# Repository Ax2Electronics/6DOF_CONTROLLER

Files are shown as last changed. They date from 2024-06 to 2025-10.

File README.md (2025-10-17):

# 6DOF_CONTROLLER
Carrier Board capable of driving up to 6 stepper motors, designed to drive 6 axis robot arm

Block Diagram
[BLOCK_DIAGRAM_V1.3.pdf](https://github.com/user-attachments/files/22972611/BLOCK_DIAGRAM_V1.3.pdf)



Power tree
[Robot Brain Current Consumption_V1.0.pdf](https://github.com/user-attachments/files/22972602/Robot.Brain.Current.Consumption_V1.0.pdf)



Schematic top overview:



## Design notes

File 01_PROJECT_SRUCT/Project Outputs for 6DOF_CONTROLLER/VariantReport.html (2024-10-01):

Altium customize

# Variant Report

Date: | | 6/29/2024
Time: | | 3:28:59 PM
Elapsed Time: | | 00:00:00

## Variations

Physical | Document | Parameter Name | Original Value | Only Populated Components
C3000 | 5V_SYS_SUPPLY.SchDoc | | Fitted | Fitted
| | capacitance | 0.1uF | 0.1uF
| | Comment | 0.1uF | 0.1uF
| | Component Kind | Standard | Standard
| | ComponentLink1Description | DigiKey | DigiKey
| | ComponentLink1URL | https://www.digikey.com/en/products/detail/samsung-electro-mechanics/CL10B104KB8NNNC/3886658 | https://www.digikey.com/en/products/detail/samsung-electro-mechanics/CL10B104KB8NNNC/3886658
| | Description | CAP CER 0.1UF 50V X7R 0603 | CAP CER 0.1UF 50V X7R 0603
| | DigiKey Part Number | 1276-1000-1-ND | 1276-1000-1-ND
| | Footprint | CAP_0603 | CAP_0603
| | Ibis Model
| | Library Name | CapacitorsIntegrated.IntLib | CapacitorsIntegrated.IntLib
| | Library Reference | C000018 | C000018
| | PCB3D
| | Pin Info
| | Signal Integrity
| | Simulation
C3001 | 5V_SYS_SUPPLY.SchDoc | | Fitted | Fitted
| | capaticanse | 220uf | 220uf
| | Comment | 220uf | 220uf
| | Component Kind | Standard | Standard
| | ComponentLink1Description | digikey | digikey
| | ComponentLink1URL | https://www.digikey.com/en/products/detail/nichicon/UCW1H221MNL1GS/2549783 | https://www.digikey.com/en/products/detail/nichicon/UCW1H221MNL1GS/2549783
| | Description | CAP ALUM 220UF 20% 50V SMD | CAP ALUM 220UF 20% 50V SMD
| | DigiKey part number | 493-9426-1-ND | 493-9426-1-ND
| | Footprint | CAPAE109103X103M | CAPAE109103X103M
| | Ibis Model
| | Library Name | CapacitorsIntegrated.IntLib | CapacitorsIntegrated.IntLib
| | Library Reference | C000019 | C000019
| | PCB3D
| | Pin Info
| | Signal Integrity
| | Simulation
C3002 | 5V_SYS_SUPPLY.SchDoc | | Fitted | Fitted
| | capacitance | 10uF | 10uF
| | Comment | 10uF | 10uF
| | Component Kind | Standard | Standard
| | ComponentLink1Description | DigiKey | DigiKey
| | ComponentLink1URL | https://www.digikey.com/en/products/detail/samsung-electro-mechanics/CL31B106KBHNNNE/5961251 | https://www.digikey.com/en/products/detail/samsung-electro-mechanics/CL31B106KBHNNNE/5961251
| | Description | CAP CER 10UF 50V X7R 1206 | CAP CER 10UF 50V X7R 1206
| | DigiKey Part Number | 1276-6767-1-ND | 1276-6767-1-ND
| | Footprint | CAP_1206 | CAP_1206
| | Ibis Model
| | Library Name | CapacitorsIntegrated.IntLib | CapacitorsIntegrated.IntLib
| | Library Reference | C000017 | C000017
| | PCB3D
| | Pin Info
| | Signal Integrity
| | Simulation
C3003 | 5V_SYS_SUPPLY.SchDoc | | Fitted | Fitted
| | capacitance | 10uF | 10uF
| | Comment | 10uF | 10uF
| | Component Kind | Standard | Standard
| | ComponentLink1Description | DigiKey | DigiKey
| | ComponentLink1URL | https://www.digikey.com/en/products/detail/samsung-electro-mechanics/CL31B106KBHNNNE/5961251 | https://www.digikey.com/en/products/detail/samsung-electro-mechanics/CL31B106KBHNNNE/5961251
| | Description | CAP CER 10UF 50V X7R 1206 | CAP CER 10UF 50V X7R 1206
| | DigiKey Part Number | 1276-6767-1-ND | 1276-6767-1-ND
| | Footprint | CAP_1206 | CAP_1206
| | Ibis Model
| | Library Name | CapacitorsIntegrated.IntLib | CapacitorsIntegrated.IntLib
| | Library Reference | C000017 | C000017
| | PCB3D
| | Pin Info
| | Signal Integrity
| | Simulation
C3004 | 5V_SYS_SUPPLY.SchDoc | | Fitted | Fitted
| | capacitance | 10uF | 10uF
| | Comment | 10uF | 10uF
| | Component Kind | Standard | Standard
| | ComponentLink1Description | DigiKey | DigiKey
| | ComponentLink1URL | https://www.digikey.com/en/products/detail/samsung-electro-mechanics/CL31B106KBHNNNE/5961251 | https://www.digikey.com/en/products/detail/samsung-electro-mechanics/CL31B106KBHNNNE/5961251
| | Description | CAP CER 10UF 50V X7R 1206 | CAP CER 10UF 50V X7R 1206
| | DigiKey Part Number | 1276-6767-1-ND | 1276-6767-1-ND
| | Footprint | CAP_1206 | CAP_1206
| | Ibis Model
| | Library Name | CapacitorsIntegrated.IntLib | CapacitorsIntegrated.IntLib
| | Library Reference | C000017 | C000017
| | PCB3D
| | Pin Info
| | Signal Integrity
| | Simulation
C3005 | 5V_SYS_SUPPLY.SchDoc | | Fitted | Fitted
| | capacitance | 0.1uF | 0.1uF
| | Comment | 0.1uF | 0.1uF
| | Component Kind | Standard | Standard
| | ComponentLink1Description | DigiKey | DigiKey
| | ComponentLink1URL | https://www.digikey.com/en/products/detail/samsung-electro-mechanics/CL10B104KB8NNNC/3886658 | https://www.digikey.com/en/products/detail/samsung-electro-mechanics/CL10B104KB8NNNC/3886658
| | Description | CAP CER 0.1UF 50V X7R 0603 | CAP CER 0.1UF 50V X7R 0603
| | DigiKey Part Number | 1276-1000-1-ND | 1276-1000-1-ND
| | Footprint | CAP_0603 | CAP_0603
| | Ibis Model
| | Library Name | CapacitorsIntegrated.IntLib | CapacitorsIntegrated.IntLib
| | Library Reference | C000018 | C000018
| | PCB3D
| | Pin Info
| | Signal Integrity
| | Simulation
C3006 | 5V_SYS_SUPPLY.SchDoc | | Fitted | Fitted
| | capacitance | 0.1uF | 0.1uF
| | Comment | 0.1uF | 0.1uF
| | Component Kind | Standard | Standard
| | ComponentLink1Description | DigiKey | DigiKey
| | ComponentLink1URL | https://www.digikey.com/en/products/detail/samsung-electro-mechanics/CL10B104KB8NNNC/3886658 | https://www.digikey.com/en/products/detail/samsung-electro-mechanics/CL10B104KB8NNNC/3886658
| | Description | CAP CER 0.1UF 50V X7R 0603 | CAP CER 0.1UF 50V X7R 0603
| | DigiKey Part Number | 1276-1000-1-ND | 1276-1000-1-ND
| | Footprint | CAP_0603 | CAP_0603
| | Ibis Model
| | Library Name | CapacitorsIntegrated.IntLib | CapacitorsIntegrated.IntLib
| | Library Reference | C000018 | C000018
| | PCB3D
| | Pin Info
| | Signal Integrity
| | Simulation
C3007 | 5V_SYS_SUPPLY.SchDoc | | Fitted | Fitted
| | capaticanse | 100nf | 100nf
| | Comment | 100nf | 100nf
| | Component Kind | Standard | Standard
| | ComponentLink1Description | digikey | digikey
| | ComponentLink1URL | https://www.digikey.com/en/products/detail/kyocera-avx/06033C104K4T2A/8019250 | https://www.digikey.com/en/products/detail/kyocera-avx/06033C104K4T2A/8019250
| | Description | CAP CER 100nF 0603 25V X7R | CAP CER 100nF 0603 25V X7R
| | Footprint | CAP_0603 | CAP_0603
| | Ibis Model
| | Library Name | CapacitorsIntegrated.IntLib | CapacitorsIntegrated.IntLib
| | Library Reference | C000007 | C000007
| | PCB3D
| | Pin Info
| | Signal Integrity
| | Simulation
C3008 | 5V_SYS_SUPPLY.SchDoc | | Fitted | Fitted
| | capaticanse | 100nf | 100nf
| | Comment | 100nf | 100nf
| | Component Kind | Standard | Standard
| | ComponentLink1Description | digikey | digikey
| | ComponentLink1URL | https://www.digikey.com/en/products/detail/kyocera-avx/06033C104K4T2A/8019250 | https://www.digikey.com/en/products/detail/kyocera-avx/06033C104K4T2A/8019250
| | Description | CAP CER 100nF 0603 25V X7R | CAP CER 100nF 0603 25V X7R
| | Footprint | CAP_0603 | CAP_0603
| | Ibis Model
| | Library Name | CapacitorsIntegrated.IntLib | CapacitorsIntegrated.IntLib
| | Library Reference | C000007 | C000007
| | PCB3D
| | Pin Info
| | Signal Integrity
| | Simulation
C3009 | 5V_SYS_SUPPLY.SchDoc | | Fitted | Fitted
| | capacitance | 22uF | 22uF
| | Comment | 22uF | 22uF
| | Component Kind | Standard | Standard
| | ComponentLink1Description | DigiKey | DigiKey
| | ComponentLink1URL | https://www.digikey.com/en/products/detail/samsung-electro-mechanics/CL31A226KAHNNNE/3888705 | https://www.digikey.com/en/products/detail/samsung-electro-mechanics/CL31A226KAHNNNE/3888705
| | Description | 22 µF ±10% 25V Ceramic Capacitor X5R 1206 (3216 Metric) | 22 µF ±10% 25V Ceramic Capacitor X5R 1206 (3216 Metric)
| | DigiKey Part Number | 1276-3047-1-ND | 1276-3047-1-ND
| | Footprint | CAP_1206 | CAP_1206
| | Ibis Model
| | Library Name | CapacitorsIntegrated.IntLib | CapacitorsIntegrated.IntLib
| | Library Reference | C000020 | C000020
| | PCB3D
| | Pin Info
| | Signal Integrity
| | Simulation
C3010 | 5V_SYS_SUPPLY.SchDoc | | Fitted | Fitted
| | capacitance | 22uF | 22uF
| | Comment | 22uF | 22uF
| | Component Kind | Standard | Standard
| | ComponentLink1Description | DigiKey | DigiKey
| | ComponentLink1URL | https://www.digikey.com/en/products/detail/samsung-electro-mechanics/CL31A226KAHNNNE/3888705 | https://www.digikey.com/en/products/detail/samsung-electro-mechanics/CL31A226KAHNNNE/3888705
| | Description | 22 µF ±10% 25V Ceramic Capacitor X5R 1206 (3216 Metric) | 22 µF ±10% 25V Ceramic Capacitor X5R 1206 (3216 Metric)
| | DigiKey Part Number | 1276-3047-1-ND | 1276-3047-1-ND
| | Footprint | CAP_1206 | CAP_1206
| | Ibis Model
| | Library Name | CapacitorsIntegrated.IntLib | CapacitorsIntegrated.IntLib
| | Library Reference | C000020 | C000020
| | PCB3D
| | Pin Info
| | Signal Integrity
| | Simulation
C3011 | 5V_SYS_SUPPLY.SchDoc | | Fitted | Fitted
| | capacitance | 22uF | 22uF
| | Comment | 22uF | 22uF
| | Component Kind | Standard | Standard
| | ComponentLink1Description | DigiKey | DigiKey
| | ComponentLink1URL | https://www.digikey.com/en/products/detail/samsung-electro-mechanics/CL31A226KAHNNNE/3888705 | https://www.digikey.com/en/products/detail/samsung-electro-mechanics/CL31A226KAHNNNE/3888705
| | Description | 22 µF ±10% 25V Ceramic Capacitor X5R 1206 (3216 Metric) | 22 µF ±10% 25V Ceramic Capacitor X5R 1206 (3216 Metric)
| | DigiKey Part Number | 1276-3047-1-ND | 1276-3047-1-ND
| | Footprint | CAP_1206 | CAP_1206
| | Ibis Model
| | Library Name | CapacitorsIntegrated.IntLib | CapacitorsIntegrated.IntLib
| | Library Reference | C000020 | C000020
| | PCB3D
| | Pin Info
| | Signal Integrity
| | Simulation
C3012 | 5V_SYS_SUPPLY.SchDoc | | Fitted | Fitted
| | capacitance | 22uF | 22uF
| | Comment | 22uF | 22uF
| | Component Kind | Standard | Standard
| | ComponentLink1Description | DigiKey | DigiKey
| | ComponentLink1URL | https://www.digikey.com/en/products/detail/samsung-electro-mechanics/CL31A226KAHNNNE/3888705 | https://www.digikey.com/en/products/detail/samsung-electro-mechanics/CL31A226KAHNNNE/3888705
| | Description | 22 µF ±10% 25V Ceramic Capacitor X5R 1206 (3216 Metric) | 22 µF ±10% 25V Ceramic Capacitor X5R 1206 (3216 Metric)
| | DigiKey Part Number | 1276-3047-1-ND | 1276-3047-1-ND
| | Footprint | CAP_1206 | CAP_1206
| | Ibis Model
| | Library Name | CapacitorsIntegrated.IntLib | CapacitorsIntegrated.IntLib
| | Library Reference | C000020 | C000020
| | PCB3D
| | Pin Info
| | Signal Integrity
| | Simulation
C3013 | 5V_SYS_SUPPLY.SchDoc | | Fitted | Fitted
| | capacitance | 82pF | 82pF
| | Comment | 82pF | 82pF
| | Component Kind | Standard | Standard
| | ComponentLink1Description | DigiKey | DigiKey
| | ComponentLink1URL | https://www.digikey.com/en/products/detail/kyocera-avx/KGM15ACG1E820FT/1599315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 | https://www.digikey.com/en/products/detail/kyocera-avx/KGM15ACG1E820FT/1599315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
| | Description | 82 pF ±1% 25V Ceramic Capacitor C0G, NP0 0603 (1608 Metric) | 82 pF ±1% 25V Ceramic Capacitor C0G, NP0 0603 (1608 Metric)
| | DigiKey Part Number | 478-KGM15ACG1E820FTCT-ND | 478-KGM15ACG1E820FTCT-ND
| | Footprint | CAP_0603 | CAP_0603
| | Ibis Model
| | Library Name | CapacitorsIntegrated.IntLib | CapacitorsIntegrated.IntLib
| | Library Reference | C000021 | C000021
| | PCB3D
| | Pin Info
| | Signal Integrity
| | Simulation
C3014 | 5V_SYS_SUPPLY.SchDoc | | Fitted | Fitted
| | capaticanse | 1uf | 1uf
| | Comment | 1uf | 1uf
| | Component Kind | Standard | Standard
| | ComponentLink1Description | digikey | digikey
| | ComponentLink1URL | https://www.digikey.com/en/products/detail/samsung-electro-mechanics/CL10B105KP8NNNC/3887604 | https://www.digikey.com/en/products/detail/samsung-electro-mechanics/CL10B105KP8NNNC/3887604
| | Description | CAP CER 1uF 10V X7R 0603 | CAP CER 1uF 10V X7R 0603
| | DigiKey part number | 1276-1946-2-ND | 1276-1946-2-ND
| | Footprint | CAP_0603 | CAP_0603
| | Ibis Model
| | Library Name | CapacitorsIntegrated.IntLib | CapacitorsIntegrated.IntLib
| | Library Reference | C000011 | C000011
| | PCB3D
| | Pin Info
| | Signal Integrity
| | Simulation
C3015 | 5V_SYS_SUPPLY.SchDoc | | Fitted | Fitted
| | capacitance | 0.1uF | 0.1uF
| | Comment | 0.1uF | 0.1uF
| | Component Kind | Standard | Standard
| | ComponentLink1Description | DigiKey | DigiKey
| | ComponentLink1URL | https://www.digikey.com/en/products/detail/samsung-electro-mechanics/CL10B104KB8NNNC/3886658 | https://www.digikey.com/en/products/detail/samsung-electro-mechanics/CL10B104KB8NNNC/3886658
| | Description | CAP CER 0.1UF 50V X7R 0603 | CAP CER 0.1UF 50V X7R 0603
| | DigiKey Part Number | 1276-1000-1-ND | 1276-1000-1-ND
| | Footprint | CAP_0603 | CAP_0603
| | Ibis Model
| | Library Name | CapacitorsIntegrated.IntLib | CapacitorsIntegrated.IntLib
| | Library Reference | C000018 | C000018
| | PCB3D
| | Pin Info
| | Signal Integrity
| | Simulation
C3016 | 5V_SYS_SUPPLY.SchDoc | | Fitted | Fitted
| | capacitance | 0.1uF | 0.1uF
| | Comment | 0.1uF | 0.1uF
| | Component Kind | Standard | Standard
| | ComponentLink1Description | DigiKey | DigiKey
| | ComponentLink1URL | https://www.digikey.com/en/products/detail/samsung-electro-mechanics/CL10B104KB8NNNC/3886658 | https://www.digikey.com/en/products/detail/samsung-electro-mechanics/CL10B104KB8NNNC/3886658
| | Description | CAP CER 0.1UF 50V X7R 0603 | CAP CER 0.1UF 50V X7R 0603
| | DigiKey Part Number | 1276-1000-1-ND | 1276-1000-1-ND
| | Footprint | CAP_0603 | CAP_0603
| | Ibis Model
| | Library Name | CapacitorsIntegrated.IntLib | CapacitorsIntegrated.IntLib
| | Library Reference | C000018 | C000018
| | PCB3D
| | Pin Info
| | Signal Integrity
| | Simulation
C3017 | 5V_SYS_SUPPLY.SchDoc | | Fitted | Fitted
| | capacitance | 0.1uF | 0.1uF
| | Comment | 0.1uF | 0.1uF
| | Component Kind | Standard | Standard
| | ComponentLink1Description | DigiKey | DigiKey
| | ComponentLink1URL | https://www.digikey.com/en/products/detail/samsung-electro-mechanics/CL10B104KB8NNNC/3886658 | https://www.digikey.com/en/products/detail/samsung-electro-mechanics/CL10B104KB8NNNC/3886658
| | Description | CAP CER 0.1UF 50V X7R 0603 | CAP CER 0.1UF 50V X7R 0603
| | DigiKey Part Number | 1276-1000-1-ND | 1276-1000-1-ND
| | Footprint | CAP_0603 | CAP_0603
| | Ibis Model
| | Library Name | CapacitorsIntegrated.IntLib | CapacitorsIntegrated.IntLib
| | Library Reference | C000018 | C000018
| | PCB3D
| | Pin Info
| | Signal Integrity
| | Simulation
C4000 | 3V3_SYS_SUPPLY.SchDoc | | Fitted | Fitted
| | capaticanse | 10uf | 10uf
| | Comment | 10uf | 10uf
| | Component Kind | Standard | Standard
| | ComponentLink1Description | digikey | digikey
| | ComponentLink1URL | https://www.digikey.com/en/products/detail/tdk-corporation/C2012X5R1E106K125AB/2443462 | https://www.digikey.com/en/products/detail/tdk-corporation/C2012X5R1E106K125AB/2443462
| | Description | CAP CER 10uF 0805 25V X5R | CAP CER 10uF 0805 25V X5R
| | Footprint | CAP_0805 | CAP_0805
| | Ibis Model
| | Library Name | CapacitorsIntegrated.IntLib | CapacitorsIntegrated.IntLib
| | Library Reference | C000002 | C000002
| | PCB3D
| | Pin Info
| | Signal Integrity
| | Simulation
C4001 | 3V3_SYS_SUPPLY.SchDoc | | Fitted | Fitted
| | capaticanse | 10uf | 10uf
| | Comment | 10uf | 10uf
| | Component Kind | Standard | Standard
| | ComponentLink1Description | digikey | digikey
| | ComponentLink1URL | https://www.digikey.com/en/products/detail/tdk-corporation/C2012X5R1E106K125AB/2443462 | https://www.digikey.com/en/products/detail/tdk-corporation/C2012X5R1E106K125AB/2443462
| | Description | CAP CER 10uF 0805 25V X5R | CAP CER 10uF 0805 25V X5R
| | Footprint | CAP_0805 | CAP_0805
| | Ibis Model
| | Library Name | CapacitorsIntegrated.IntLib | CapacitorsIntegrated.IntLib
| | Library Reference | C000002 | C000002
| | PCB3D
| | Pin Info
| | Signal Integrity
| | Simulation
C4002 | 3V3_SYS_SUPPLY.SchDoc | | Fitted | Fitted
| | capaticanse | 100nf | 100nf
| | Comment | 100nf | 100nf
| | Component Kind | Standard | Standard
| | ComponentLink1Description | digikey | digikey
| | ComponentLink1URL | https://www.digikey.com/en/products/detail/kyocera-avx/06033C104K4T2A/8019250 | https://www.digikey.com/en/products/detail/kyocera-avx/06033C104K4T2A/8019250
| | Description | CAP CER 100nF 0603 25V X7R | CAP CER 100nF 0603 25V X7R
| | Footprint | CAP_0603 | CAP_0603
| | Ibis Model
| | Library Name | CapacitorsIntegrated.IntLib | CapacitorsIntegrated.IntLib
| | Library Reference | C000007 | C000007
| | PCB3D
| | Pin Info
| | Signal Integrity
| | Simulation
C4003 | 3V3_SYS_SUPPLY.SchDoc | | Fitted | Fitted
| | capaticanse | 100nf | 100nf
| | Comment | 100nf | 100nf
| | Component Kind | Standard | Standard
| | ComponentLink1Description | digikey | digikey
| | ComponentLink1URL | https://www.digikey.com/en/products/detail/kyocera-avx/06033C104K4T2A/8019250 | https://www.digikey.com/en/products/detail/kyocera-avx/06033C104K4T2A/8019250
| | Description | CAP CER 100nF 0603 25V X7R | CAP CER 100nF 0603 25V X7R
| | Footprint | CAP_0603 | CAP_0603
| | Ibis Model
| | Library Name | CapacitorsIntegrated.IntLib | CapacitorsIntegrated.IntLib
| | Library Reference | C000007 | C000007
| | PCB3D
| | Pin Info
| | Signal Integrity
| | Simulation
C4004 | 3V3_SYS_SUPPLY.SchDoc | | Fitted | Fitted
| | capaticanse | 100nf | 100nf
| | Comment | 100nf | 100nf
| | Component Kind | Standard | Standard
| | ComponentLink1Description | digikey | digikey
| | ComponentLink1URL | https://www.digikey.com/en/products/detail/kyocera-avx/06033C104K4T2A/8019250 | https://www.digikey.com/en/products/detail/kyocera-avx/06033C104K4T2A/8019250
| | Description | CAP CER 100nF 0603 25V X7R | CAP CER 100nF 0603 25V X7R
| | Footprint | CAP_0603 | CAP_0603
| | Ibis Model
| | Library Name | CapacitorsIntegrated.IntLib | CapacitorsIntegrated.IntLib
| | Library Reference | C000007 | C000007
| | PCB3D
| | Pin Info
| | Signal Integrity
| | Simulation
C4005 | 3V3_SYS_SUPPLY.SchDoc | | Fitted | Fitted
| | capaticanse | 22uf | 22uf
| | Comment | 22uf | 22uf
| | Component Kind | Standard | Standard
| | ComponentLink1Description | digikey | digikey
| | ComponentLink1URL | https://www.digikey.com/en/products/detail/tdk-corporation/C2012X5R1E226M125AC/3661564 | https://www.digikey.com/en/products/detail/tdk-corporation/C2012X5R1E226M125AC/3661564
| | Description | CAP CER 22uF 0805 25V X5R | CAP CER 22uF 0805 25V X5R
| | Footprint | CAP_0805 | CAP_0805
| | Ibis Model
| | Library Name | CapacitorsIntegrated.IntLib | CapacitorsIntegrated.IntLib
| | Library Reference | C000001 | C000001
| | PCB3D
| | Pin Info
| | Signal Integrity
| | Simulation
C4006 | 3V3_SYS_SUPPLY.SchDoc | | Fitted | Fitted
| | capaticanse | 22uf | 22uf
| | Comment | 22uf | 22uf
| | Component Kind | Standard | Standard
| | ComponentLink1Description | digikey | digikey
| | ComponentLink1URL | https://www.digikey.com/en/products/detail/tdk-corporation/C2012X5R1E226M125AC/3661564 | https://www.digikey.com/en/products/detail/tdk-corporation/C2012X5R1E226M125AC/3661564
| | Description | CAP CER 22uF 0805 25V X5R | CAP CER 22uF 0805 25V X5R
| | Footprint | CAP_0805 | CAP_0805
| | Ibis Model
| | Library Name | CapacitorsIntegrated.IntLib | CapacitorsIntegrated.IntLib
| | Library Reference | C000001 | C000001
| | PCB3D
| | Pin Info
| | Signal Integrity
| | Simulation
C4007 | 3V3_SYS_SUPPLY.SchDoc | | Fitted | Fitted
| | capacitance | 6.8nF | 6.8nF
| | Comment | 6.8nF | 6.8nF
| | Component Kind | Standard | Standard
| | ComponentLink1Description | DigiKey | DigiKey
| | ComponentLink1URL | https://www.digikey.com/en/products/detail/yageo/CC0603KRX7R8BB682/5883791 | https://www.digikey.com/en/products/detail/yageo/CC0603KRX7R8BB682/5883791
| | Description | 6800 pF ±10% 25V Ceramic Capacitor X7R 0603 (1608 Metric) | 6800 pF ±10% 25V Ceramic Capacitor X7R 0603 (1608 Metric)
| | DigiKey Part Number | 311-4090-1-ND | 311-4090-1-ND
| | Footprint | CAP_0603 | CAP_0603
| | Ibis Model
| | Library Name | CapacitorsIntegrated.IntLib | CapacitorsIntegrated.IntLib
| | Library Reference | C000023 | C000023
| | PCB3D
| | Pin Info
| | Signal Integrity
| | Simulation
C4008 | 3V3_SYS_SUPPLY.SchDoc | | Fitted | Fitted
| | capaticanse | 2.2nf | 2.2nf
| | Comment | 2.2nf | 2.2nf
| | Component Kind | Standard | Standard
| | ComponentLink1Description | digikey | digikey
| | ComponentLink1URL | https://www.digikey.com/en/products/detail/yageo/CC0603KRX7R8BB222/2345066 | https://www.digikey.com/en/products/detail/yageo/CC0603KRX7R8BB222/2345066
| | Description | CAP CER 2.2nF 0603 25V X7R | CAP CER 2.2nF 0603 25V X7R
| | Footprint | CAP_0603 | CAP_0603
| | Ibis Model
| | Library Name | CapacitorsIntegrated.IntLib | CapacitorsIntegrated.IntLib
| | Library Reference | C000006 | C000006
| | PCB3D
| | Pin Info
| | Signal Integrity
| | Simulation
C5000 | 5V0_EXT_SUPPLY.SchDoc | | Fitted | Fitted
| | capaticanse | 10uf | 10uf
| | Comment | 10uf | 10uf
| | Component Kind | Standard | Standard
| | ComponentLink1Description | digikey | digikey
| | ComponentLink1URL | https://www.digikey.com/en/products/detail/tdk-corporation/C2012X5R1E106K125AB/2443462 | https://www.digikey.com/en/products/detail/tdk-corporation/C2012X5R1E106K125AB/2443462
| | Description | CAP CER 10uF 0805 25V X5R | CAP CER 10uF 0805 25V X5R
| | Footprint | CAP_0805 | CAP_0805
| | Ibis Model
| | Library Name | CapacitorsIntegrated.IntLib | CapacitorsIntegrated.IntLib
| | Library Reference | C000002 | C000002
| | PCB3D
| | Pin Info
| | Signal Integrity
| | Simulation
C5001 | 5V0_EXT_SUPPLY.SchDoc | | Fitted | Fitted
| | capaticanse | 10uf | 10uf
| | Comment | 10uf | 10uf
| | Component Kind | Standard | Standard
| | ComponentLink1Description | digikey | digikey
| | ComponentLink1URL | https://www.digikey.com/en/products/detail/tdk-corporation/C2012X5R1E106K125AB/2443462 | https://www.digikey.com/en/products/detail/tdk-corporation/C2012X5R1E106K125AB/2443462
| | Description | CAP CER 10uF 0805 25V X5R | CAP CER 10uF 0805 25V X5R
| | Footprint | CAP_0805 | CAP_0805
| | Ibis Model
| | Library Name | CapacitorsIntegrated.IntLib | CapacitorsIntegrated.IntLib
| | Library Reference | C000002 | C000002
| | PCB3D
| | Pin Info
| | Signal Integrity
| | Simulation
C5002 | 5V0_EXT_SUPPLY.SchDoc | | Fitted | Fitted
| | capaticanse | 100nf | 100nf
| | Comment | 100nf | 100nf
| | Component Kind | Standard | Standard
| | ComponentLink1Description | digikey | digikey
| | ComponentLink1URL | https://www.digikey.com/en/products/detail/kyocera-avx/06033C104K4T2A/8019250 | https://www.digikey.com/en/products/detail/kyocera-avx/06033C104K4T2A/8019250
| | Description | CAP CER 100nF 0603 25V X7R | CAP CER 100nF 0603 25V X7R
| | Footprint | CAP_0603 | CAP_0603
| | Ibis Model
| | Library Name | CapacitorsIntegrated.IntLib | CapacitorsIntegrated.IntLib
| | Library Reference | C000007 | C000007
| | PCB3D
| | Pin Info
| | Signal Integrity
| | Simulation
C5003 | 5V0_EXT_SUPPLY.SchDoc | | Fitted | Fitted
| | capaticanse | 100nf | 100nf
| | Comment | 100nf | 100nf
| | Component Kind | Standard | Standard
| | ComponentLink1Description | digikey | digikey
| | ComponentLink1URL | https://www.digikey.com/en/products/detail/kyocera-avx/06033C104K4T2A/8019250 | https://www.digikey.com/en/products/detail/kyocera-avx/06033C104K4T2A/8019250
| | Description | CAP CER 100nF 0603 25V X7R | CAP CER 100nF 0603 25V X7R
| | Footprint | CAP_0603 | CAP_0603
| | Ibis Model
| | Library Name | CapacitorsIntegrated.IntLib | CapacitorsIntegrated.IntLib
| | Library Reference | C000007 | C000007
| | PCB3D
| | Pin Info
| | Signal Integrity
| | Simulation
C5004 | 5V0_EXT_SUPPLY.SchDoc | | Fitted | Fitted
| | capaticanse | 100nf | 100nf
| | Comment | 100nf | 100nf
| | Component Kind | Standard | Standard
| | ComponentLink1Description | digikey | digikey
| | ComponentLink1URL | https://www.digikey.com/en/products/detail/kyocera-avx/06033C104K4T2A/8019250 | https://www.digikey.com/en/products/detail/kyocera-avx/06033C104K4T2A/8019250
| | Description | CAP CER 100nF 0603 25V X7R | CAP CER 100nF 0603 25V X7R
| | Footprint | CAP_0603 | CAP_0603
| | Ibis Model
| | Library Name | CapacitorsIntegrated.IntLib | CapacitorsIntegrated.IntLib
| | Library Reference | C000007 | C000007
| | PCB3D
| | Pin Info
| | Signal Integrity
| | Simulation
C5005 | 5V0_EXT_SUPPLY.SchDoc | | Fitted | Fitted
| | capaticanse | 22uf | 22uf
| | Comment | 22uf | 22uf
| | Component Kind | Standard | Standard
| | ComponentLink1Description | digikey | digikey
| | ComponentLink1URL | https://www.digikey.com/en/products/detail/tdk-corporation/C2012X5R1E226M125AC/3661564 | https://www.digikey.com/en/products/detail/tdk-corporation/C2012X5R1E226M125AC/3661564
| | Description | CAP CER 22uF 0805 25V X5R | CAP CER 22uF 0805 25V X5R
| | Footprint | CAP_0805 | CAP_0805
| | Ibis Model
| | Library Name | CapacitorsIntegrated.IntLib | CapacitorsIntegrated.IntLib
| | Library Reference | C000001 | C000001
| | PCB3D
| | Pin Info
| | Signal Integrity
| | Simulation
C5006 | 5V0_EXT_SUPPLY.SchDoc | | Fitted | Fitted
| | capaticanse | 22uf | 22uf
| | Comment | 22uf | 22uf
| | Component Kind | Standard | Standard
| | ComponentLink1Description | digikey | digikey
| | ComponentLink1URL | https://www.digikey.com/en/products/detail/tdk-corporation/C2012X5R1E226M125AC/3661564 | https://www.digikey.com/en/products/detail/tdk-corporation/C2012X5R1E226M125AC/3661564
| | Description | CAP CER 22uF 0805 25V X5R | CAP CER 22uF 0805 25V X5R
| | Footprint | CAP_0805 | CAP_0805
| | Ibis Model
| | Library Name | CapacitorsIntegrated.IntLib | CapacitorsIntegrated.IntLib
| | Library Reference | C000001 | C000001
| | PCB3D
| | Pin Info
| | Signal Integrity
| | Simulation
C5007 | 5V0_EXT_SUPPLY.SchDoc | | Fitted | Fitted
| | capaticanse | 22uf | 22uf
| | Comment | 22uf | 22uf
| | Component Kind | Standard | Standard
| | ComponentLink1Description | digikey | digikey
| | ComponentLink1URL | https://www.digikey.com/en/products/detail/tdk-corporation/C2012X5R1E226M125AC/3661564 | https://www.digikey.com/en/products/detail/tdk-corporation/C2012X5R1E226M125AC/3661564
| | Description | CAP CER 22uF 0805 25V X5R | CAP CER 22uF 0805 25V X5R
| | Footprint | CAP_0805 | CAP_0805
| | Ibis Model
| | Library Name | CapacitorsIntegrated.IntLib | CapacitorsIntegrated.IntLib
| | Library Reference | C000001 | C000001
| | PCB3D
| | Pin Info
| | Signal Integrity
| | Simulation
C5008 | 5V0_EXT_SUPPLY.SchDoc | | Fitted | Fitted
| | capaticanse | 22uf | 22uf
| | Comment | 22uf | 22uf
| | Component Kind | Standard | Standard
| | ComponentLink1Description | digikey | digikey
| | ComponentLink1URL | https://www.digikey.com/en/products/detail/tdk-corporation/C2012X5R1E226M125AC/3661564 | https://www.digikey.com/en/products/detail/tdk-corporation/C2012X5R1E226M125AC/3661564
| | Description | CAP CER 22uF 0805 25V X5R | CAP CER 22uF 0805 25V X5R
| | Footprint | CAP_0805 | CAP_0805
| | Ibis Model
| | Library Name | CapacitorsIntegrated.IntLib | CapacitorsIntegrated.IntLib
| | Library Reference | C000001 | C000001
| | PCB3D
| | Pin Info
| | Signal Integrity
| | Simulation
C5009 | 5V0_EXT_SUPPLY.SchDoc | | Fitted | Fitted
| | capacitance | 6.8nF | 6.8nF
| | Comment | 6.8nF | 6.8nF
| | Component Kind | Standard | Standard
| | ComponentLink1Description | DigiKey | DigiKey
| | ComponentLink1URL | https://www.digikey.com/en/products/detail/yageo/CC0603KRX7R8BB682/5883791 | https://www.digikey.com/en/products/detail/yageo/CC0603KRX7R8BB682/5883791
| | Description | 6800 pF ±10% 25V Ceramic Capacitor X7R 0603 (1608 Metric) | 6800 pF ±10% 25V Ceramic Capacitor X7R 0603 (1608 Metric)
| | DigiKey Part Number | 311-4090-1-ND | 311-4090-1-ND
| | Footprint | CAP_0603 | CAP_0603
| | Ibis Model
| | Library Name | CapacitorsIntegrated.IntLib | CapacitorsIntegrated.IntLib
| | Library Reference | C000023 | C000023
| | PCB3D
| | Pin Info
| | Signal Integrity
| | Simulation
C5010 | 5V0_EXT_SUPPLY.SchDoc | | Fitted | Fitted
| | capaticanse | 2.2nf | 2.2nf
| | Comment | 2.2nf | 2.2nf
| | Component Kind | Standard | Standard
| | ComponentLink1Description | digikey | digikey
| | ComponentLink1URL | https://www.digikey.com/en/products/detail/yageo/CC0603KRX7R8BB222/2345066 | https://www.digikey.com/en/products/detail/yageo/CC0603KRX7R8BB222/2345066
| | Description | CAP CER 2.2nF 0603 25V X7R | CAP CER 2.2nF 0603 25V X7R
| | Footprint | CAP_0603 | CAP_0603
| | Ibis Model
| | Library Name | CapacitorsIntegrated.IntLib | CapacitorsIntegrated.IntLib
| | Library Reference | C000006 | C000006
| | PCB3D
| | Pin Info
| | Signal Integrity
| | Simulation
C6000 | 3V3_MCU_SUPPLY.SchDoc | | Fitted | Fitted
| | capaticanse | 220uF | 220uF
| | Comment | 220uF | 220uF
| | Component Kind | Standard | Standard
| | ComponentLink1Description | digikey | digikey
| | ComponentLink1URL | https://www.digikey.com/en/products/detail/kemet/A765KN227M1ALAE020/6196558 | https://www.digikey.com/en/products/detail/kemet/A765KN227M1ALAE020/6196558
| | Description | 220 µF 10 V Aluminum - Polymer Capacitors Radial, Can - SMD 20mOhm 2000 Hrs @ 105°C | 220 µF 10 V Aluminum - Polymer Capacitors Radial, Can - SMD 20mOhm 2000 Hrs @ 105°C
| | DigiKey part number | 399-A765KN227M1ALAE020CT-ND | 399-A765KN227M1ALAE020CT-ND
| | Footprint | CAPAE9083X100M | CAPAE9083X100M
| | Ibis Model
| | Library Name | CapacitorsIntegrated.IntLib | CapacitorsIntegrated.IntLib
| | Library Reference | C000025 | C000025
| | PCB3D
| | Pin Info
| | Signal Integrity
| | Simulation
C6001 | 3V3_MCU_SUPPLY.SchDoc | | Fitted | Fitted
| | capaticanse | 10uf | 10uf
| | Comment | 10uf | 10uf
| | Component Kind | Standard | Standard
| | ComponentLink1Description | digikey | digikey
| | ComponentLink1URL | https://www.digikey.com/en/products/detail/tdk-corporation/C2012X5R1E106K125AB/2443462 | https://www.digikey.com/en/products/detail/tdk-corporation/C2012X5R1E106K125AB/2443462
| | Description | CAP CER 10uF 0805 25V X5R | CAP CER 10uF 0805 25V X5R
| | Footprint | CAP_0805 | CAP_0805
| | Ibis Model
| | Library Name | CapacitorsIntegrated.IntLib | CapacitorsIntegrated.IntLib
| | Library Reference | C000002 | C000002
| | PCB3D
| | Pin Info
| | Signal Integrity
| | Simulation
C6002 | 3V3_MCU_SUPPLY.SchDoc | | Fitted | Fitted
| | capaticanse | 10uf | 10uf
| | Comment | 10uf | 10uf
| | Component Kind | Standard | Standard
| | ComponentLink1Description | digikey | digikey
| | ComponentLink1URL | https://www.digikey.com/en/products/detail/tdk-corporation/C2012X5R1E106K125AB/2443462 | https://www.digikey.com/en/products/detail/tdk-corporation/C2012X5R1E106K125AB/2443462
| | Description | CAP CER 10uF 0805 25V X5R | CAP CER 10uF 0805 25V X5R
| | Footprint | CAP_0805 | CAP_0805
| | Ibis Model
| | Library Name | CapacitorsIntegrated.IntLib | CapacitorsIntegrated.IntLib
| | Library Reference | C000002 | C000002
| | PCB3D
| | Pin Info
| | Signal Integrity
| | Simulation
C6003 | 3V3_MCU_SUPPLY.SchDoc | | Fitted | Fitted
| | capaticanse | 100nf | 100nf
| | Comment | 100nf | 100nf
| | Component Kind | Standard | Standard
| | ComponentLink1Description | digikey | digikey
| | ComponentLink1URL | https://www.digikey.com/en/products/detail/kyocera-avx/06033C104K4T2A/8019250 | https://www.digikey.com/en/products/detail/kyocera-avx/06033C104K4T2A/8019250
| | Description | CAP CER 100nF 0603 25V X7R | CAP CER 100nF 0603 25V X7R
| | Footprint | CAP_0603 | CAP_0603
| | Ibis Model
| | Library Name | CapacitorsIntegrated.IntLib | CapacitorsIntegrated.IntLib
| | Library Reference | C000007 | C000007
| | PCB3D
| | Pin Info
| | Signal Integrity
| | Simulation
C6004 | 3V3_MCU_SUPPLY.SchDoc | | Fitted | Fitted
| | capaticanse | 100nf | 100nf
| | Comment | 100nf | 100nf
| | Component Kind | Standard | Standard
| | ComponentLink1Description | digikey | digikey
| | ComponentLink1URL | https://www.digikey.com/en/products/detail/kyocera-avx/06033C104K4T2A/8019250 | https://www.digikey.com/en/products/detail/kyocera-avx/06033C104K4T2A/8019250
| | Description | CAP CER 100nF 0603 25V X7R | CAP CER 100nF 0603 25V X7R
| | Footprint | CAP_0603 | CAP_0603
| | Ibis Model
| | Library Name | CapacitorsIntegrated.IntLib | CapacitorsIntegrated.IntLib
| | Library Reference | C000007 | C000007
| | PCB3D
| | Pin Info
| | Signal Integrity
| | Simulation
C6005 | 3V3_MCU_SUPPLY.SchDoc | | Fitted | Fitted
| | capaticanse | 10uf | 10uf
| | Comment | 10uf | 10uf
| | Component Kind | Standard | Standard
| | ComponentLink1Description | digikey | digikey
| | ComponentLink1URL | https://www.digikey.com/en/products/detail/tdk-corporation/C2012X5R1E106K125AB/2443462 | https://www.digikey.com/en/products/detail/tdk-corporation/C2012X5R1E106K125AB/2443462
| | Description | CAP CER 10uF 0805 25V X5R | CAP CER 10uF 0805 25V X5R
| | Footprint | CAP_0805 | CAP_0805
| | Ibis Model
| | Library Name | CapacitorsIntegrated.IntLib | CapacitorsIntegrated.IntLib
| | Library Reference | C000002 | C000002
| | PCB3D
| | Pin Info
| | Signal Integrity
| | Simulation
C6006 | 3V3_MCU_SUPPLY.SchDoc | | Fitted | Fitted
| | capaticanse | 10uf | 10uf
| | Comment | 10uf | 10uf
| | Component Kind | Standard | Standard
| | ComponentLink1Description | digikey | digikey
| | ComponentLink1URL | https://www.digikey.com/en/products/detail/tdk-corporation/C2012X5R1E106K125AB/2443462 | https://www.digikey.com/en/products/detail/tdk-corporation/C2012X5R1E106K125AB/2443462
| | Description | CAP CER 10uF 0805 25V X5R | CAP CER 10uF 0805 25V X5R
| | Footprint | CAP_0805 | CAP_0805
| | Ibis Model
| | Library Name | CapacitorsIntegrated.IntLib | CapacitorsIntegrated.IntLib
| | Library Reference | C000002 | C000002
| | PCB3D
| | Pin Info
| | Signal Integrity
| | Simulation
C6007 | 3V3_MCU_SUPPLY.SchDoc | | Fitted | Fitted
| | capaticanse | 22uf | 22uf
| | Comment | 22uf | 22uf
| | Component Kind | Standard | Standard
| | ComponentLink1Description | digikey | digikey
| | ComponentLink1URL | https://www.digikey.com/en/products/detail/tdk-corporation/C2012X5R1E226M125AC/3661564 | https://www.digikey.com/en/products/detail/tdk-corporation/C2012X5R1E226M125AC/3661564
| | Description | CAP CER 22uF 0805 25V X5R | CAP CER 22uF 0805 25V X5R
| | Footprint | CAP_0805 | CAP_0805
| | Ibis Model
| | Library Name | CapacitorsIntegrated.IntLib | CapacitorsIntegrated.IntLib
| | Library Reference | C000001 | C000001
| | PCB3D
| | Pin Info
| | Signal Integrity
| | Simulation
C6008 | 3V3_MCU_SUPPLY.SchDoc | | Fitted | Fitted
| | capacitance | 22pF | 22pF
| | Comment | 22pF | 22pF
| | Component Kind | Standard | Standard
| | ComponentLink1Description | DigiKey | DigiKey
| | ComponentLink1URL | https://www.digikey.com/en/products/detail/kemet/C0603C220K3RACAUTO/16524857 | https://www.digikey.com/en/products/detail/kemet/C0603C220K3RACAUTO/16524857
| | Description | 22 pF ±10% 25V Ceramic Capacitor X7R 0603 (1608 Metric) | 22 pF ±10% 25V Ceramic Capacitor X7R 0603 (1608 Metric)
| | DigiKey Part Number | 399-C0603C220K3RACAUTOCT-ND | 399-C0603C220K3RACAUTOCT-ND
| | Footprint | CAP_0603 | CAP_0603
| | Ibis Model
| | Library Name | CapacitorsIntegrated.IntLib | CapacitorsIntegrated.IntLib
| | Library Reference | C000024 | C000024
| | PCB3D
| | Pin Info
| | Signal Integrity
| | Simulation
C6009 | 3V3_MCU_SUPPLY.SchDoc | | Fitted | Fitted
| | capaticanse | 10nf | 10nf
| | Comment | 10nf | 10nf
| | Component Kind | Standard | Standard
| | ComponentLink1Description | digikey | digikey
| | ComponentLink1URL | https://www.digikey.com/en/products/detail/kyocera-avx/06033C103MAT2A/1599370 | https://www.digikey.com/en/products/detail/kyocera-avx/06033C103MAT2A/1599370
| | Description | CAP CER 10nF 0603 25V X7R | CAP CER 10nF 0603 25V X7R
| | Footprint | CAP_0603 | CAP_0603
| | Ibis Model
| | Library Name | CapacitorsIntegrated.IntLib | CapacitorsIntegrated.IntLib
| | Library Reference | C000005 | C000005
| | PCB3D
| | Pin Info
| | Signal Integrity
| | Simulation
IC3000 | 5V_SYS_SUPPLY.SchDoc | | Fitted | Fitted
| | Comment | LMR33630ARNXR | LMR33630ARNXR
| | Component Kind | Standard | Standard
| | ComponentLink1Description | DigiKey | DigiKey
| | ComponentLink1URL | https://www.digikey.com/en/products/detail/texas-instruments/LMR33630ARNXR/9356577 | https://www.digikey.com/en/products/detail/texas-instruments/LMR33630ARNXR/9356577
| | ComponentLink2Description | Mouser | Mouser
| | ComponentLink2URL | https://eu.mouser.com/ProductDetail/Texas-Instruments/LMR33630ARNXR?qs=55YtniHzbhBobt6bGtLStw%3D%3D | https://eu.mouser.com/ProductDetail/Texas-Instruments/LMR33630ARNXR?qs=55YtniHzbhBobt6bGtLStw%3D%3D
| | Description | Buck Switching Regulator IC Positive Adjustable 1V 1 Output 3A 12-VFQFN | Buck Switching Regulator IC Positive Adjustable 1V 1 Output 3A 12-VFQFN
| | DigiKey Part Number | 296-49764-1-ND | 296-49764-1-ND
| | Footprint | VQFN-HR | VQFN-HR
| | Ibis Model
| | Library Name | IntegratedCircuits.IntLib | IntegratedCircuits.IntLib
| | Library Reference | LMR33630ARNXR | LMR33630ARNXR
| | Mouser Part Number | 595-LMR33630ARNXR | 595-LMR33630ARNXR
| | PCB3D
| | Pin Info
| | Signal Integrity
| | Simulation
IC3001 | 5V_SYS_SUPPLY.SchDoc | | Fitted | Fitted
| | Comment | LTC2955-1 | LTC2955-1
| | Component Kind | Standard | Standard
| | ComponentLink1Description | DigiKey | DigiKey
| | ComponentLink1URL | https://www.digikey.com/en/products/detail/analog-devices-inc/LTC2955CTS8-1-TRMPBF/3065178 | https://www.digikey.com/en/products/detail/analog-devices-inc/LTC2955CTS8-1-TRMPBF/3065178
| | ComponentLink2Description | Mouser | Mouser
| | ComponentLink2URL | https://eu.mouser.com/ProductDetail/Analog-Devices/LTC2955CTS8-1TRMPBF?qs=hVkxg5c3xu%252B6Fq1Ir3bkGg%3D%3D | https://eu.mouser.com/ProductDetail/Analog-Devices/LTC2955CTS8-1TRMPBF?qs=hVkxg5c3xu%252B6Fq1Ir3bkGg%3D%3D
| | Description | Power Supply Controller Push Button, On/Off Controller TSOT-23-8 | Power Supply Controller Push Button, On/Off Controller TSOT-23-8
| | DigiKey Part Number | 505-LTC2955CTS8-1#TRMPBFCT-ND | 505-LTC2955CTS8-1#TRMPBFCT-ND
| | Footprint | TSOP65P280X100-8N | TSOP65P280X100-8N
| | Ibis Model
| | Library Name | IntegratedCircuits.IntLib | IntegratedCircuits.IntLib
| | Library Reference | LTC2955-1 | LTC2955-1
| | Mouser Part Number | 584-C2955CTS8-1TMPF | 584-C2955CTS8-1TMPF
| | PCB3D
| | Pin Info
| | Signal Integrity
| | Simulation
IC4000 | 3V3_SYS_SUPPLY.SchDoc | | Fitted | Fitted
| | Comment | TPS62142RGT-3V3 | TPS62142RGT-3V3
| | Component Kind | Standard | Standard
| | ComponentLink1Description | DigiKey | DigiKey
| | ComponentLink1URL | https://www.digikey.com/en/products/detail/texas-instruments/TPS62142RGTT/2786730 | https://www.digikey.com/en/products/detail/texas-instruments/TPS62142RGTT/2786730
| | ComponentLink2Description | Mouser | Mouser
| | ComponentLink2URL | https://eu.mouser.com/ProductDetail/Texas-Instruments/TPS62142RGTT?qs=gXEV9p%2FxLgdBrEoz0pTJSA%3D%3D | https://eu.mouser.com/ProductDetail/Texas-Instruments/TPS62142RGTT?qs=gXEV9p%2FxLgdBrEoz0pTJSA%3D%3D
| | Description | Buck Switching Regulator IC Positive Fixed 3.3V 1 Output 2A 16-VFQFN Exposed Pad | Buck Switching Regulator IC Positive Fixed 3.3V 1 Output 2A 16-VFQFN Exposed Pad
| | DigiKey Part Number | 296-29940-1-ND | 296-29940-1-ND
| | Footprint | QFN50P300X300X100_HS-17N | QFN50P300X300X100_HS-17N
| | Ibis Model
| | Library Name | IntegratedCircuits.IntLib | IntegratedCircuits.IntLib
| | Library Reference | TPS62142RGT | TPS62142RGT
| | Mouser Part Number | 595-TPS62142RGTT | 595-TPS62142RGTT
| | PCB3D
| | Pin Info
| | Signal Integrity
| | Simulation
IC5000 | 5V0_EXT_SUPPLY.SchDoc | | Fitted | Fitted
| | Comment | TPS62143RGTR-5V0 | TPS62143RGTR-5V0
| | Component Kind | Standard | Standard
| | ComponentLink1Description | DigiKey | DigiKey
| | ComponentLink1URL | https://www.digikey.com/en/products/detail/texas-instruments/TPS62143RGTR/2833437 | https://www.digikey.com/en/products/detail/texas-instruments/TPS62143RGTR/2833437
| | ComponentLink2Description | Mouser | Mouser
| | ComponentLink2URL | https://eu.mouser.com/ProductDetail/Texas-Instruments/TPS62143RGTR?qs=gXEV9p%2FxLgeSGPjUReaV9A%3D%3D | https://eu.mouser.com/ProductDetail/Texas-Instruments/TPS62143RGTR?qs=gXEV9p%2FxLgeSGPjUReaV9A%3D%3D
| | Description | Buck Switching Regulator IC Positive Fixed 5V 1 Output 2A 16-VFQFN Exposed Pad | Buck Switching Regulator IC Positive Fixed 5V 1 Output 2A 16-VFQFN Exposed Pad
| | DigiKey Part Number | 296-39448-1-ND | 296-39448-1-ND
| | Footprint | QFN50P300X300X100_HS-17N | QFN50P300X300X100_HS-17N
| | Ibis Model
| | Library Name | IntegratedCircuits.IntLib | IntegratedCircuits.IntLib
| | Library Reference | TPS62143RGTR | TPS62143RGTR
| | Mouser Part Number | 595-TPS62143RGTR | 595-TPS62143RGTR
| | PCB3D
| | Pin Info
| | Signal Integrity
| | Simulation
IC6000 | 3V3_MCU_SUPPLY.SchDoc | | Fitted | Fitted
| | Comment | 171010550 Power Module | 171010550 Power Module
| | Component Kind | Standard | Standard
| | ComponentLink1Description | DigiKey | DigiKey
| | ComponentLink1URL | https://www.digikey.com/en/products/detail/w%C3%BCrth-elektronik/171010550/10468263 | https://www.digikey.com/en/products/detail/w%C3%BCrth-elektronik/171010550/10468263
| | ComponentLink2Description | Mouser | Mouser
| | ComponentLink2URL | https://eu.mouser.com/ProductDetail/Wurth-Elektronik/171010550?qs=d0WKAl%252BL4KaovukkXP8RVA%3D%3D | https://eu.mouser.com/ProductDetail/Wurth-Elektronik/171010550?qs=d0WKAl%252BL4KaovukkXP8RVA%3D%3D
| | Description | Non-Isolated PoL Module DC DC Converter 1 Output 0.8 ~ 5.5V 1.2A 2.5V - 5.5V Input | Non-Isolated PoL Module DC DC Converter 1 Output 0.8 ~ 5.5V 1.2A 2.5V - 5.5V Input
| | DigiKey Part Number | 732-171010550CT-ND | 732-171010550CT-ND
| | Footprint | 171010550 | 171010550
| | Ibis Model
| | Library Name | IntegratedCircuits.IntLib | IntegratedCircuits.IntLib
| | Library Reference | 171010550 | 171010550
| | Mouser Part Number | 710-171010550 | 710-171010550
| | PCB3D
| | Pin Info
| | Signal Integrity
| | Simulation
L3000 | 5V_SYS_SUPPLY.SchDoc | | Fitted | Fitted
| | Comment | 12uH | 12uH
| | Component Kind | Standard | Standard
| | ComponentLink1Description | DigiKey | DigiKey
| | ComponentLink1URL | https://www.digikey.com/en/products/detail/w%C3%BCrth-elektronik/744770112/1638629 | https://www.digikey.com/en/products/detail/w%C3%BCrth-elektronik/744770112/1638629
| | Description | FIXED IND 12UH 5.9A 24 MOHM SMD | FIXED IND 12UH 5.9A 24 MOHM SMD
| | DigiKey Part Number | 732-1224-1-ND | 732-1224-1-ND
| | Footprint | INDM120120X80N | INDM120120X80N
| | Ibis Model
| | inductance | 12uH | 12uH
| | Library Name | InductorIntegrated.IntLib | InductorIntegrated.IntLib
| | Library Reference | L000007 | L000007
| | PCB3D
| | Pin Info
| | Signal Integrity
| | Simulation
L4000 | 3V3_SYS_SUPPLY.SchDoc | | Fitted | Fitted
| | Comment | 2.2uH | 2.2uH
| | Component Kind | Standard | Standard
| | ComponentLink1Description | DigiKey | DigiKey
| | ComponentLink1URL | https://www.digikey.com/en/products/detail/bourns-inc/SRP4020TA-2R2M/4901004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 | https://www.digikey.com/en/products/detail/bourns-inc/SRP4020TA-2R2M/4901004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
| | Description | FIXED IND 2.2UH 4A 61 MOHM SMD | FIXED IND 2.2UH 4A 61 MOHM SMD
| | DigiKey Part Number | SRP4020TA-2R2MCT-ND | SRP4020TA-2R2MCT-ND
| | Footprint | INDM4441X20N | INDM4441X20N
| | Ibis Model
| | inductance | 2.2uH | 2.2uH
| | Library Name | InductorIntegrated.IntLib | InductorIntegrated.IntLib
| | Library Reference | L000008 | L000008
| | PCB3D
| | Pin Info
| | Signal Integrity
| | Simulation
L5000 | 5V0_EXT_SUPPLY.SchDoc | | Fitted | Fitted
| | Comment | 2.2uH | 2.2uH
| | Component Kind | Standard | Standard
| | ComponentLink1Description | DigiKey | DigiKey
| | ComponentLink1URL | https://www.digikey.com/en/products/detail/bourns-inc/SRP4020TA-2R2M/4901004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 | https://www.digikey.com/en/products/detail/bourns-inc/SRP4020TA-2R2M/4901004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
| | Description | FIXED IND 2.2UH 4A 61 MOHM SMD | FIXED IND 2.2UH 4A 61 MOHM SMD
| | DigiKey Part Number | SRP4020TA-2R2MCT-ND | SRP4020TA-2R2MCT-ND
| | Footprint | INDM4441X20N | INDM4441X20N
| | Ibis Model
| | inductance | 2.2uH | 2.2uH
| | Library Name | InductorIntegrated.IntLib | InductorIntegrated.IntLib
| | Library Reference | L000008 | L000008
| | PCB3D
| | Pin Info
| | Signal Integrity
| | Simulation
MAIN | 6DOF_CONTROLLER_Top.SchDoc | | Fitted | Fitted
| | Comment | Terminal Block 4POS | Terminal Block 4POS
| | Component Kind | Standard | Standard
| | ComponentLink1Description | Mikroprinc | Mikroprinc
| | ComponentLink1URL | https://www.mikroprinc.com/sr/proizvod/konektor-za-klemu-4-pol-pod-uglom-90-print-rm-508-xy2500 | https://www.mikroprinc.com/sr/proizvod/konektor-za-klemu-4-pol-pod-uglom-90-print-rm-508-xy2500
| | Description | XY2500R-D 250V 12A 5.08mm | XY2500R-D 250V 12A 5.08mm
| | Footprint | TERM_BLOCK_5.08mm 4PIN | TERM_BLOCK_5.08mm 4PIN
| | Ibis Model
| | Library Name | ElectroMechanical.IntLib | ElectroMechanical.IntLib
| | Library Reference | 00000011 | 00000011
| | PCB3D
| | Pin Info
| | Signal Integrity
| | Simulation
P3000 | 5V_SYS_SUPPLY.SchDoc | | Fitted | Fitted
| | Comment | Terminal Block | Terminal Block
| | Component Kind | Standard | Standard
| | ComponentLink1Description | DigiKey | DigiKey
| | ComponentLink1URL | https://www.digikey.com/en/products/detail/adam-tech/EB20-02-C/9831508 | https://www.digikey.com/en/products/detail/adam-tech/EB20-02-C/9831508
| | Description | Terminal block 90 deg 5mm 2PIN | Terminal block 90 deg 5mm 2PIN
| | DigiKey part number | 2057-EB20-02-C-ND | 2057-EB20-02-C-ND
| | Footprint | TERM_BLOCK 5mm 2PIN | TERM_BLOCK 5mm 2PIN
| | Ibis Model
| | Library Name | ElectroMechanical.IntLib | ElectroMechanical.IntLib
| | Library Reference | 00000001 | 00000001
| | PCB3D
| | Pin Info
| | Signal Integrity
| | Simulation
Q1000 | Reverse_Protection.SchDoc | | Fitted | Fitted
| | Comment | SQJ659EP PMOS | SQJ659EP PMOS
| | Component Kind | Standard | Standard
| | ComponentLink1Description | DigiKey | DigiKey
| | ComponentLink1URL | https://www.digikey.com/en/products/detail/vishay-siliconix/SQJ459EP-T1-GE3/6708881 | https://www.digikey.com/en/products/detail/vishay-siliconix/SQJ459EP-T1-GE3/6708881
| | ComponentLink2Description | Mouser | Mouser
| | ComponentLink2URL | https://eu.mouser.com/ProductDetail/Vishay-Siliconix/SQJ459EP-T2_BE3?qs=CiayqK2gdcKpg8h0vLRPjA%3D%3D | https://eu.mouser.com/ProductDetail/Vishay-Siliconix/SQJ459EP-T2_BE3?qs=CiayqK2gdcKpg8h0vLRPjA%3D%3D
| | Description | P-Channel 60 V 52A (Tc) 83W (Tc) Surface Mount PowerPAK® SO-8 | P-Channel 60 V 52A (Tc) 83W (Tc) Surface Mount PowerPAK® SO-8
| | DigiKey Part Number | SQJ459EP-T1_GE3CT-ND | SQJ459EP-T1_GE3CT-ND
| | Footprint | PowerPAK SO-8L SINGLE | PowerPAK SO-8L SINGLE
| | Ibis Model
| | Library Name | Miscellaneous_Lib1.IntLib | Miscellaneous_Lib1.IntLib
| | Library Reference | 00000005 | 00000005
| | Mouser Part Number | 78-SQJ459EP-T2_BE3 | 78-SQJ459EP-T2_BE3
| | PCB3D
| | Pin Info
| | Signal Integrity
| | Simulation
Q1001 | Reverse_Protection.SchDoc | | Fitted | Fitted
| | Comment | SQJ659EP PMOS | SQJ659EP PMOS
| | Component Kind | Standard | Standard
| | ComponentLink1Description | DigiKey | DigiKey
| | ComponentLink1URL | https://www.digikey.com/en/products/detail/vishay-siliconix/SQJ459EP-T1-GE3/6708881 | https://www.digikey.com/en/products/detail/vishay-siliconix/SQJ459EP-T1-GE3/6708881
| | ComponentLink2Description | Mouser | Mouser
| | ComponentLink2URL | https://eu.mouser.com/ProductDetail/Vishay-Siliconix/SQJ459EP-T2_BE3?qs=CiayqK2gdcKpg8h0vLRPjA%3D%3D | https://eu.mouser.com/ProductDetail/Vishay-Siliconix/SQJ459EP-T2_BE3?qs=CiayqK2gdcKpg8h0vLRPjA%3D%3D
| | Description | P-Channel 60 V 52A (Tc) 83W (Tc) Surface Mount PowerPAK® SO-8 | P-Channel 60 V 52A (Tc) 83W (Tc) Surface Mount PowerPAK® SO-8
| | DigiKey Part Number | SQJ459EP-T1_GE3CT-ND | SQJ459EP-T1_GE3CT-ND
| | Footprint | PowerPAK SO-8L SINGLE | PowerPAK SO-8L SINGLE
| | Ibis Model
| | Library Name | Miscellaneous_Lib1.IntLib | Miscellaneous_Lib1.IntLib
| | Library Reference | 00000005 | 00000005
| | Mouser Part Number | 78-SQJ459EP-T2_BE3 | 78-SQJ459EP-T2_BE3
| | PCB3D
| | Pin Info
| | Signal Integrity
| | Simulation
Q1002 | Reverse_Protection.SchDoc | | Fitted | Fitted
| | Comment | SQJ659EP PMOS | SQJ659EP PMOS
| | Component Kind | Standard | Standard
| | ComponentLink1Description | DigiKey | DigiKey
| | ComponentLink1URL | https://www.digikey.com/en/products/detail/vishay-siliconix/SQJ459EP-T1-GE3/6708881 | https://www.digikey.com/en/products/detail/vishay-siliconix/SQJ459EP-T1-GE3/6708881
| | ComponentLink2Description | Mouser | Mouser
| | ComponentLink2URL | https://eu.mouser.com/ProductDetail/Vishay-Siliconix/SQJ459EP-T2_BE3?qs=CiayqK2gdcKpg8h0vLRPjA%3D%3D | https://eu.mouser.com/ProductDetail/Vishay-Siliconix/SQJ459EP-T2_BE3?qs=CiayqK2gdcKpg8h0vLRPjA%3D%3D
| | Description | P-Channel 60 V 52A (Tc) 83W (Tc) Surface Mount PowerPAK® SO-8 | P-Channel 60 V 52A (Tc) 83W (Tc) Surface Mount PowerPAK® SO-8
| | DigiKey Part Number | SQJ459EP-T1_GE3CT-ND | SQJ459EP-T1_GE3CT-ND
| | Footprint | PowerPAK SO-8L SINGLE | PowerPAK SO-8L SINGLE
| | Ibis Model
| | Library Name | Miscellaneous_Lib1.IntLib | Miscellaneous_Lib1.IntLib
| | Library Reference | 00000005 | 00000005
| | Mouser Part Number | 78-SQJ459EP-T2_BE3 | 78-SQJ459EP-T2_BE3
| | PCB3D
| | Pin Info
| | Signal Integrity
| | Simulation
Q1003 | Reverse_Protection.SchDoc | | Fitted | Fitted
| | Comment | SQJ659EP PMOS | SQJ659EP PMOS
| | Component Kind | Standard | Standard
| | ComponentLink1Description | DigiKey | DigiKey
| | ComponentLink1URL | https://www.digikey.com/en/products/detail/vishay-siliconix/SQJ459EP-T1-GE3/6708881 | https://www.digikey.com/en/products/detail/vishay-siliconix/SQJ459EP-T1-GE3/6708881
| | ComponentLink2Description | Mouser | Mouser
| | ComponentLink2URL | https://eu.mouser.com/ProductDetail/Vishay-Siliconix/SQJ459EP-T2_BE3?qs=CiayqK2gdcKpg8h0vLRPjA%3D%3D | https://eu.mouser.com/ProductDetail/Vishay-Siliconix/SQJ459EP-T2_BE3?qs=CiayqK2gdcKpg8h0vLRPjA%3D%3D
| | Description | P-Channel 60 V 52A (Tc) 83W (Tc) Surface Mount PowerPAK® SO-8 | P-Channel 60 V 52A (Tc) 83W (Tc) Surface Mount PowerPAK® SO-8
| | DigiKey Part Number | SQJ459EP-T1_GE3CT-ND | SQJ459EP-T1_GE3CT-ND
| | Footprint | PowerPAK SO-8L SINGLE | PowerPAK SO-8L SINGLE
| | Ibis Model
| | Library Name | Miscellaneous_Lib1.IntLib | Miscellaneous_Lib1.IntLib
| | Library Reference | 00000005 | 00000005
| | Mouser Part Number | 78-SQJ459EP-T2_BE3 | 78-SQJ459EP-T2_BE3
| | PCB3D
| | Pin Info
| | Signal Integrity
| | Simulation
R1000 | Reverse_Protection.SchDoc | | Fitted | Fitted
| | Comment | 47kOhm | 47kOhm
| | Component Kind | Standard | Standard
| | ComponentLink1Description | DigiKey | DigiKey
| | ComponentLink1URL | https://www.digikey.com/en/products/detail/yageo/RC0603FR-0747KL/727253 | https://www.digikey.com/en/products/detail/yageo/RC0603FR-0747KL/727253
| | Description | 47 kOhms ±1% 0.1W, 1/10W Chip Resistor 0603 (1608 Metric) Moisture Resistant Thick Film | 47 kOhms ±1% 0.1W, 1/10W Chip Resistor 0603 (1608 Metric) Moisture Resistant Thick Film
| | DigiKey Part Number | 311-47.0KHRCT-ND | 311-47.0KHRCT-ND
| | Footprint | RES_0603 | RES_0603
| | Ibis Model
| | Library Name | ResistorsIntegrated.IntLib | ResistorsIntegrated.IntLib
| | Library Reference | R000010 | R000010
| | PCB3D
| | Pin Info
| | resistance | 47kOhm | 47kOhm
| | Signal Integrity
| | Simulation
R1002 | Reverse_Protection.SchDoc | | Fitted | Fitted
| | Comment | 47kOhm | 47kOhm
| | Component Kind | Standard | Standard
| | ComponentLink1Description | DigiKey | DigiKey
| | ComponentLink1URL | https://www.digikey.com/en/products/detail/yageo/RC0603FR-0747KL/727253 | https://www.digikey.com/en/products/detail/yageo/RC0603FR-0747KL/727253
| | Description | 47 kOhms ±1% 0.1W, 1/10W Chip Resistor 0603 (1608 Metric) Moisture Resistant Thick Film | 47 kOhms ±1% 0.1W, 1/10W Chip Resistor 0603 (1608 Metric) Moisture Resistant Thick Film
| | DigiKey Part Number | 311-47.0KHRCT-ND | 311-47.0KHRCT-ND
| | Footprint | RES_0603 | RES_0603
| | Ibis Model
| | Library Name | ResistorsIntegrated.IntLib | ResistorsIntegrated.IntLib
| | Library Reference | R000010 | R000010
| | PCB3D
| | Pin Info
| | resistance | 47kOhm | 47kOhm
| | Signal Integrity
| | Simulation
R3000 | 5V_SYS_SUPPLY.SchDoc | | Fitted | Fitted
| | Comment | 0 Ohm Jump | 0 Ohm Jump
| | Component Kind | Standard | Standard
| | ComponentLink1Description | DigiKey | DigiKey
| | ComponentLink1URL | https://www.digikey.com/en/products/detail/panasonic-electronic-components/ERJ-6GEY0R00V/78163 | https://www.digikey.com/en/products/detail/panasonic-electronic-components/ERJ-6GEY0R00V/78163
| | Description | 0 Ohms Jumper Chip Resistor 0805 (2012 Metric) Automotive AEC-Q200 Thick Film | 0 Ohms Jumper Chip Resistor 0805 (2012 Metric) Automotive AEC-Q200 Thick Film
| | DigiKey Part Number | P0.0ACT-ND | P0.0ACT-ND
| | Footprint | RES_0805 | RES_0805
| | Ibis Model
| | Library Name | ResistorsIntegrated.IntLib | ResistorsIntegrated.IntLib
| | Library Reference | R000011 | R000011
| | PCB3D
| | Pin Info
| | resistance | 0 Ohm Jump | 0 Ohm Jump
| | Signal Integrity
| | Simulation
R3001 | 5V_SYS_SUPPLY.SchDoc | | Fitted | Fitted
| | Comment | 0 Ohm Jump | 0 Ohm Jump
| | Component Kind | Standard | Standard
| | ComponentLink1Description | DigiKey | DigiKey
| | ComponentLink1URL | https://www.digikey.com/en/products/detail/stackpole-electronics-inc/RMCF1206ZT0R00/1756906 | https://www.digikey.com/en/products/detail/stackpole-electronics-inc/RMCF1206ZT0R00/1756906
| | Description | 0 Ohms Jumper Chip Resistor 1206 (3216 Metric) Automotive AEC-Q200 Thick Film | 0 Ohms Jumper Chip Resistor 1206 (3216 Metric) Automotive AEC-Q200 Thick Film
| | DigiKey Part Number | RMCF1206ZT0R00CT-ND | RMCF1206ZT0R00CT-ND
| | Footprint | RES_1206 | RES_1206
| | Ibis Model
| | Library Name | ResistorsIntegrated.IntLib | ResistorsIntegrated.IntLib
| | Library Reference | R000012 | R000012
| | PCB3D
| | Pin Info
| | resistance | 0 Ohm Jump | 0 Ohm Jump
| | Signal Integrity
| | Simulation
R3002 | 5V_SYS_SUPPLY.SchDoc | | Fitted | Fitted
| | Comment | 0 Ohm Jump | 0 Ohm Jump
| | Component Kind | Standard | Standard
| | ComponentLink1Description | DigiKey | DigiKey
| | ComponentLink1URL | https://www.digikey.com/en/products/detail/panasonic-electronic-components/ERJ-6GEY0R00V/78163 | https://www.digikey.com/en/products/detail/panasonic-electronic-components/ERJ-6GEY0R00V/78163
| | Description | 0 Ohms Jumper Chip Resistor 0805 (2012 Metric) Automotive AEC-Q200 Thick Film | 0 Ohms Jumper Chip Resistor 0805 (2012 Metric) Automotive AEC-Q200 Thick Film
| | DigiKey Part Number | P0.0ACT-ND | P0.0ACT-ND
| | Footprint | RES_0805 | RES_0805
| | Ibis Model
| | Library Name | ResistorsIntegrated.IntLib | ResistorsIntegrated.IntLib
| | Library Reference | R000011 | R000011
| | PCB3D
| | Pin Info
| | resistance | 0 Ohm Jump | 0 Ohm Jump
| | Signal Integrity
| | Simulation
R3003 | 5V_SYS_SUPPLY.SchDoc | | Fitted | Fitted
| | Comment | 0 Ohm Jump | 0 Ohm Jump
| | Component Kind | Standard | Standard
| | ComponentLink1Description | DigiKey | DigiKey
| | ComponentLink1URL | https://www.digikey.com/en/products/detail/stackpole-electronics-inc/RMCF1206ZT0R00/1756906 | https://www.digikey.com/en/products/detail/stackpole-electronics-inc/RMCF1206ZT0R00/1756906
| | Description | 0 Ohms Jumper Chip Resistor 1206 (3216 Metric) Automotive AEC-Q200 Thick Film | 0 Ohms Jumper Chip Resistor 1206 (3216 Metric) Automotive AEC-Q200 Thick Film
| | DigiKey Part Number | RMCF1206ZT0R00CT-ND | RMCF1206ZT0R00CT-ND
| | Footprint | RES_1206 | RES_1206
| | Ibis Model
| | Library Name | ResistorsIntegrated.IntLib | ResistorsIntegrated.IntLib
| | Library Reference | R000012 | R000012
| | PCB3D
| | Pin Info
| | resistance | 0 Ohm Jump | 0 Ohm Jump
| | Signal Integrity
| | Simulation
R3004 | 5V_SYS_SUPPLY.SchDoc | | Fitted | Fitted
| | Comment | 100Kohm | 100Kohm
| | Component Kind | Standard | Standard
| | ComponentLink1Description | digikey | digikey
| | ComponentLink1URL | https://www.digikey.com/en/products/detail/stackpole-electronics-inc/RMCF0603FG100K/1713543 | https://www.digikey.com/en/products/detail/stackpole-electronics-inc/RMCF0603FG100K/1713543
| | Description | RES 100K OHM 1% 1/10W 0603 | RES 100K OHM 1% 1/10W 0603
| | Footprint | RES_0603 | RES_0603
| | Ibis Model
| | Library Name | ResistorsIntegrated.IntLib | ResistorsIntegrated.IntLib
| | Library Reference | R000006 | R000006
| | PCB3D
| | Pin Info
| | resistance | 100Kohm | 100Kohm
| | Signal Integrity
| | Simulation
R3005 | 5V_SYS_SUPPLY.SchDoc | | Fitted | Fitted
| | Comment | 100Kohm | 100Kohm
| | Component Kind | Standard | Standard
| | ComponentLink1Description | digikey | digikey
| | ComponentLink1URL | https://www.digikey.com/en/products/detail/stackpole-electronics-inc/RMCF0603FG100K/1713543 | https://www.digikey.com/en/products/detail/stackpole-electronics-inc/RMCF0603FG100K/1713543
| | Description | RES 100K OHM 1% 1/10W 0603 | RES 100K OHM 1% 1/10W 0603
| | Footprint | RES_0603 | RES_0603
| | Ibis Model
| | Library Name | ResistorsIntegrated.IntLib | ResistorsIntegrated.IntLib
| | Library Reference | R000006 | R000006
| | PCB3D
| | Pin Info
| | resistance | 100Kohm | 100Kohm
| | Signal Integrity
| | Simulation
R3006 | 5V_SYS_SUPPLY.SchDoc | | Fitted | Fitted
| | Comment | 4.99Kohm | 4.99Kohm
| | Component Kind | Standard | Standard
| | ComponentLink1Description | DigiKey | DigiKey
| | ComponentLink1URL | https://www.digikey.com/en/products/detail/stackpole-electronics-inc/RMCF0603FT4K99/1761322 | https://www.digikey.com/en/products/detail/stackpole-electronics-inc/RMCF0603FT4K99/1761322
| | Description | 4.99 kOhms ±1% 0.1W, 1/10W Chip Resistor 0603 (1608 Metric) Automotive AEC-Q200 Thick Film | 4.99 kOhms ±1% 0.1W, 1/10W Chip Resistor 0603 (1608 Metric) Automotive AEC-Q200 Thick Film
| | DigiKey Part Number | RMCF0603FT4K99CT-ND | RMCF0603FT4K99CT-ND
| | Footprint | RES_0603 | RES_0603
| | Ibis Model
| | Library Name | ResistorsIntegrated.IntLib | ResistorsIntegrated.IntLib
| | Library Reference | R000009 | R000009
| | PCB3D
| | Pin Info
| | resistance | 4.99Kohm | 4.99Kohm
| | Signal Integrity
| | Simulation
R3007 | 5V_SYS_SUPPLY.SchDoc | | Fitted | Fitted
| | Comment | 10Kohm | 10Kohm
| | Component Kind | Standard | Standard
| | ComponentLink1Description | digikey | digikey
| | ComponentLink1URL | https://www.digikey.com/en/products/detail/vishay-beyschlag-draloric-bc-components/MCT06030C1002FP500/1850440 | https://www.digikey.com/en/products/detail/vishay-beyschlag-draloric-bc-components/MCT06030C1002FP500/1850440
| | Description | RES 10K OHM 1% 1/10W 0603 | RES 10K OHM 1% 1/10W 0603
| | Footprint | RES_0603 | RES_0603
| | Ibis Model
| | Library Name | ResistorsIntegrated.IntLib | ResistorsIntegrated.IntLib
| | Library Reference | R000001 | R000001
| | PCB3D
| | Pin Info
| | resistance | 10Kohm | 10Kohm
| | Signal Integrity
| | Simulation
R3008 | 5V_SYS_SUPPLY.SchDoc | | Fitted | Fitted
| | Comment | 5.1kOhm | 5.1kOhm
| | Component Kind | Standard | Standard
| | ComponentLink1Description | DigiKey | DigiKey
| | ComponentLink1URL | https://www.digikey.com/en/products/detail/yageo/RC0603FR-075K1L/727268 | https://www.digikey.com/en/products/detail/yageo/RC0603FR-075K1L/727268
| | Description | 5.1 kOhms ±1% 0.1W, 1/10W Chip Resistor 0603 (1608 Metric) Moisture Resistant Thick Film | 5.1 kOhms ±1% 0.1W, 1/10W Chip Resistor 0603 (1608 Metric) Moisture Resistant Thick Film
| | DigiKey Part Number | 311-5.10KHRCT-ND | 311-5.10KHRCT-ND
| | Footprint | RES_0603 | RES_0603
| | Ibis Model
| | Library Name | ResistorsIntegrated.IntLib | ResistorsIntegrated.IntLib
| | Library Reference | R000013 | R000013
| | PCB3D
| | Pin Info
| | resistance | 5.1kOhm | 5.1kOhm
| | Signal Integrity
| | Simulation
R4000 | 3V3_SYS_SUPPLY.SchDoc | | Fitted | Fitted
| | Comment | 0 Ohm Jump | 0 Ohm Jump
| | Component Kind | Standard | Standard
| | ComponentLink1Description | DigiKey | DigiKey
| | ComponentLink1URL | https://www.digikey.com/en/products/detail/panasonic-electronic-components/ERJ-6GEY0R00V/78163 | https://www.digikey.com/en/products/detail/panasonic-electronic-components/ERJ-6GEY0R00V/78163
| | Description | 0 Ohms Jumper Chip Resistor 0805 (2012 Metric) Automotive AEC-Q200 Thick Film | 0 Ohms Jumper Chip Resistor 0805 (2012 Metric) Automotive AEC-Q200 Thick Film
| | DigiKey Part Number | P0.0ACT-ND | P0.0ACT-ND
| | Footprint | RES_0805 | RES_0805
| | Ibis Model
| | Library Name | ResistorsIntegrated.IntLib | ResistorsIntegrated.IntLib
| | Library Reference | R000011 | R000011
| | PCB3D
| | Pin Info
| | resistance | 0 Ohm Jump | 0 Ohm Jump
| | Signal Integrity
| | Simulation
R4001 | 3V3_SYS_SUPPLY.SchDoc | | Fitted | Fitted
| | Comment | 0 Ohm Jump | 0 Ohm Jump
| | Component Kind | Standard | Standard
| | ComponentLink1Description | DigiKey | DigiKey
| | ComponentLink1URL | https://www.digikey.com/en/products/detail/panasonic-electronic-components/ERJ-6GEY0R00V/78163 | https://www.digikey.com/en/products/detail/panasonic-electronic-components/ERJ-6GEY0R00V/78163
| | Description | 0 Ohms Jumper Chip Resistor 0805 (2012 Metric) Automotive AEC-Q200 Thick Film | 0 Ohms Jumper Chip Resistor 0805 (2012 Metric) Automotive AEC-Q200 Thick Film
| | DigiKey Part Number | P0.0ACT-ND | P0.0ACT-ND
| | Footprint | RES_0805 | RES_0805
| | Ibis Model
| | Library Name | ResistorsIntegrated.IntLib | ResistorsIntegrated.IntLib
| | Library Reference | R000011 | R000011
| | PCB3D
| | Pin Info
| | resistance | 0 Ohm Jump | 0 Ohm Jump
| | Signal Integrity
| | Simulation
R4002 | 3V3_SYS_SUPPLY.SchDoc | | Fitted | Fitted
| | Comment | 0 Ohm Jump | 0 Ohm Jump
| | Component Kind | Standard | Standard
| | ComponentLink1Description | DigiKey | DigiKey
| | ComponentLink1URL | https://www.digikey.com/en/products/detail/panasonic-electronic-components/ERJ-6GEY0R00V/78163 | https://www.digikey.com/en/products/detail/panasonic-electronic-components/ERJ-6GEY0R00V/78163
| | Description | 0 Ohms Jumper Chip Resistor 0805 (2012 Metric) Automotive AEC-Q200 Thick Film | 0 Ohms Jumper Chip Resistor 0805 (2012 Metric) Automotive AEC-Q200 Thick Film
| | DigiKey Part Number | P0.0ACT-ND | P0.0ACT-ND
| | Footprint | RES_0805 | RES_0805
| | Ibis Model
| | Library Name | ResistorsIntegrated.IntLib | ResistorsIntegrated.IntLib
| | Library Reference | R000011 | R000011
| | PCB3D
| | Pin Info
| | resistance | 0 Ohm Jump | 0 Ohm Jump
| | Signal Integrity
| | Simulation
R4003 | 3V3_SYS_SUPPLY.SchDoc | | Fitted | Fitted
| | Comment | 0 Ohm Jump | 0 Ohm Jump
| | Component Kind | Standard | Standard
| | ComponentLink1Description | DigiKey | DigiKey
| | ComponentLink1URL | https://www.digikey.com/en/products/detail/panasonic-electronic-components/ERJ-6GEY0R00V/78163 | https://www.digikey.com/en/products/detail/panasonic-electronic-components/ERJ-6GEY0R00V/78163
| | Description | 0 Ohms Jumper Chip Resistor 0805 (2012 Metric) Automotive AEC-Q200 Thick Film | 0 Ohms Jumper Chip Resistor 0805 (2012 Metric) Automotive AEC-Q200 Thick Film
| | DigiKey Part Number | P0.0ACT-ND | P0.0ACT-ND
| | Footprint | RES_0805 | RES_0805
| | Ibis Model
| | Library Name | ResistorsIntegrated.IntLib | ResistorsIntegrated.IntLib
| | Library Reference | R000011 | R000011
| | PCB3D
| | Pin Info
| | resistance | 0 Ohm Jump | 0 Ohm Jump
| | Signal Integrity
| | Simulation
R4004 | 3V3_SYS_SUPPLY.SchDoc | | Fitted | Fitted
| | Comment | 1Kohm | 1Kohm
| | Component Kind | Standard | Standard
| | ComponentLink1Description | digikey | digikey
| | ComponentLink1URL | https://www.digikey.com/en/products/detail/vishay-beyschlag-draloric-bc-components/MCT06030C1001FP500/2607821 | https://www.digikey.com/en/products/detail/vishay-beyschlag-draloric-bc-components/MCT06030C1001FP500/2607821
| | Description | RES 1K OHM 1% 1/10W 0603 | RES 1K OHM 1% 1/10W 0603
| | Footprint | RES_0603 | RES_0603
| | Ibis Model
| | Library Name | ResistorsIntegrated.IntLib | ResistorsIntegrated.IntLib
| | Library Reference | R000004 | R000004
| | PCB3D
| | Pin Info
| | resistance | 1Kohm | 1Kohm
| | Signal Integrity
| | Simulation
R4005 | 3V3_SYS_SUPPLY.SchDoc | | Fitted | Fitted
| | Comment | 10Kohm | 10Kohm
| | Component Kind | Standard | Standard
| | ComponentLink1Description | digikey | digikey
| | ComponentLink1URL | https://www.digikey.com/en/products/detail/vishay-beyschlag-draloric-bc-components/MCT06030C1002FP500/1850440 | https://www.digikey.com/en/products/detail/vishay-beyschlag-draloric-bc-components/MCT06030C1002FP500/1850440
| | Description | RES 10K OHM 1% 1/10W 0603 | RES 10K OHM 1% 1/10W 0603
| | Footprint | RES_0603 | RES_0603
| | Ibis Model
| | Library Name | ResistorsIntegrated.IntLib | ResistorsIntegrated.IntLib
| | Library Reference | R000001 | R000001
| | PCB3D
| | Pin Info
| | resistance | 10Kohm | 10Kohm
| | Signal Integrity
| | Simulation
R4006 | 3V3_SYS_SUPPLY.SchDoc | | Fitted | Fitted
| | Comment | 100Kohm | 100Kohm
| | Component Kind | Standard | Standard
| | ComponentLink1Description | digikey | digikey
| | ComponentLink1URL | https://www.digikey.com/en/products/detail/stackpole-electronics-inc/RMCF0603FG100K/1713543 | https://www.digikey.com/en/products/detail/stackpole-electronics-inc/RMCF0603FG100K/1713543
| | Description | RES 100K OHM 1% 1/10W 0603 | RES 100K OHM 1% 1/10W 0603
| | Footprint | RES_0603 | RES_0603
| | Ibis Model
| | Library Name | ResistorsIntegrated.IntLib | ResistorsIntegrated.IntLib
| | Library Reference | R000006 | R000006
| | PCB3D
| | Pin Info
| | resistance | 100Kohm | 100Kohm
| | Signal Integrity
| | Simulation
R5000 | 5V0_EXT_SUPPLY.SchDoc | | Fitted | Fitted
| | Comment | 0 Ohm Jump | 0 Ohm Jump
| | Component Kind | Standard | Standard
| | ComponentLink1Description | DigiKey | DigiKey
| | ComponentLink1URL | https://www.digikey.com/en/products/detail/panasonic-electronic-components/ERJ-6GEY0R00V/78163 | https://www.digikey.com/en/products/detail/panasonic-electronic-components/ERJ-6GEY0R00V/78163
| | Description | 0 Ohms Jumper Chip Resistor 0805 (2012 Metric) Automotive AEC-Q200 Thick Film | 0 Ohms Jumper Chip Resistor 0805 (2012 Metric) Automotive AEC-Q200 Thick Film
| | DigiKey Part Number | P0.0ACT-ND | P0.0ACT-ND
| | Footprint | RES_0805 | RES_0805
| | Ibis Model
| | Library Name | ResistorsIntegrated.IntLib | ResistorsIntegrated.IntLib
| | Library Reference | R000011 | R000011
| | PCB3D
| | Pin Info
| | resistance | 0 Ohm Jump | 0 Ohm Jump
| | Signal Integrity
| | Simulation
R5001 | 5V0_EXT_SUPPLY.SchDoc | | Fitted | Fitted
| | Comment | 0 Ohm Jump | 0 Ohm Jump
| | Component Kind | Standard | Standard
| | ComponentLink1Description | DigiKey | DigiKey
| | ComponentLink1URL | https://www.digikey.com/en/products/detail/stackpole-electronics-inc/RMCF1206ZT0R00/1756906 | https://www.digikey.com/en/products/detail/stackpole-electronics-inc/RMCF1206ZT0R00/1756906
| | Description | 0 Ohms Jumper Chip Resistor 1206 (3216 Metric) Automotive AEC-Q200 Thick Film | 0 Ohms Jumper Chip Resistor 1206 (3216 Metric) Automotive AEC-Q200 Thick Film
| | DigiKey Part Number | RMCF1206ZT0R00CT-ND | RMCF1206ZT0R00CT-ND
| | Footprint | RES_1206 | RES_1206
| | Ibis Model
| | Library Name | ResistorsIntegrated.IntLib | ResistorsIntegrated.IntLib
| | Library Reference | R000012 | R000012
| | PCB3D
| | Pin Info
| | resistance | 0 Ohm Jump | 0 Ohm Jump
| | Signal Integrity
| | Simulation
R5002 | 5V0_EXT_SUPPLY.SchDoc | | Fitted | Fitted
| | Comment | 0 Ohm Jump | 0 Ohm Jump
| | Component Kind | Standard | Standard
| | ComponentLink1Description | DigiKey | DigiKey
| | ComponentLink1URL | https://www.digikey.com/en/products/detail/stackpole-electronics-inc/RMCF1206ZT0R00/1756906 | https://www.digikey.com/en/products/detail/stackpole-electronics-inc/RMCF1206ZT0R00/1756906
| | Description | 0 Ohms Jumper Chip Resistor 1206 (3216 Metric) Automotive AEC-Q200 Thick Film | 0 Ohms Jumper Chip Resistor 1206 (3216 Metric) Automotive AEC-Q200 Thick Film
| | DigiKey Part Number | RMCF1206ZT0R00CT-ND | RMCF1206ZT0R00CT-ND
| | Footprint | RES_1206 | RES_1206
| | Ibis Model
| | Library Name | ResistorsIntegrated.IntLib | ResistorsIntegrated.IntLib
| | Library Reference | R000012 | R000012
| | PCB3D
| | Pin Info
| | resistance | 0 Ohm Jump | 0 Ohm Jump
| | Signal Integrity
| | Simulation
R5003 | 5V0_EXT_SUPPLY.SchDoc | | Fitted | Fitted
| | Comment | 0 Ohm Jump | 0 Ohm Jump
| | Component Kind | Standard | Standard
| | ComponentLink1Description | DigiKey | DigiKey
| | ComponentLink1URL | https://www.digikey.com/en/products/detail/panasonic-electronic-components/ERJ-6GEY0R00V/78163 | https://www.digikey.com/en/products/detail/panasonic-electronic-components/ERJ-6GEY0R00V/78163
| | Description | 0 Ohms Jumper Chip Resistor 0805 (2012 Metric) Automotive AEC-Q200 Thick Film | 0 Ohms Jumper Chip Resistor 0805 (2012 Metric) Automotive AEC-Q200 Thick Film
| | DigiKey Part Number | P0.0ACT-ND | P0.0ACT-ND
| | Footprint | RES_0805 | RES_0805
| | Ibis Model
| | Library Name | ResistorsIntegrated.IntLib | ResistorsIntegrated.IntLib
| | Library Reference | R000011 | R000011
| | PCB3D
| | Pin Info
| | resistance | 0 Ohm Jump | 0 Ohm Jump
| | Signal Integrity
| | Simulation
R5004 | 5V0_EXT_SUPPLY.SchDoc | | Fitted | Fitted
| | Comment | 1Kohm | 1Kohm
| | Component Kind | Standard | Standard
| | ComponentLink1Description | digikey | digikey
| | ComponentLink1URL | https://www.digikey.com/en/products/detail/vishay-beyschlag-draloric-bc-components/MCT06030C1001FP500/2607821 | https://www.digikey.com/en/products/detail/vishay-beyschlag-draloric-bc-components/MCT06030C1001FP500/2607821
| | Description | RES 1K OHM 1% 1/10W 0603 | RES 1K OHM 1% 1/10W 0603
| | Footprint | RES_0603 | RES_0603
| | Ibis Model
| | Library Name | ResistorsIntegrated.IntLib | ResistorsIntegrated.IntLib
| | Library Reference | R000004 | R000004
| | PCB3D
| | Pin Info
| | resistance | 1Kohm | 1Kohm
| | Signal Integrity
| | Simulation
R5005 | 5V0_EXT_SUPPLY.SchDoc | | Fitted | Fitted
| | Comment | 10Kohm | 10Kohm
| | Component Kind | Standard | Standard
| | ComponentLink1Description | digikey | digikey
| | ComponentLink1URL | https://www.digikey.com/en/products/detail/vishay-beyschlag-draloric-bc-components/MCT06030C1002FP500/1850440 | https://www.digikey.com/en/products/detail/vishay-beyschlag-draloric-bc-components/MCT06030C1002FP500/1850440
| | Description | RES 10K OHM 1% 1/10W 0603 | RES 10K OHM 1% 1/10W 0603
| | Footprint | RES_0603 | RES_0603
| | Ibis Model
| | Library Name | ResistorsIntegrated.IntLib | ResistorsIntegrated.IntLib
| | Library Reference | R000001 | R000001
| | PCB3D
| | Pin Info
| | resistance | 10Kohm | 10Kohm
| | Signal Integrity
| | Simulation
R5006 | 5V0_EXT_SUPPLY.SchDoc | | Fitted | Fitted
| | Comment | 100Kohm | 100Kohm
| | Component Kind | Standard | Standard
| | ComponentLink1Description | digikey | digikey
| | ComponentLink1URL | https://www.digikey.com/en/products/detail/stackpole-electronics-inc/RMCF0603FG100K/1713543 | https://www.digikey.com/en/products/detail/stackpole-electronics-inc/RMCF0603FG100K/1713543
| | Description | RES 100K OHM 1% 1/10W 0603 | RES 100K OHM 1% 1/10W 0603
| | Footprint | RES_0603 | RES_0603
| | Ibis Model
| | Library Name | ResistorsIntegrated.IntLib | ResistorsIntegrated.IntLib
| | Library Reference | R000006 | R000006
| | PCB3D
| | Pin Info
| | resistance | 100Kohm | 100Kohm
| | Signal Integrity
| | Simulation
R6000 | 3V3_MCU_SUPPLY.SchDoc | | Fitted | Fitted
| | Comment | 0 OHM Jump | 0 OHM Jump
| | Component Kind | Standard | Standard
| | ComponentLink1Description | DigiKey | DigiKey
| | ComponentLink1URL | https://www.digikey.com/en/products/detail/stackpole-electronics-inc/RMCF0603ZT0R00/1756908 | https://www.digikey.com/en/products/detail/stackpole-electronics-inc/RMCF0603ZT0R00/1756908
| | Description | RES 0 OHM JUMPER 1/10W 0603 | RES 0 OHM JUMPER 1/10W 0603
| | Footprint | RES_0603 | RES_0603
| | Ibis Model
| | Library Name | ResistorsIntegrated.IntLib | ResistorsIntegrated.IntLib
| | Library Reference | R000007 | R000007
| | PCB3D
| | Pin Info
| | resistance | 0 OHM Jump | 0 OHM Jump
| | Signal Integrity
| | Simulation
| | Supplier 1 | Arrow Electronics | Arrow Electronics
| | Supplier Part Number 1 | RMCF0603ZT0R00 | RMCF0603ZT0R00
R6001 | 3V3_MCU_SUPPLY.SchDoc | | Fitted | Fitted
| | Comment | 0 Ohm Jump | 0 Ohm Jump
| | Component Kind | Standard | Standard
| | ComponentLink1Description | DigiKey | DigiKey
| | ComponentLink1URL | https://www.digikey.com/en/products/detail/panasonic-electronic-components/ERJ-6GEY0R00V/78163 | https://www.digikey.com/en/products/detail/panasonic-electronic-components/ERJ-6GEY0R00V/78163
| | Description | 0 Ohms Jumper Chip Resistor 0805 (2012 Metric) Automotive AEC-Q200 Thick Film | 0 Ohms Jumper Chip Resistor 0805 (2012 Metric) Automotive AEC-Q200 Thick Film
| | DigiKey Part Number | P0.0ACT-ND | P0.0ACT-ND
| | Footprint | RES_0805 | RES_0805
| | Ibis Model
| | Library Name | ResistorsIntegrated.IntLib | ResistorsIntegrated.IntLib
| | Library Reference | R000011 | R000011
| | PCB3D
| | Pin Info
| | resistance | 0 Ohm Jump | 0 Ohm Jump
| | Signal Integrity
| | Simulation
R6002 | 3V3_MCU_SUPPLY.SchDoc | | Fitted | Fitted
| | Comment | 0 OHM Jump | 0 OHM Jump
| | Component Kind | Standard | Standard
| | ComponentLink1Description | DigiKey | DigiKey
| | ComponentLink1URL | https://www.digikey.com/en/products/detail/stackpole-electronics-inc/RMCF0603ZT0R00/1756908 | https://www.digikey.com/en/products/detail/stackpole-electronics-inc/RMCF0603ZT0R00/1756908
| | Description | RES 0 OHM JUMPER 1/10W 0603 | RES 0 OHM JUMPER 1/10W 0603
| | Footprint | RES_0603 | RES_0603
| | Ibis Model
| | Library Name | ResistorsIntegrated.IntLib | ResistorsIntegrated.IntLib
| | Library Reference | R000007 | R000007
| | PCB3D
| | Pin Info
| | resistance | 0 OHM Jump | 0 OHM Jump
| | Signal Integrity
| | Simulation
| | Supplier 1 | Arrow Electronics | Arrow Electronics
| | Supplier Part Number 1 | RMCF0603ZT0R00 | RMCF0603ZT0R00
R6003 | 3V3_MCU_SUPPLY.SchDoc | | Fitted | Fitted
| | Comment | 0 Ohm Jump | 0 Ohm Jump
| | Component Kind | Standard | Standard
| | ComponentLink1Description | DigiKey | DigiKey
| | ComponentLink1URL | https://www.digikey.com/en/products/detail/panasonic-electronic-components/ERJ-6GEY0R00V/78163 | https://www.digikey.com/en/products/detail/panasonic-electronic-components/ERJ-6GEY0R00V/78163
| | Description | 0 Ohms Jumper Chip Resistor 0805 (2012 Metric) Automotive AEC-Q200 Thick Film | 0 Ohms Jumper Chip Resistor 0805 (2012 Metric) Automotive AEC-Q200 Thick Film
| | DigiKey Part Number | P0.0ACT-ND | P0.0ACT-ND
| | Footprint | RES_0805 | RES_0805
| | Ibis Model
| | Library Name | ResistorsIntegrated.IntLib | ResistorsIntegrated.IntLib
| | Library Reference | R000011 | R000011
| | PCB3D
| | Pin Info
| | resistance | 0 Ohm Jump | 0 Ohm Jump
| | Signal Integrity
| | Simulation
R6004 | 3V3_MCU_SUPPLY.SchDoc | | Fitted | Fitted
| | Comment | 100Kohm | 100Kohm
| | Component Kind | Standard | Standard
| | ComponentLink1Description | digikey | digikey
| | ComponentLink1URL | https://www.digikey.com/en/products/detail/stackpole-electronics-inc/RMCF0603FG100K/1713543 | https://www.digikey.com/en/products/detail/stackpole-electronics-inc/RMCF0603FG100K/1713543
| | Description | RES 100K OHM 1% 1/10W 0603 | RES 100K OHM 1% 1/10W 0603
| | Footprint | RES_0603 | RES_0603
| | Ibis Model
| | Library Name | ResistorsIntegrated.IntLib | ResistorsIntegrated.IntLib
| | Library Reference | R000006 | R000006
| | PCB3D
| | Pin Info
| | resistance | 100Kohm | 100Kohm
| | Signal Integrity
| | Simulation
R6005 | 3V3_MCU_SUPPLY.SchDoc | | Fitted | Fitted
| | Comment | 0 OHM Jump | 0 OHM Jump
| | Component Kind | Standard | Standard
| | ComponentLink1Description | DigiKey | DigiKey
| | ComponentLink1URL | https://www.digikey.com/en/products/detail/stackpole-electronics-inc/RMCF0603ZT0R00/1756908 | https://www.digikey.com/en/products/detail/stackpole-electronics-inc/RMCF0603ZT0R00/1756908
| | Description | RES 0 OHM JUMPER 1/10W 0603 | RES 0 OHM JUMPER 1/10W 0603
| | Footprint | RES_0603 | RES_0603
| | Ibis Model
| | Library Name | ResistorsIntegrated.IntLib | ResistorsIntegrated.IntLib
| | Library Reference | R000007 | R000007
| | PCB3D
| | Pin Info
| | resistance | 0 OHM Jump | 0 OHM Jump
| | Signal Integrity
| | Simulation
| | Supplier 1 | Arrow Electronics | Arrow Electronics
| | Supplier Part Number 1 | RMCF0603ZT0R00 | RMCF0603ZT0R00
R6006 | 3V3_MCU_SUPPLY.SchDoc | | Fitted | Fitted
| | Comment | 1Kohm | 1Kohm
| | Component Kind | Standard | Standard
| | ComponentLink1Description | digikey | digikey
| | ComponentLink1URL | https://www.digikey.com/en/products/detail/vishay-beyschlag-draloric-bc-components/MCT06030C1001FP500/2607821 | https://www.digikey.com/en/products/detail/vishay-beyschlag-draloric-bc-components/MCT06030C1001FP500/2607821
| | Description | RES 1K OHM 1% 1/10W 0603 | RES 1K OHM 1% 1/10W 0603
| | Footprint | RES_0603 | RES_0603
| | Ibis Model
| | Library Name | ResistorsIntegrated.IntLib | ResistorsIntegrated.IntLib
| | Library Reference | R000004 | R000004
| | PCB3D
| | Pin Info
| | resistance | 1Kohm | 1Kohm
| | Signal Integrity
| | Simulation
R6007 | 3V3_MCU_SUPPLY.SchDoc | | Fitted | Fitted
| | Comment | 32.4kOhm | 32.4kOhm
| | Component Kind | Standard | Standard
| | ComponentLink1Description | DigiKey | DigiKey
| | ComponentLink1URL | https://www.digikey.com/en/products/detail/bourns-inc/CR0603-FX-3242ELF/3783945 | https://www.digikey.com/en/products/detail/bourns-inc/CR0603-FX-3242ELF/3783945
| | Description | 32.4 kOhms ±1% 0.1W, 1/10W Chip Resistor 0603 (1608 Metric) Moisture Resistant Thick Film | 32.4 kOhms ±1% 0.1W, 1/10W Chip Resistor 0603 (1608 Metric) Moisture Resistant Thick Film
| | DigiKey Part Number | CR0603-FX-3242ELFCT-ND | CR0603-FX-3242ELFCT-ND
| | Footprint | RES_0603 | RES_0603
| | Ibis Model
| | Library Name | ResistorsIntegrated.IntLib | ResistorsIntegrated.IntLib
| | Library Reference | R000014 | R000014
| | PCB3D
| | Pin Info
| | resistance | 32.4kOhm | 32.4kOhm
| | Signal Integrity
| | Simulation
R6008 | 3V3_MCU_SUPPLY.SchDoc | | Fitted | Fitted
| | Comment | 0 OHM Jump | 0 OHM Jump
| | Component Kind | Standard | Standard
| | ComponentLink1Description | DigiKey | DigiKey
| | ComponentLink1URL | https://www.digikey.com/en/products/detail/stackpole-electronics-inc/RMCF0603ZT0R00/1756908 | https://www.digikey.com/en/products/detail/stackpole-electronics-inc/RMCF0603ZT0R00/1756908
| | Description | RES 0 OHM JUMPER 1/10W 0603 | RES 0 OHM JUMPER 1/10W 0603
| | Footprint | RES_0603 | RES_0603
| | Ibis Model
| | Library Name | ResistorsIntegrated.IntLib | ResistorsIntegrated.IntLib
| | Library Reference | R000007 | R000007
| | PCB3D
| | Pin Info
| | resistance | 0 OHM Jump | 0 OHM Jump
| | Signal Integrity
| | Simulation
| | Supplier 1 | Arrow Electronics | Arrow Electronics
| | Supplier Part Number 1 | RMCF0603ZT0R00 | RMCF0603ZT0R00
R6009 | 3V3_MCU_SUPPLY.SchDoc | | Fitted | Fitted
| | Comment | 10Kohm | 10Kohm
| | Component Kind | Standard | Standard
| | ComponentLink1Description | digikey | digikey
| | ComponentLink1URL | https://www.digikey.com/en/products/detail/vishay-beyschlag-draloric-bc-components/MCT06030C1002FP500/1850440 | https://www.digikey.com/en/products/detail/vishay-beyschlag-draloric-bc-components/MCT06030C1002FP500/1850440
| | Description | RES 10K OHM 1% 1/10W 0603 | RES 10K OHM 1% 1/10W 0603
| | Footprint | RES_0603 | RES_0603
| | Ibis Model
| | Library Name | ResistorsIntegrated.IntLib | ResistorsIntegrated.IntLib
| | Library Reference | R000001 | R000001
| | PCB3D
| | Pin Info
| | resistance | 10Kohm | 10Kohm
| | Signal Integrity
| | Simulation
R10001 | Reverse_Protection.SchDoc | | Fitted | Fitted
| | Comment | 47kOhm | 47kOhm
| | Component Kind | Standard | Standard
| | ComponentLink1Description | DigiKey | DigiKey
| | ComponentLink1URL | https://www.digikey.com/en/products/detail/yageo/RC0603FR-0747KL/727253 | https://www.digikey.com/en/products/detail/yageo/RC0603FR-0747KL/727253
| | Description | 47 kOhms ±1% 0.1W, 1/10W Chip Resistor 0603 (1608 Metric) Moisture Resistant Thick Film | 47 kOhms ±1% 0.1W, 1/10W Chip Resistor 0603 (1608 Metric) Moisture Resistant Thick Film
| | DigiKey Part Number | 311-47.0KHRCT-ND | 311-47.0KHRCT-ND
| | Footprint | RES_0603 | RES_0603
| | Ibis Model
| | Library Name | ResistorsIntegrated.IntLib | ResistorsIntegrated.IntLib
| | Library Reference | R000010 | R000010
| | PCB3D
| | Pin Info
| | resistance | 47kOhm | 47kOhm
| | Signal Integrity
| | Simulation
TP3000 | 5V_SYS_SUPPLY.SchDoc | | Fitted | Fitted
| | Comment | Test point | Test point
| | Component Kind | Standard | Standard
| | Description | Test point 1mm | Test point 1mm
| | Footprint | TestPoint | TestPoint
| | Ibis Model
| | Library Name | IntegratedCircuits.IntLib | IntegratedCircuits.IntLib
| | Library Reference | TP002 | TP002
| | PCB3D
| | Pin Info
| | Signal Integrity
| | Simulation
TP3001 | 5V_SYS_SUPPLY.SchDoc | | Fitted | Fitted
| | Comment | Test point | Test point
| | Component Kind | Standard | Standard
| | Description | Test point 1mm | Test point 1mm
| | Footprint | TestPoint | TestPoint
| | Ibis Model
| | Library Name | IntegratedCircuits.IntLib | IntegratedCircuits.IntLib
| | Library Reference | TP002 | TP002
| | PCB3D
| | Pin Info
| | Signal Integrity
| | Simulation
TP3002 | 5V_SYS_SUPPLY.SchDoc | | Fitted | Fitted
| | Comment | Test point | Test point
| | Component Kind | Standard | Standard
| | Description | Test point 1mm | Test point 1mm
| | Footprint | TestPoint | TestPoint
| | Ibis Model
| | Library Name | IntegratedCircuits.IntLib | IntegratedCircuits.IntLib
| | Library Reference | TP002 | TP002
| | PCB3D
| | Pin Info
| | Signal Integrity
| | Simulation
TP3003 | 5V_SYS_SUPPLY.SchDoc | | Fitted | Fitted
| | Comment | Test point | Test point
| | Component Kind | Standard | Standard
| | Description | Test point 1mm | Test point 1mm
| | Footprint | TestPoint | TestPoint
| | Ibis Model
| | Library Name | IntegratedCircuits.IntLib | IntegratedCircuits.IntLib
| | Library Reference | TP002 | TP002
| | PCB3D
| | Pin Info
| | Signal Integrity
| | Simulation
TP3004 | 5V_SYS_SUPPLY.SchDoc | | Fitted | Fitted
| | Comment | Test point | Test point
| | Component Kind | Standard | Standard
| | Description | Test point 1mm | Test point 1mm
| | Footprint | TestPoint | TestPoint
| | Ibis Model
| | Library Name | IntegratedCircuits.IntLib | IntegratedCircuits.IntLib
| | Library Reference | TP002 | TP002
| | PCB3D
| | Pin Info
| | Signal Integrity
| | Simulation
TP3005 | 5V_SYS_SUPPLY.SchDoc | | Fitted | Fitted
| | Comment | Test point | Test point
| | Component Kind | Standard | Standard
| | Description | Test point 1mm | Test point 1mm
| | Footprint | TestPoint | TestPoint
| | Ibis Model
| | Library Name | IntegratedCircuits.IntLib | IntegratedCircuits.IntLib
| | Library Reference | TP002 | TP002
| | PCB3D
| | Pin Info
| | Signal Integrity
| | Simulation
TP3006 | 5V_SYS_SUPPLY.SchDoc | | Fitted | Fitted
| | Comment | Test point | Test point
| | Component Kind | Standard | Standard
| | Description | Test point 1mm | Test point 1mm
| | Footprint | TestPoint | TestPoint
| | Ibis Model
| | Library Name | IntegratedCircuits.IntLib | IntegratedCircuits.IntLib
| | Library Reference | TP002 | TP002
| | PCB3D
| | Pin Info
| | Signal Integrity
| | Simulation
TP3007 | 5V_SYS_SUPPLY.SchDoc | | Fitted | Fitted
| | Comment | Test point | Test point
| | Component Kind | Standard | Standard
| | Description | Test point 1mm | Test point 1mm
| | Footprint | TestPoint | TestPoint
| | Ibis Model
| | Library Name | IntegratedCircuits.IntLib | IntegratedCircuits.IntLib
| | Library Reference | TP002 | TP002
| | PCB3D
| | Pin Info
| | Signal Integrity
| | Simulation
TP3008 | 5V_SYS_SUPPLY.SchDoc | | Fitted | Fitted
| | Comment | Test point | Test point
| | Component Kind | Standard | Standard
| | Description | Test point 1mm | Test point 1mm
| | Footprint | TestPoint | TestPoint
| | Ibis Model
| | Library Name | IntegratedCircuits.IntLib | IntegratedCircuits.IntLib
| | Library Reference | TP002 | TP002
| | PCB3D
| | Pin Info
| | Signal Integrity
| | Simulation
TP3009 | 5V_SYS_SUPPLY.SchDoc | | Fitted | Fitted
| | Comment | Test point | Test point
| | Component Kind | Standard | Standard
| | Description | Test point 1mm | Test point 1mm
| | Footprint | TestPoint | TestPoint
| | Ibis Model
| | Library Name | IntegratedCircuits.IntLib | IntegratedCircuits.IntLib
| | Library Reference | TP002 | TP002
| | PCB3D
| | Pin Info
| | Signal Integrity
| | Simulation
TP4000 | 3V3_SYS_SUPPLY.SchDoc | | Fitted | Fitted
| | Comment | Test point | Test point
| | Component Kind | Standard | Standard
| | Description | Test point 1mm | Test point 1mm
| | Footprint | TestPoint | TestPoint
| | Ibis Model
| | Library Name | IntegratedCircuits.IntLib | IntegratedCircuits.IntLib
| | Library Reference | TP002 | TP002
| | PCB3D
| | Pin Info
| | Signal Integrity
| | Simulation
TP4001 | 3V3_SYS_SUPPLY.SchDoc | | Fitted | Fitted
| | Comment | Test point | Test point
| | Component Kind | Standard | Standard
| | Description | Test point 1mm | Test point 1mm
| | Footprint | TestPoint | TestPoint
| | Ibis Model
| | Library Name | IntegratedCircuits.IntLib | IntegratedCircuits.IntLib
| | Library Reference | TP002 | TP002
| | PCB3D
| | Pin Info
| | Signal Integrity
| | Simulation
TP4002 | 3V3_SYS_SUPPLY.SchDoc | | Fitted | Fitted
| | Comment | Test point | Test point
| | Component Kind | Standard | Standard
| | Description | Test point 1mm | Test point 1mm
| | Footprint | TestPoint | TestPoint
| | Ibis Model
| | Library Name | IntegratedCircuits.IntLib | IntegratedCircuits.IntLib
| | Library Reference | TP002 | TP002
| | PCB3D
| | Pin Info
| | Signal Integrity
| | Simulation
TP4003 | 3V3_SYS_SUPPLY.SchDoc | | Fitted | Fitted
| | Comment | Test point | Test point
| | Component Kind | Standard | Standard
| | Description | Test point 1mm | Test point 1mm
| | Footprint | TestPoint | TestPoint
| | Ibis Model
| | Library Name | IntegratedCircuits.IntLib | IntegratedCircuits.IntLib
| | Library Reference | TP002 | TP002
| | PCB3D
| | Pin Info
| | Signal Integrity
| | Simulation
TP4004 | 3V3_SYS_SUPPLY.SchDoc | | Fitted | Fitted
| | Comment | Test point | Test point
| | Component Kind | Standard | Standard
| | Description | Test point 1mm | Test point 1mm
| | Footprint | TestPoint | TestPoint
| | Ibis Model
| | Library Name | IntegratedCircuits.IntLib | IntegratedCircuits.IntLib
| | Library Reference | TP002 | TP002
| | PCB3D
| | Pin Info
| | Signal Integrity
| | Simulation
TP4005 | 3V3_SYS_SUPPLY.SchDoc | | Fitted | Fitted
| | Comment | Test point | Test point
| | Component Kind | Standard | Standard
| | Description | Test point 1mm | Test point 1mm
| | Footprint | TestPoint | TestPoint
| | Ibis Model
| | Library Name | IntegratedCircuits.IntLib | IntegratedCircuits.IntLib
| | Library Reference | TP002 | TP002
| | PCB3D
| | Pin Info
| | Signal Integrity
| | Simulation
TP4006 | 3V3_SYS_SUPPLY.SchDoc | | Fitted | Fitted
| | Comment | Test point | Test point
| | Component Kind | Standard | Standard
| | Description | Test point 1mm | Test point 1mm
| | Footprint | TestPoint | TestPoint
| | Ibis Model
| | Library Name | IntegratedCircuits.IntLib | IntegratedCircuits.IntLib
| | Library Reference | TP002 | TP002
| | PCB3D
| | Pin Info
| | Signal Integrity
| | Simulation
TP4007 | 3V3_SYS_SUPPLY.SchDoc | | Fitted | Fitted
| | Comment | Test point | Test point
| | Component Kind | Standard | Standard
| | Description | Test point 1mm | Test point 1mm
| | Footprint | TestPoint | TestPoint
| | Ibis Model
| | Library Name | IntegratedCircuits.IntLib | IntegratedCircuits.IntLib
| | Library Reference | TP002 | TP002
| | PCB3D
| | Pin Info
| | Signal Integrity
| | Simulation
TP4008 | 3V3_SYS_SUPPLY.SchDoc | | Fitted | Fitted
| | Comment | Test point | Test point
| | Component Kind | Standard | Standard
| | Description | Test point 1mm | Test point 1mm
| | Footprint | TestPoint | TestPoint
| | Ibis Model
| | Library Name | IntegratedCircuits.IntLib | IntegratedCircuits.IntLib
| | Library Reference | TP002 | TP002
| | PCB3D
| | Pin Info
| | Signal Integrity
| | Simulation
TP4009 | 3V3_SYS_SUPPLY.SchDoc | | Fitted | Fitted
| | Comment | Test point | Test point
| | Component Kind | Standard | Standard
| | Description | Test point 1mm | Test point 1mm
| | Footprint | TestPoint | TestPoint
| | Ibis Model
| | Library Name | IntegratedCircuits.IntLib | IntegratedCircuits.IntLib
| | Library Reference | TP002 | TP002
| | PCB3D
| | Pin Info
| | Signal Integrity
| | Simulation
TP5000 | 5V0_EXT_SUPPLY.SchDoc | | Fitted | Fitted
| | Comment | Test point | Test point
| | Component Kind | Standard | Standard
| | Description | Test point 1mm | Test point 1mm
| | Footprint | TestPoint | TestPoint
| | Ibis Model
| | Library Name | IntegratedCircuits.IntLib | IntegratedCircuits.IntLib
| | Library Reference | TP002 | TP002
| | PCB3D
| | Pin Info
| | Signal Integrity
| | Simulation
TP5001 | 5V0_EXT_SUPPLY.SchDoc | | Fitted | Fitted
| | Comment | Test point | Test point
| | Component Kind | Standard | Standard
| | Description | Test point 1mm | Test point 1mm
| | Footprint | TestPoint | TestPoint
| | Ibis Model
| | Library Name | IntegratedCircuits.IntLib | IntegratedCircuits.IntLib
| | Library Reference | TP002 | TP002
| | PCB3D
| | Pin Info
| | Signal Integrity
| | Simulation
TP5002 | 5V0_EXT_SUPPLY.SchDoc | | Fitted | Fitted
| | Comment | Test point | Test point
| | Component Kind | Standard | Standard
| | Description | Test point 1mm | Test point 1mm
| | Footprint | TestPoint | TestPoint
| | Ibis Model
| | Library Name | IntegratedCircuits.IntLib | IntegratedCircuits.IntLib
| | Library Reference | TP002 | TP002
| | PCB3D
| | Pin Info
| | Signal Integrity
| | Simulation
TP5003 | 5V0_EXT_SUPPLY.SchDoc | | Fitted | Fitted
| | Comment | Test point | Test point
| | Component Kind | Standard | Standard
| | Description | Test point 1mm | Test point 1mm
| | Footprint | TestPoint | TestPoint
| | Ibis Model
| | Library Name | IntegratedCircuits.IntLib | IntegratedCircuits.IntLib
| | Library Reference | TP002 | TP002
| | PCB3D
| | Pin Info
| | Signal Integrity
| | Simulation
TP5004 | 5V0_EXT_SUPPLY.SchDoc | | Fitted | Fitted
| | Comment | Test point | Test point
| | Component Kind | Standard | Standard
| | Description | Test point 1mm | Test point 1mm
| | Footprint | TestPoint | TestPoint
| | Ibis Model
| | Library Name | IntegratedCircuits.IntLib | IntegratedCircuits.IntLib
| | Library Reference | TP002 | TP002
| | PCB3D
| | Pin Info
| | Signal Integrity
| | Simulation
TP5005 | 5V0_EXT_SUPPLY.SchDoc | | Fitted | Fitted
| | Comment | Test point | Test point
| | Component Kind | Standard | Standard
| | Description | Test point 1mm | Test point 1mm
| | Footprint | TestPoint | TestPoint
| | Ibis Model
| | Library Name | IntegratedCircuits.IntLib | IntegratedCircuits.IntLib
| | Library Reference | TP002 | TP002
| | PCB3D
| | Pin Info
| | Signal Integrity
| | Simulation
TP5006 | 5V0_EXT_SUPPLY.SchDoc | | Fitted | Fitted
| | Comment | Test point | Test point
| | Component Kind | Standard | Standard
| | Description | Test point 1mm | Test point 1mm
| | Footprint | TestPoint | TestPoint
| | Ibis Model
| | Library Name | IntegratedCircuits.IntLib | IntegratedCircuits.IntLib
| | Library Reference | TP002 | TP002
| | PCB3D
| | Pin Info
| | Signal Integrity
| | Simulation
TP5007 | 5V0_EXT_SUPPLY.SchDoc | | Fitted | Fitted
| | Comment | Test point | Test point
| | Component Kind | Standard | Standard
| | Description | Test point 1mm | Test point 1mm
| | Footprint | TestPoint | TestPoint
| | Ibis Model
| | Library Name | IntegratedCircuits.IntLib | IntegratedCircuits.IntLib
| | Library Reference | TP002 | TP002
| | PCB3D
| | Pin Info
| | Signal Integrity
| | Simulation
TP5008 | 5V0_EXT_SUPPLY.SchDoc | | Fitted | Fitted
| | Comment | Test point | Test point
| | Component Kind | Standard | Standard
| | Description | Test point 1mm | Test point 1mm
| | Footprint | TestPoint | TestPoint
| | Ibis Model
| | Library Name | IntegratedCircuits.IntLib | IntegratedCircuits.IntLib
| | Library Reference | TP002 | TP002
| | PCB3D
| | Pin Info
| | Signal Integrity
| | Simulation
TP5009 | 5V0_EXT_SUPPLY.SchDoc | | Fitted | Fitted
| | Comment | Test point | Test point
| | Component Kind | Standard | Standard
| | Description | Test point 1mm | Test point 1mm
| | Footprint | TestPoint | TestPoint
| | Ibis Model
| | Library Name | IntegratedCircuits.IntLib | IntegratedCircuits.IntLib
| | Library Reference | TP002 | TP002
| | PCB3D
| | Pin Info
| | Signal Integrity
| | Simulation
TP6000 | 3V3_MCU_SUPPLY.SchDoc | | Fitted | Fitted
| | Comment | Test point | Test point
| | Component Kind | Standard | Standard
| | Description | Test point 1mm | Test point 1mm
| | Footprint | TestPoint | TestPoint
| | Ibis Model
| | Library Name | IntegratedCircuits.IntLib | IntegratedCircuits.IntLib
| | Library Reference | TP002 | TP002
| | PCB3D
| | Pin Info
| | Signal Integrity
| | Simulation
TP6001 | 3V3_MCU_SUPPLY.SchDoc | | Fitted | Fitted
| | Comment | Test point | Test point
| | Component Kind | Standard | Standard
| | Description | Test point 1mm | Test point 1mm
| | Footprint | TestPoint | TestPoint
| | Ibis Model
| | Library Name | IntegratedCircuits.IntLib | IntegratedCircuits.IntLib
| | Library Reference | TP002 | TP002
| | PCB3D
| | Pin Info
| | Signal Integrity
| | Simulation
TP6002 | 3V3_MCU_SUPPLY.SchDoc | | Fitted | Fitted
| | Comment | Test point | Test point
| | Component Kind | Standard | Standard
| | Description | Test point 1mm | Test point 1mm
| | Footprint | TestPoint | TestPoint
| | Ibis Model
| | Library Name | IntegratedCircuits.IntLib | IntegratedCircuits.IntLib
| | Library Reference | TP002 | TP002
| | PCB3D
| | Pin Info
| | Signal Integrity
| | Simulation
TP6003 | 3V3_MCU_SUPPLY.SchDoc | | Fitted | Fitted
| | Comment | Test point | Test point
| | Component Kind | Standard | Standard
| | Description | Test point 1mm | Test point 1mm
| | Footprint | TestPoint | TestPoint
| | Ibis Model
| | Library Name | IntegratedCircuits.IntLib | IntegratedCircuits.IntLib
| | Library Reference | TP002 | TP002
| | PCB3D
| | Pin Info
| | Signal Integrity
| | Simulation
TP6004 | 3V3_MCU_SUPPLY.SchDoc | | Fitted | Fitted
| | Comment | Test point | Test point
| | Component Kind | Standard | Standard
| | Description | Test point 1mm | Test point 1mm
| | Footprint | TestPoint | TestPoint
| | Ibis Model
| | Library Name | IntegratedCircuits.IntLib | IntegratedCircuits.IntLib
| | Library Reference | TP002 | TP002
| | PCB3D
| | Pin Info
| | Signal Integrity
| | Simulation
TP6005 | 3V3_MCU_SUPPLY.SchDoc | | Fitted | Fitted
| | Comment | Test point | Test point
| | Component Kind | Standard | Standard
| | Description | Test point 1mm | Test point 1mm
| | Footprint | TestPoint | TestPoint
| | Ibis Model
| | Library Name | IntegratedCircuits.IntLib | IntegratedCircuits.IntLib
| | Library Reference | TP002 | TP002
| | PCB3D
| | Pin Info
| | Signal Integrity
| | Simulation
TP6006 | 3V3_MCU_SUPPLY.SchDoc | | Fitted | Fitted
| | Comment | Test point | Test point
| | Component Kind | Standard | Standard
| | Description | Test point 1mm | Test point 1mm
| | Footprint | TestPoint | TestPoint
| | Ibis Model
| | Library Name | IntegratedCircuits.IntLib | IntegratedCircuits.IntLib
| | Library Reference | TP002 | TP002
| | PCB3D
| | Pin Info
| | Signal Integrity
| | Simulation
TP6007 | 3V3_MCU_SUPPLY.SchDoc | | Fitted | Fitted
| | Comment | Test point | Test point
| | Component Kind | Standard | Standard
| | Description | Test point 1mm | Test point 1mm
| | Footprint | TestPoint | TestPoint
| | Ibis Model
| | Library Name | IntegratedCircuits.IntLib | IntegratedCircuits.IntLib
| | Library Reference | TP002 | TP002
| | PCB3D
| | Pin Info
| | Signal Integrity
| | Simulation
ZD1000 | Reverse_Protection.SchDoc | | Fitted | Fitted
| | Comment | DZ23C15-E3-08 Zener Diode | DZ23C15-E3-08 Zener Diode
| | Component Kind | Standard | Standard
| | ComponentLink1Description | DigiKey | DigiKey
| | ComponentLink1URL | https://www.digikey.com/en/products/detail/vishay-general-semiconductor-diodes-division/DZ23C15-E3-08/4831460 | https://www.digikey.com/en/products/detail/vishay-general-semiconductor-diodes-division/DZ23C15-E3-08/4831460
| | Description | Zener Diode Array 1 Pair Common Cathode 15 V 300 mW ±5% SOT-23-3 | Zener Diode Array 1 Pair Common Cathode 15 V 300 mW ±5% SOT-23-3
| | DigiKey Part Number | 112-DZ23C15-E3-08CT-ND | 112-DZ23C15-E3-08CT-ND
| | Footprint | SOT95P245X96-3N | SOT95P245X96-3N
| | Ibis Model
| | Library Name | Miscellaneous_Lib1.IntLib | Miscellaneous_Lib1.IntLib
| | Library Reference | 00000006 | 00000006
| | PCB3D
| | Pin Info
| | Signal Integrity
| | Simulation
ZD1001 | Reverse_Protection.SchDoc | | Fitted | Fitted
| | Comment | DZ23C15-E3-08 Zener Diode | DZ23C15-E3-08 Zener Diode
| | Component Kind | Standard | Standard
| | ComponentLink1Description | DigiKey | DigiKey
| | ComponentLink1URL | https://www.digikey.com/en/products/detail/vishay-general-semiconductor-diodes-division/DZ23C15-E3-08/4831460 | https://www.digikey.com/en/products/detail/vishay-general-semiconductor-diodes-division/DZ23C15-E3-08/4831460
| | Description | Zener Diode Array 1 Pair Common Cathode 15 V 300 mW ±5% SOT-23-3 | Zener Diode Array 1 Pair Common Cathode 15 V 300 mW ±5% SOT-23-3
| | DigiKey Part Number | 112-DZ23C15-E3-08CT-ND | 112-DZ23C15-E3-08CT-ND
| | Footprint | SOT95P245X96-3N | SOT95P245X96-3N
| | Ibis Model
| | Library Name | Miscellaneous_Lib1.IntLib | Miscellaneous_Lib1.IntLib
| | Library Reference | 00000006 | 00000006
| | PCB3D
| | Pin Info
| | Signal Integrity
| | Simulation
ZD1002 | Reverse_Protection.SchDoc | | Fitted | Fitted

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

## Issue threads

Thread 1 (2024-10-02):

LM25148 12V Motor supply

Ax2Electronics, 2024-10-02:
Changes to be implemented on initial design:

- [x] I:  PI filter on supply input:
             1. Place 2.2uF high power Filter inductor
             2. Place 0.47uF 50V Filter capacitor
             3. place 330uF 50V Electrolytic Alu dumping capacitor with ESR around 0.082mOhm

- [x] II:  Remove 2 10uF input capacitors and add 4 100nF 50V capacitors
- [x] III: The switching inductor needs to be changed to 2.2uH if possible, to stay on the safe side.
- [x] IV:  Check in WCA if the option with 2 parallel mosfets can be used for better power handling.
- [x] V:  Add 0 ohm resistors on mosfets gates.
- [x] VI: Add placeholders for RC filter on current sense lines

Ax2Electronics, 2024-10-02:
IV: Option with 2 parallel mosfets, if calculated correctly, will lower power dissipation from 6.5W to 4W - the decision is to update the schematic with additional 2 power fets but to leave them unpopulated.

Closed 2024-10-04.

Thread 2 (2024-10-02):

Input reverse protection with LM7480-Q1

Ax2Electronics, 2024-10-02:
- [ ] Add LM7480-Q1 to the Altium component library.
- [ ] Calculate inrush current through fets for ~1500uF capacitive load, and add inrush limiting circuit if needed.
- [ ] Calculate max power dissipation on all fets:
                1. System VCC
                2. 12V supply
                3. 24V supply

Ax2Electronics, 2024-10-03:
The required max inrush current is set to 5A and the calculated gate capacitor is CdVdT = 6uF
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

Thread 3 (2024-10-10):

ATA6561 CAN Interface

Ax2Electronics, 2024-10-10:
- [ ] Add part to Altium component library together with OBD 9D connector
- [ ] Add 120Ohm optional termination resistor
- [ ] Route 3V3 supply as VIO supply and 5V0 to CAN VCC
- [ ] Consider the option for a common mode choke filter

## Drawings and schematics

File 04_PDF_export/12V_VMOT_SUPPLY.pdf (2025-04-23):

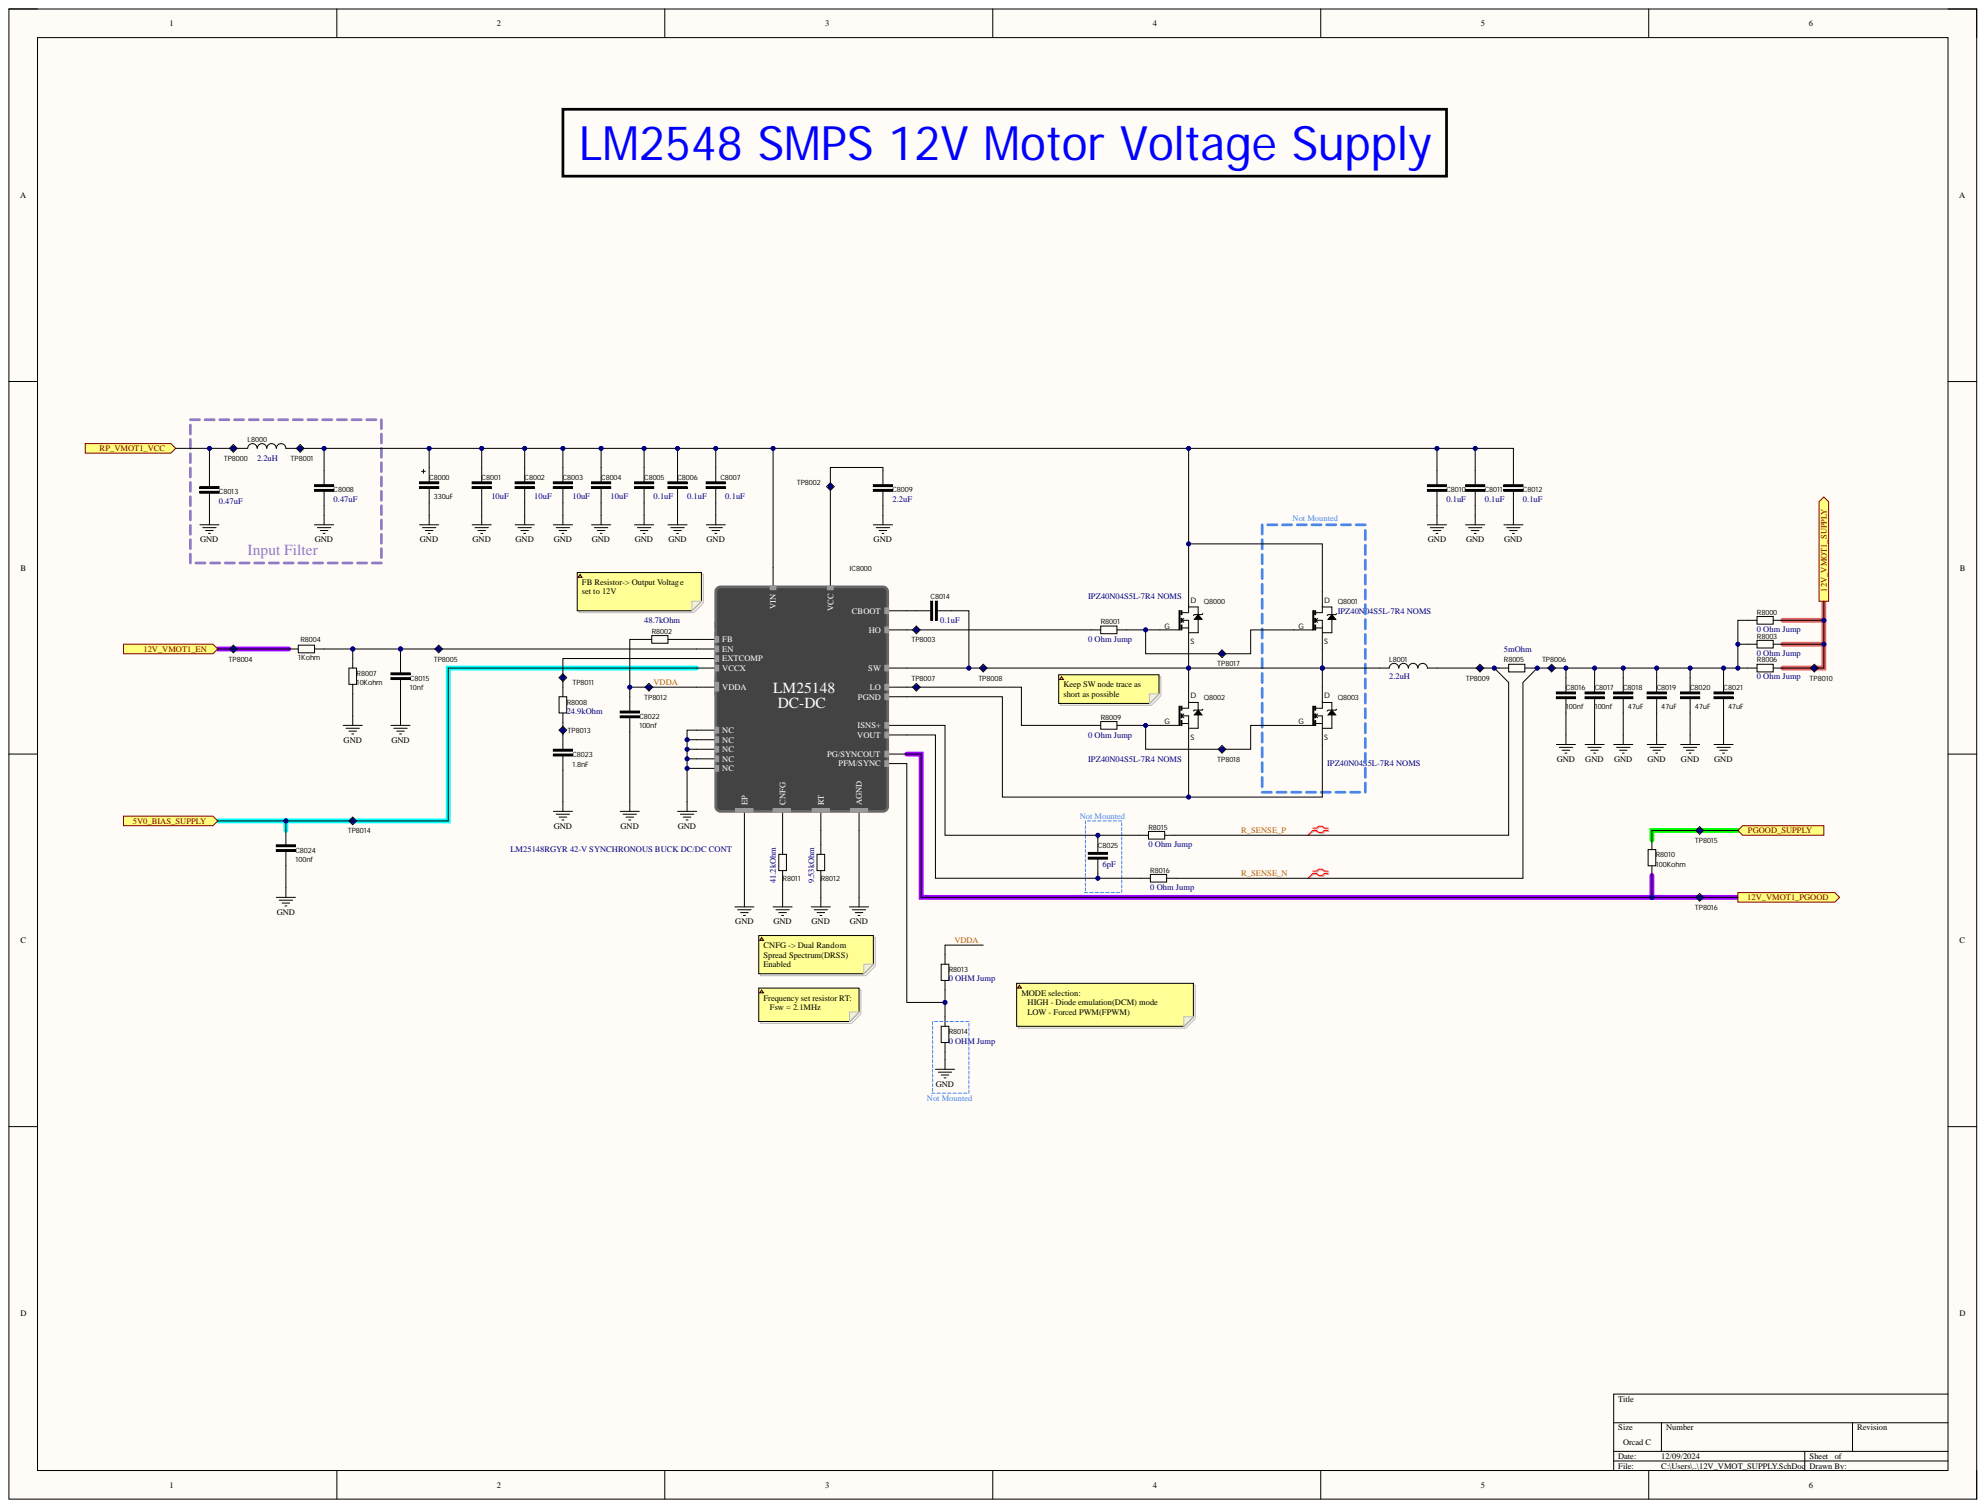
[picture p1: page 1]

LM2548 SMPS 12V Motor Voltage Supply

FB Resistor-> Output Voltage
set to 12V

Keep SW node trace as
short as possible

LM25148RGYR 42-V SYNCHRONOUS BUCK DC/DC CONT

Frequency set resistor RT:
Fsw = 2.1MHz

MODE selection:
HIGH - Diode emulation(DCM) mode
LOW - Forced PWM(FPWM)

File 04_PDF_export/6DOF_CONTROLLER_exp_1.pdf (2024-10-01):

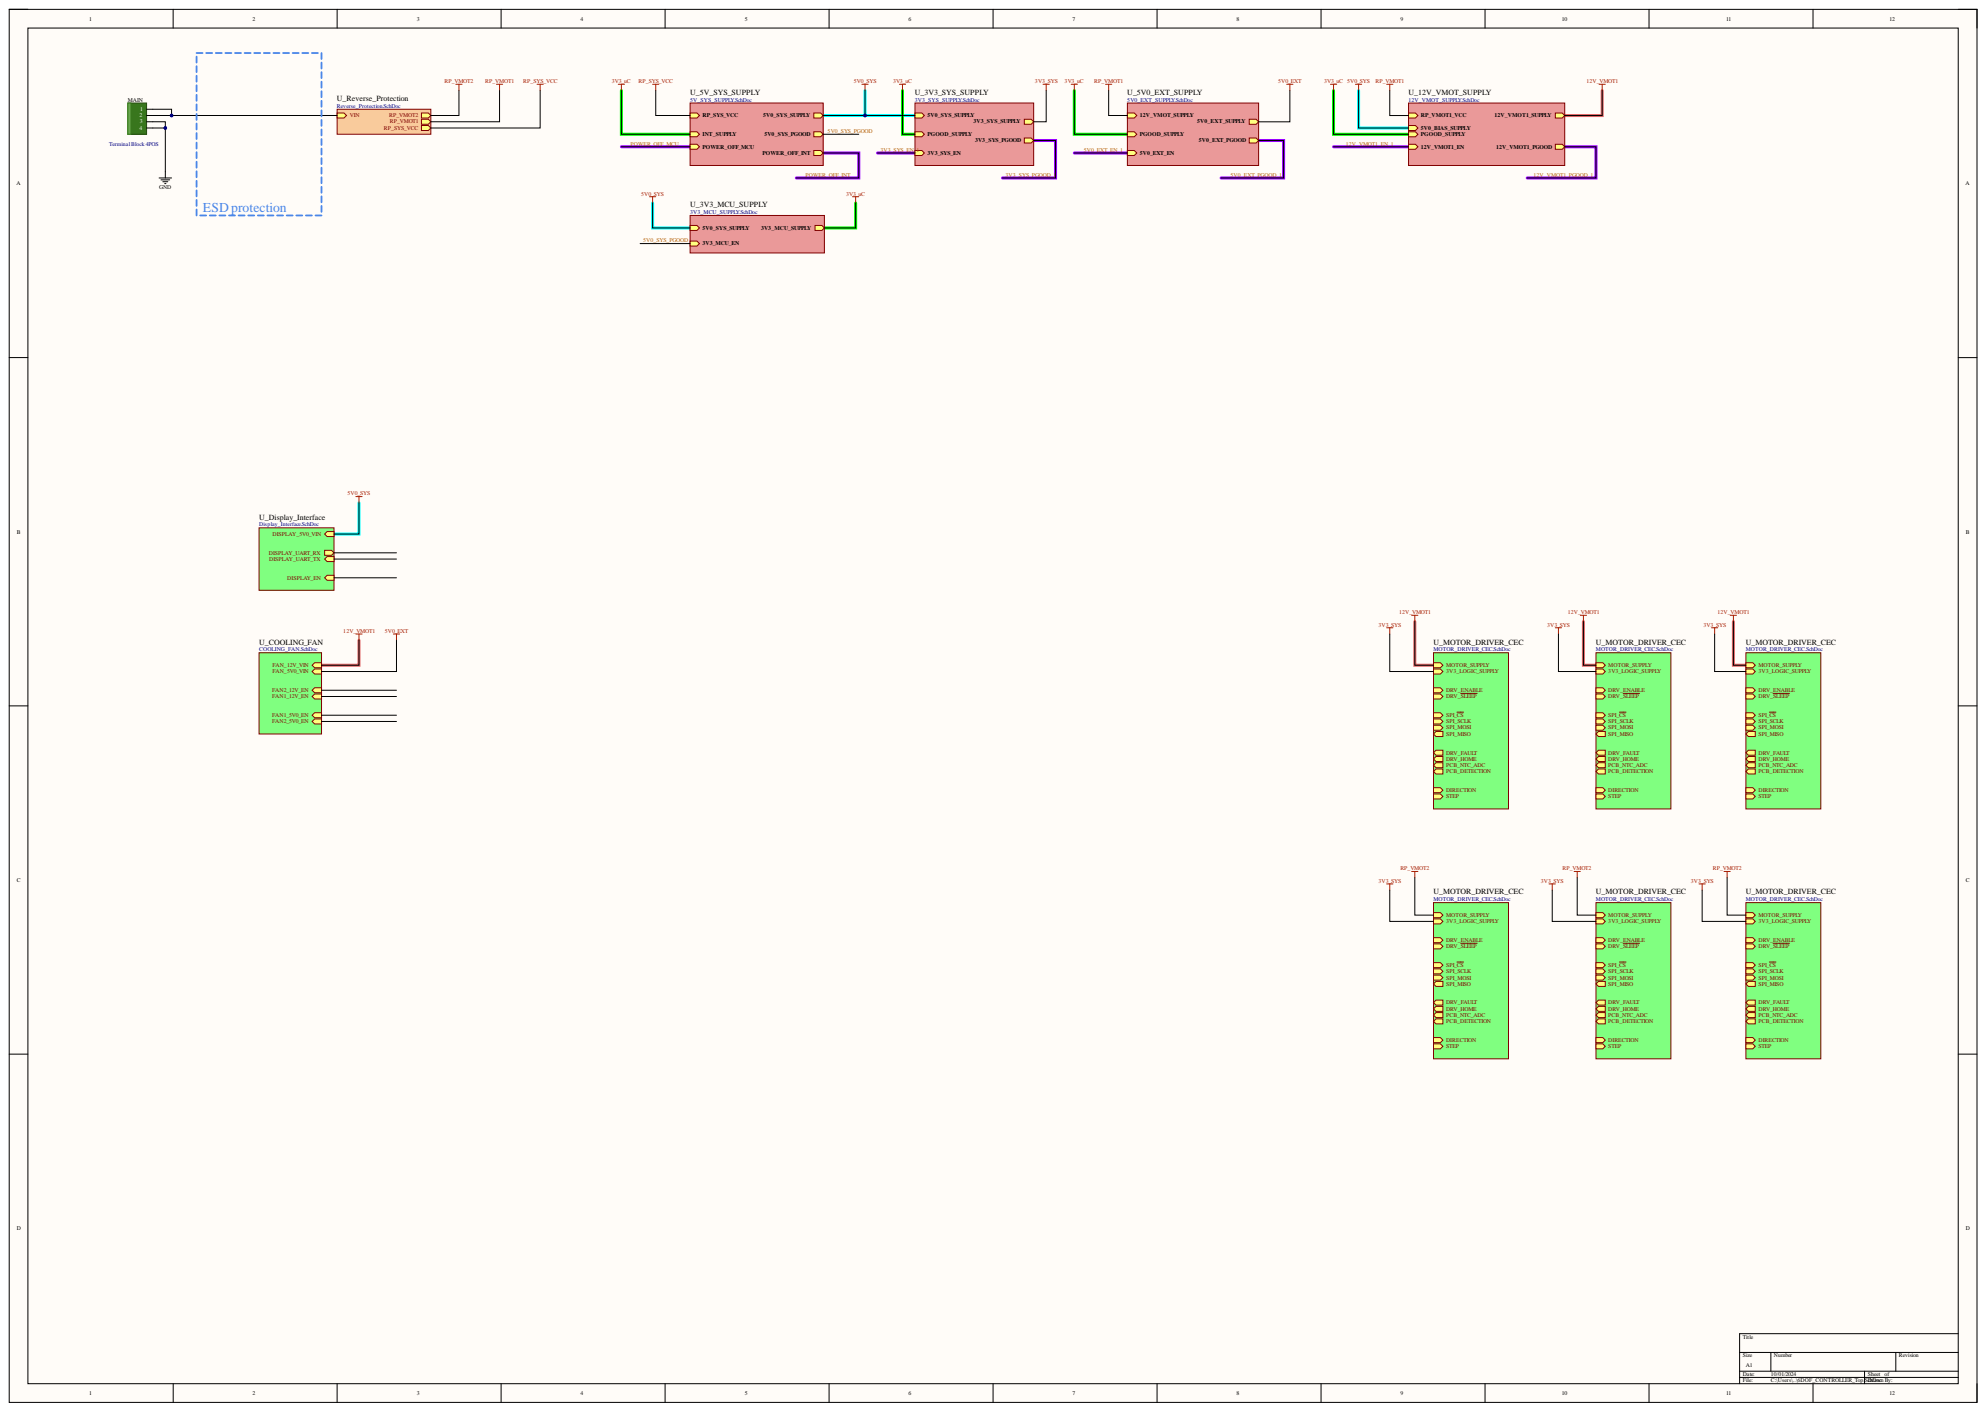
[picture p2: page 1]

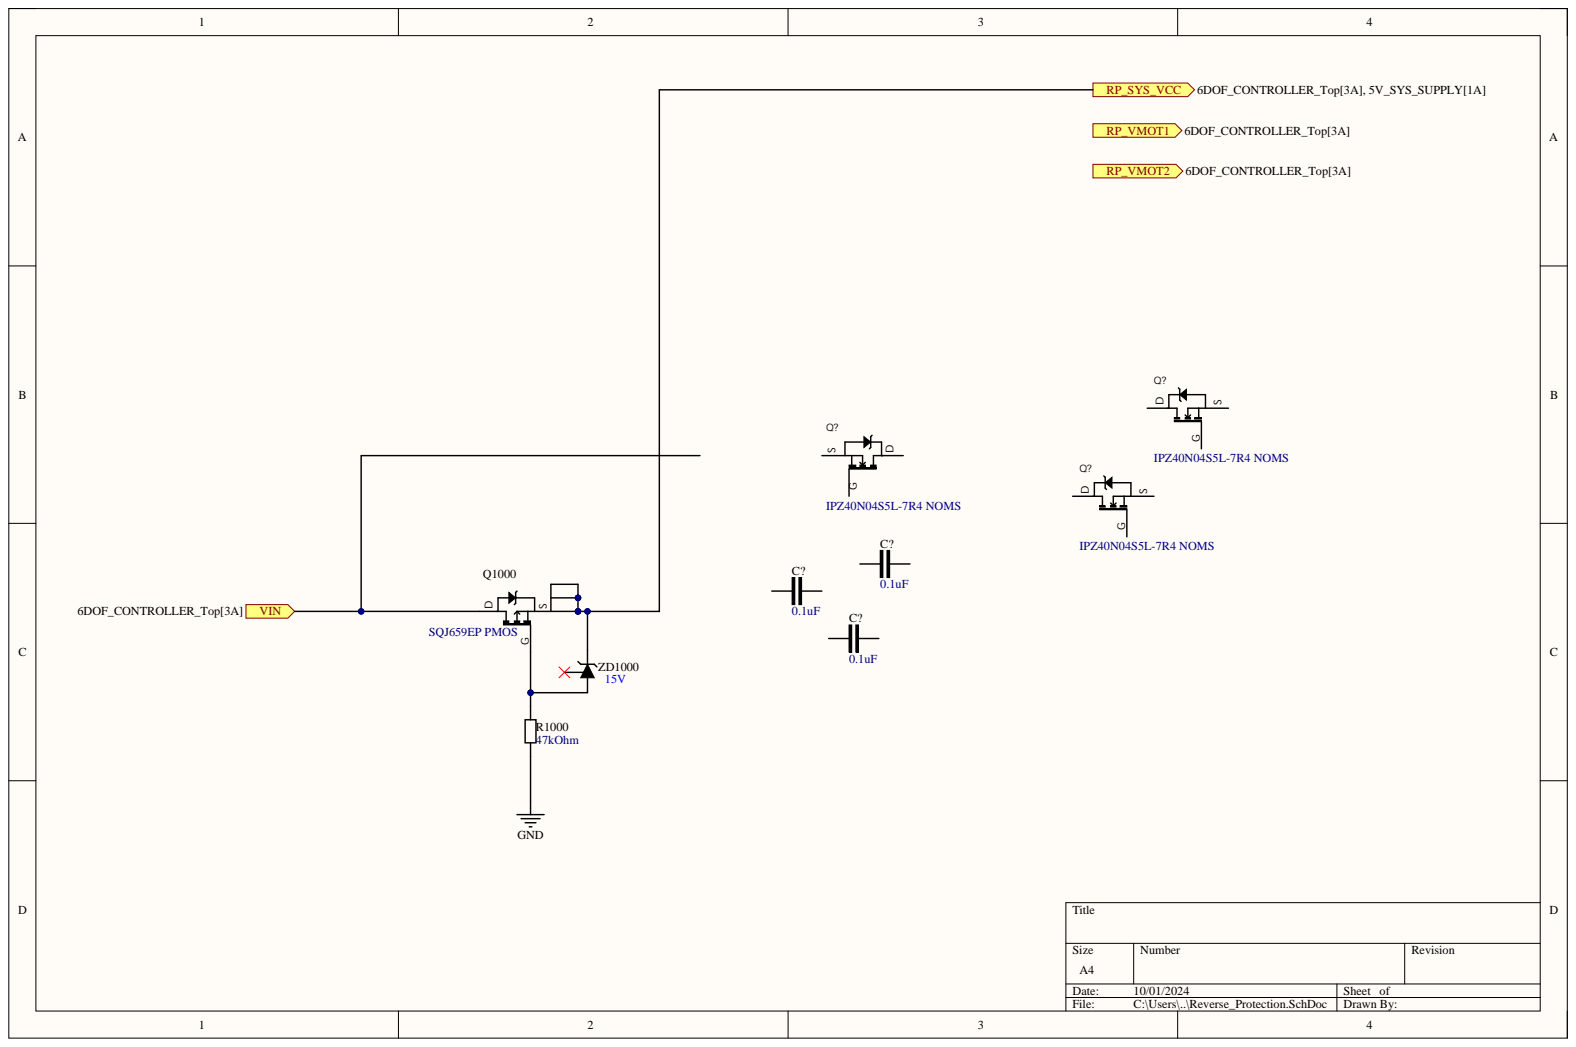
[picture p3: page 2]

Size A4 | Number | Revision

Date: 10/01/2024 | Sheet of
File: C:\Users\..\Reverse_Protection.SchDoc | Drawn By:

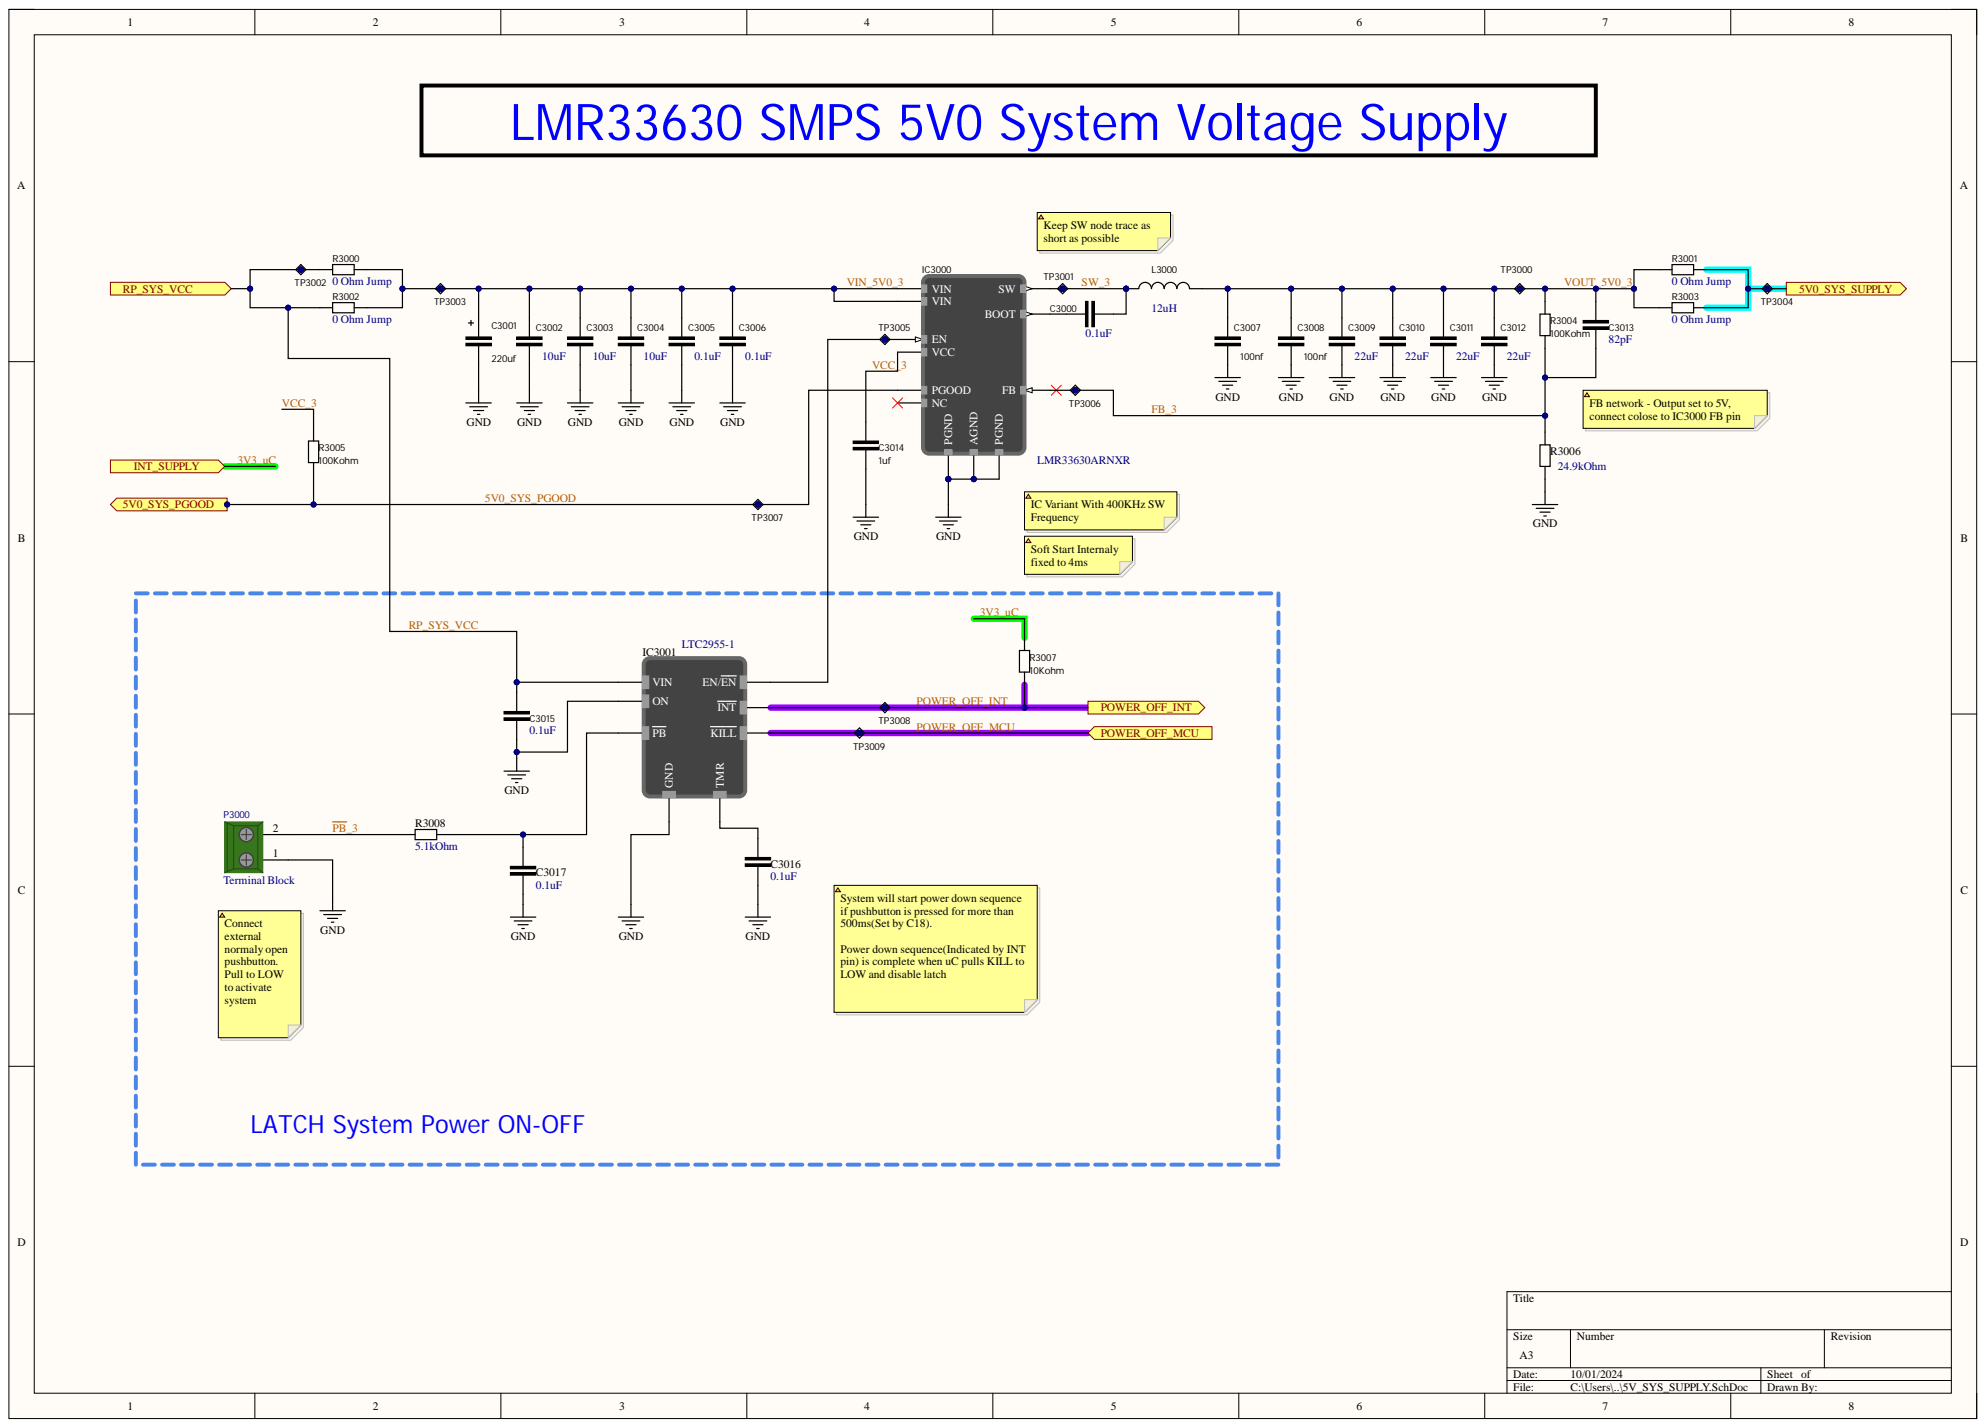
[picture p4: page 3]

LMR33630 SMPS 5V0 System Voltage Supply

Keep SW node trace as
short as possible

FB network - Output set to 5V,
connect colose to IC3000 FB pin

IC Variant With 400KHz SW
Frequency

System will start power down sequence
if pushbutton is pressed for more than
500ms(Set by C18).

Power down sequence(Indicated by INT
pin) is complete when uC pulls KILL to
LOW and disable latch

LATCH System Power ON-OFF

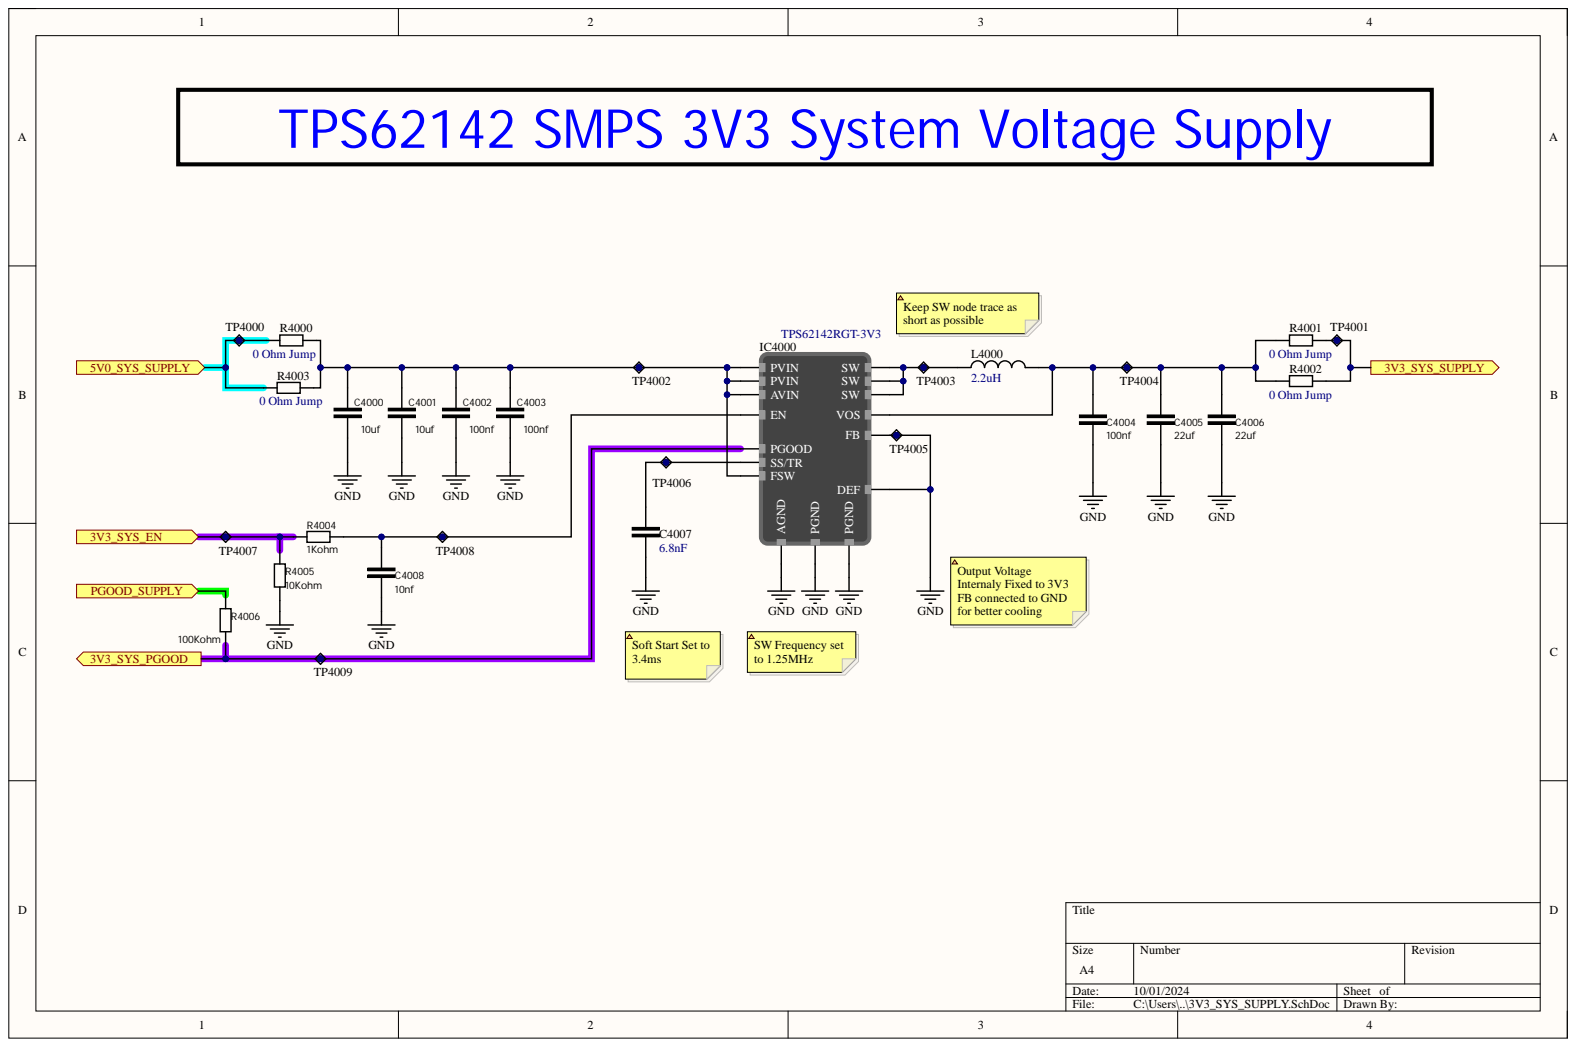
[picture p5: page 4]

TPS62142 SMPS 3V3 System Voltage Supply

Keep SW node trace as
short as possible

Soft Start Set to

Size A 4 | Numbe r | Revision

Date: 10/01/2024 | Sheet of
File: C:\Users\..\3V3_SYS_SUPPL Y.SchDoc | Drawn By:

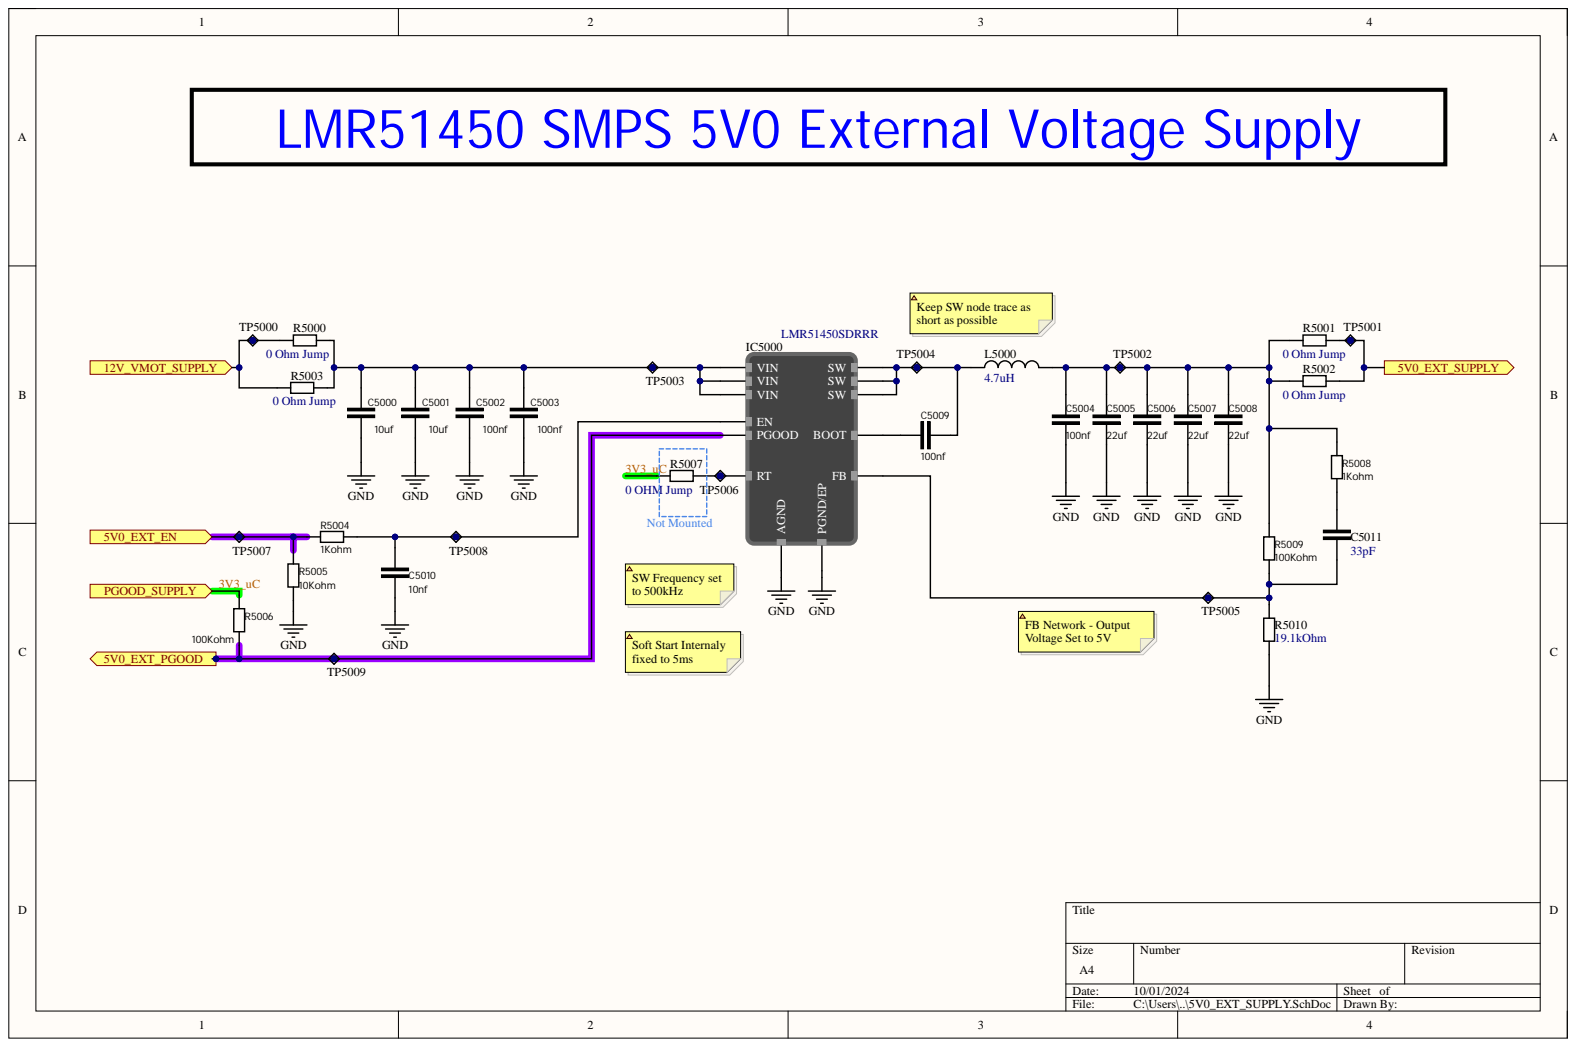
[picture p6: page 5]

LMR51450 SMPS 5V0 External Voltage Supply

Keep SW node trace as
short as possible

FB Network - Output Voltage Set to 5V Soft Start Internaly

Size A 4 | Numbe r | Revision

Date: 10/01/2024 | Sheet of
File: C:\Users\..\5V0_EXT_SUPPL Y.SchDoc | Drawn By:

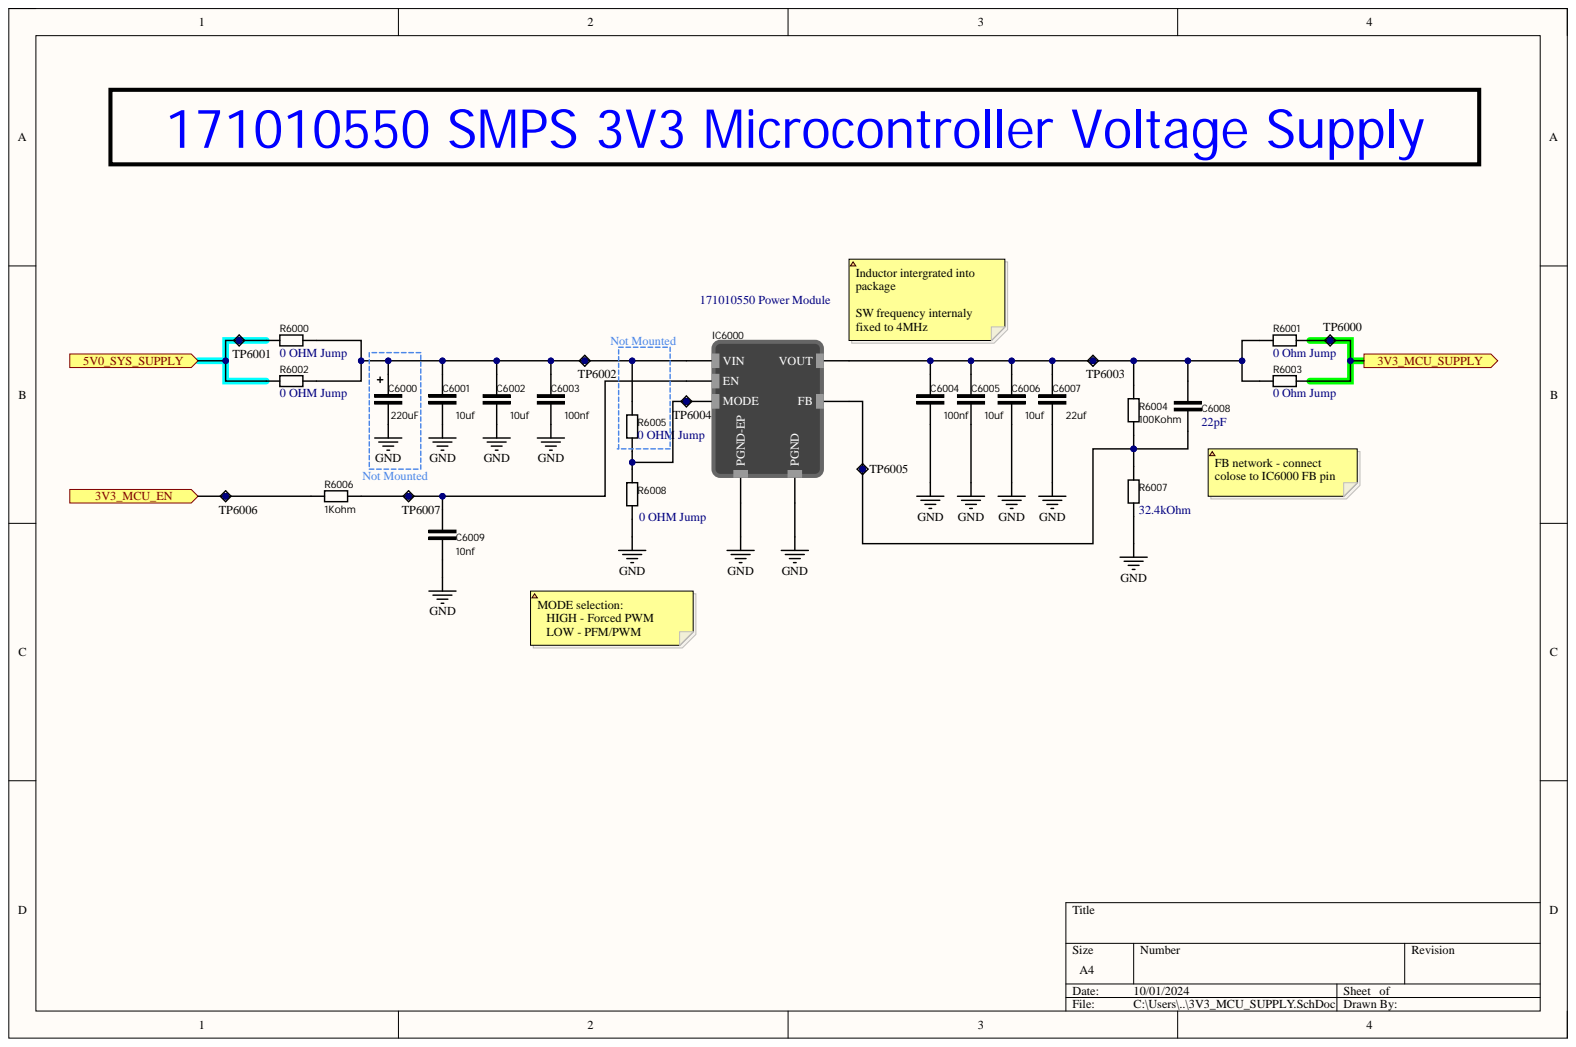
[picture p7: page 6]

171010550 SMPS 3V3 Microcontroller Voltage Supply

FB network - connect
colose to IC6000 FB pin

Size A 4 | Numbe r | Revision

Date: 10/01/2024 | Sheet of
File: C:\Users\..\3V3_MCU_SUPPL Y.SchDoc | Drawn By:

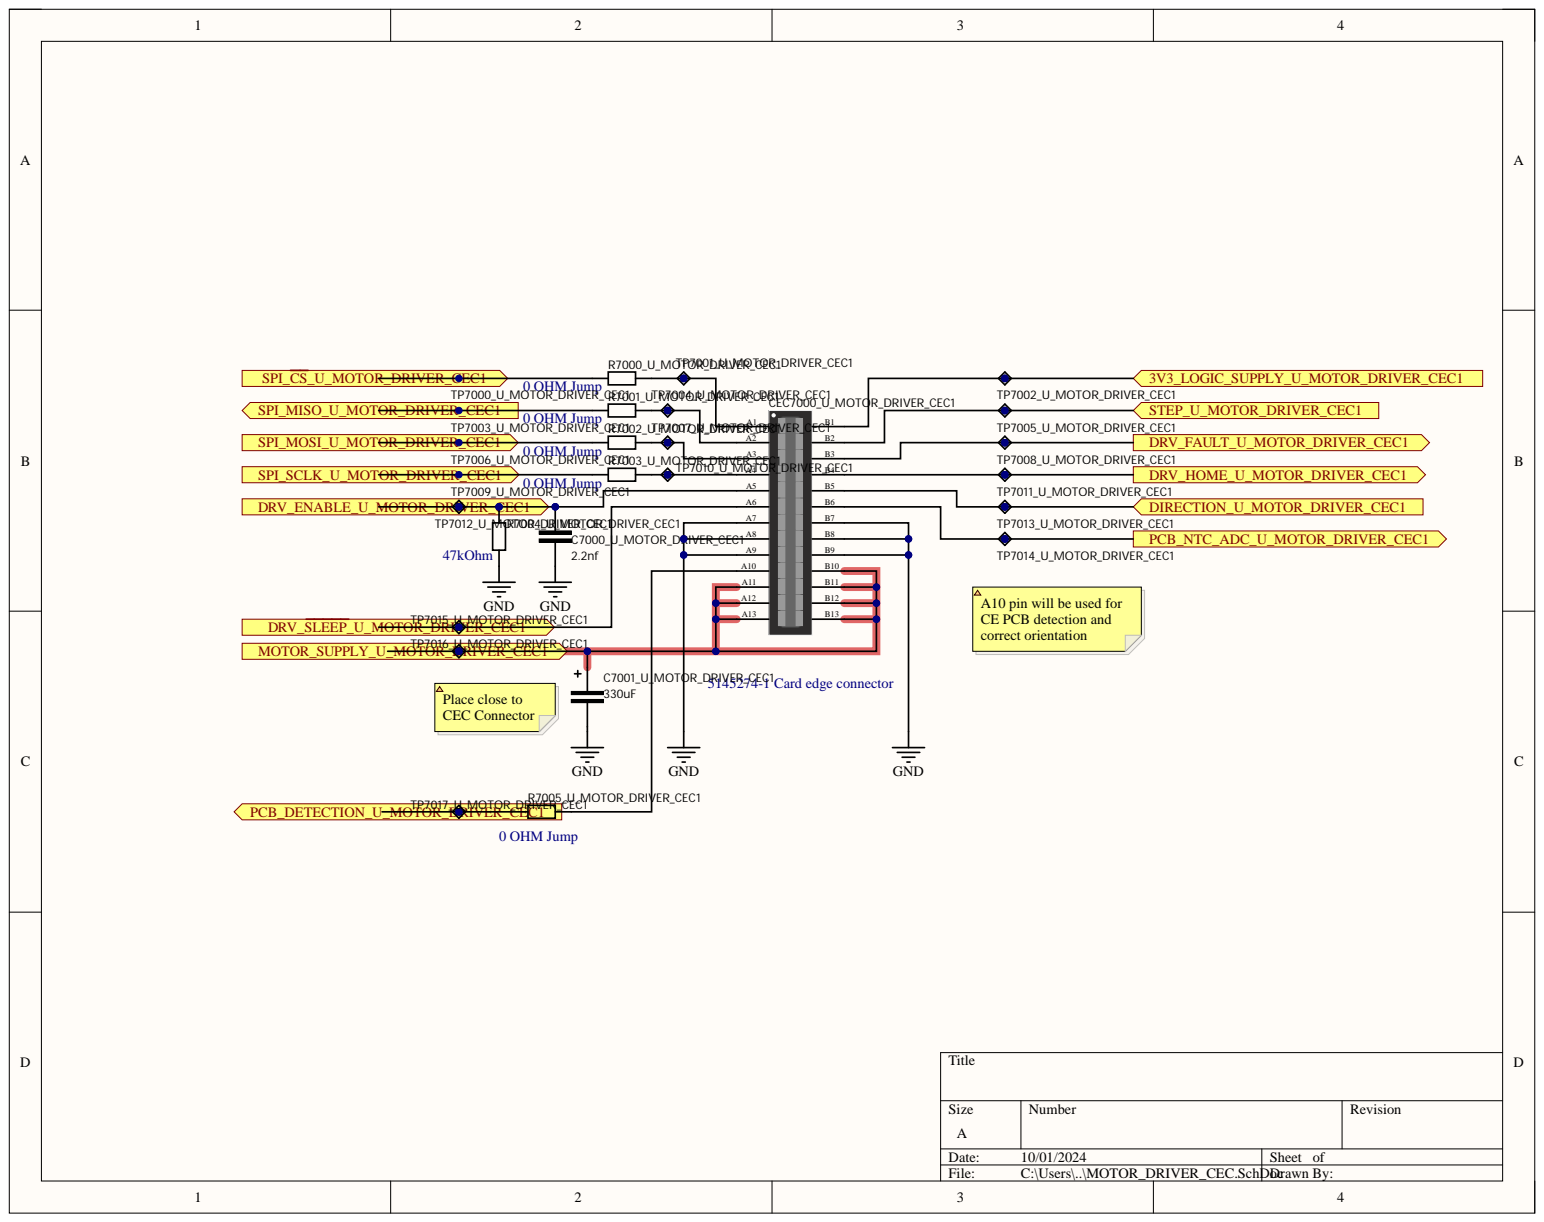
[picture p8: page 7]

A10 pin will be used for
CE PCB detection and
correct orientation

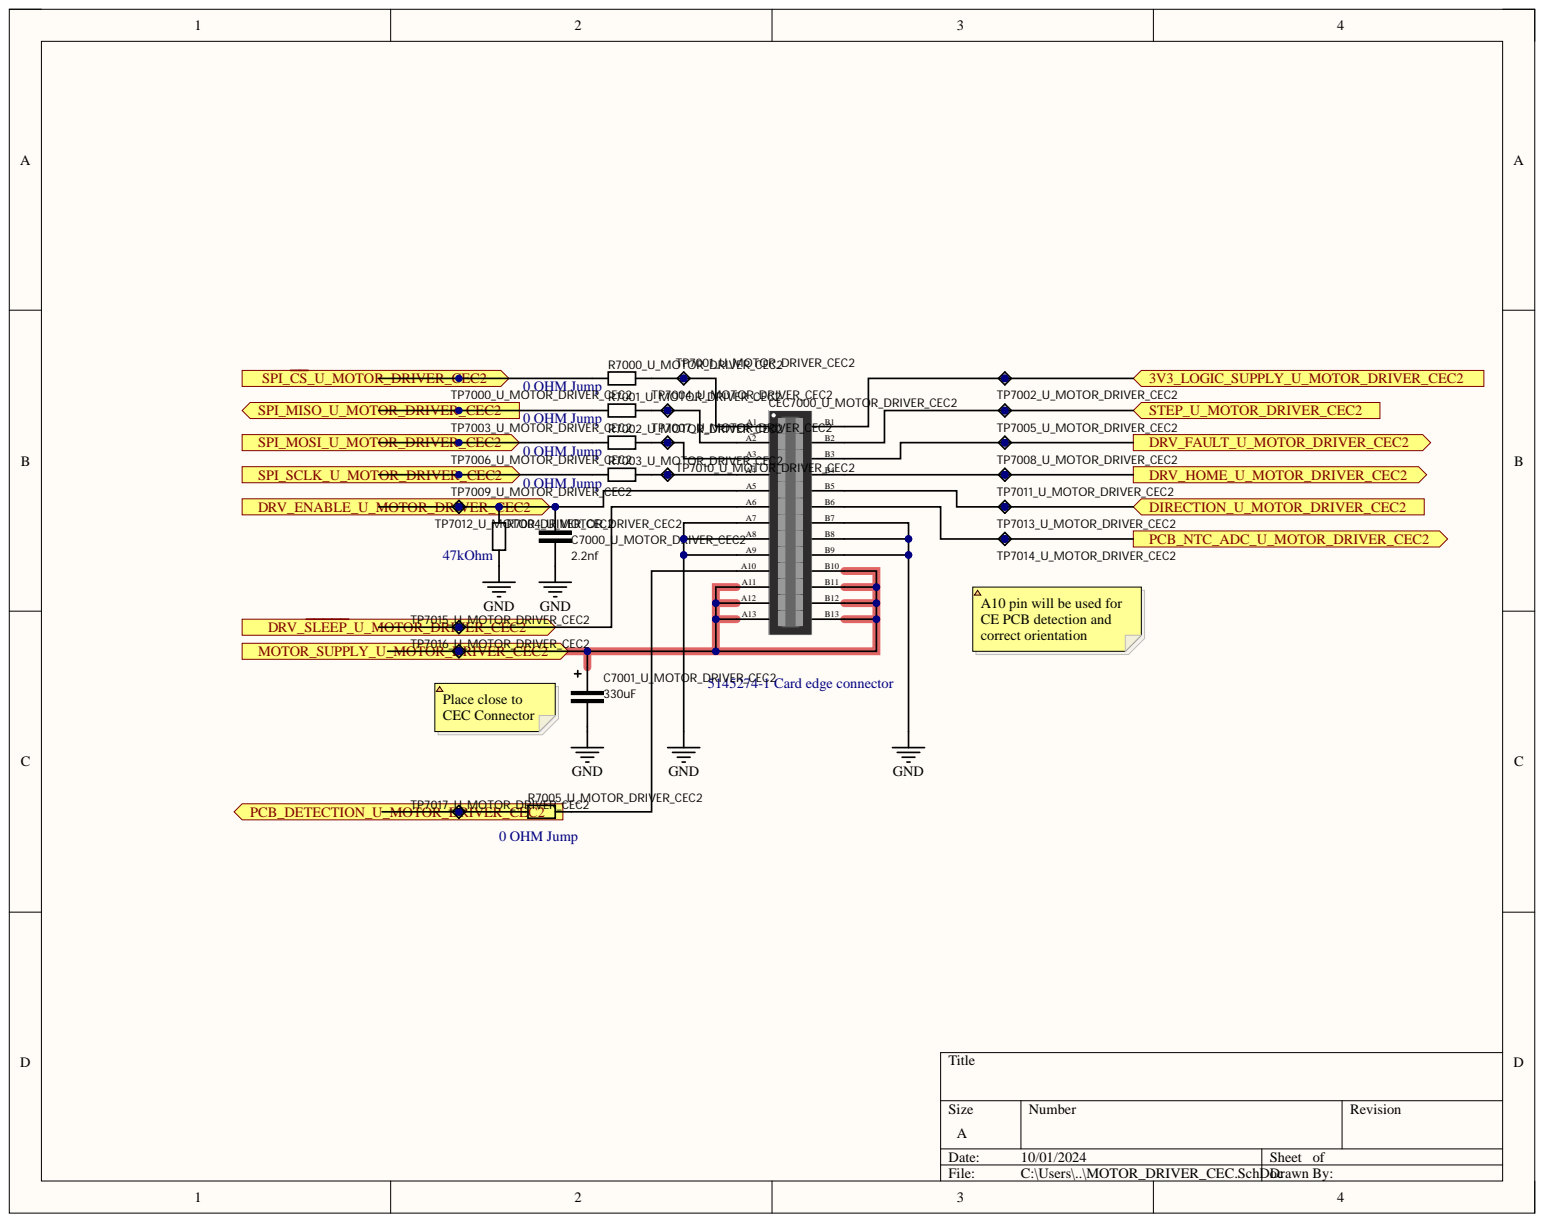
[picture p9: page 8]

A10 pin will be used for
CE PCB detection and
correct orientation

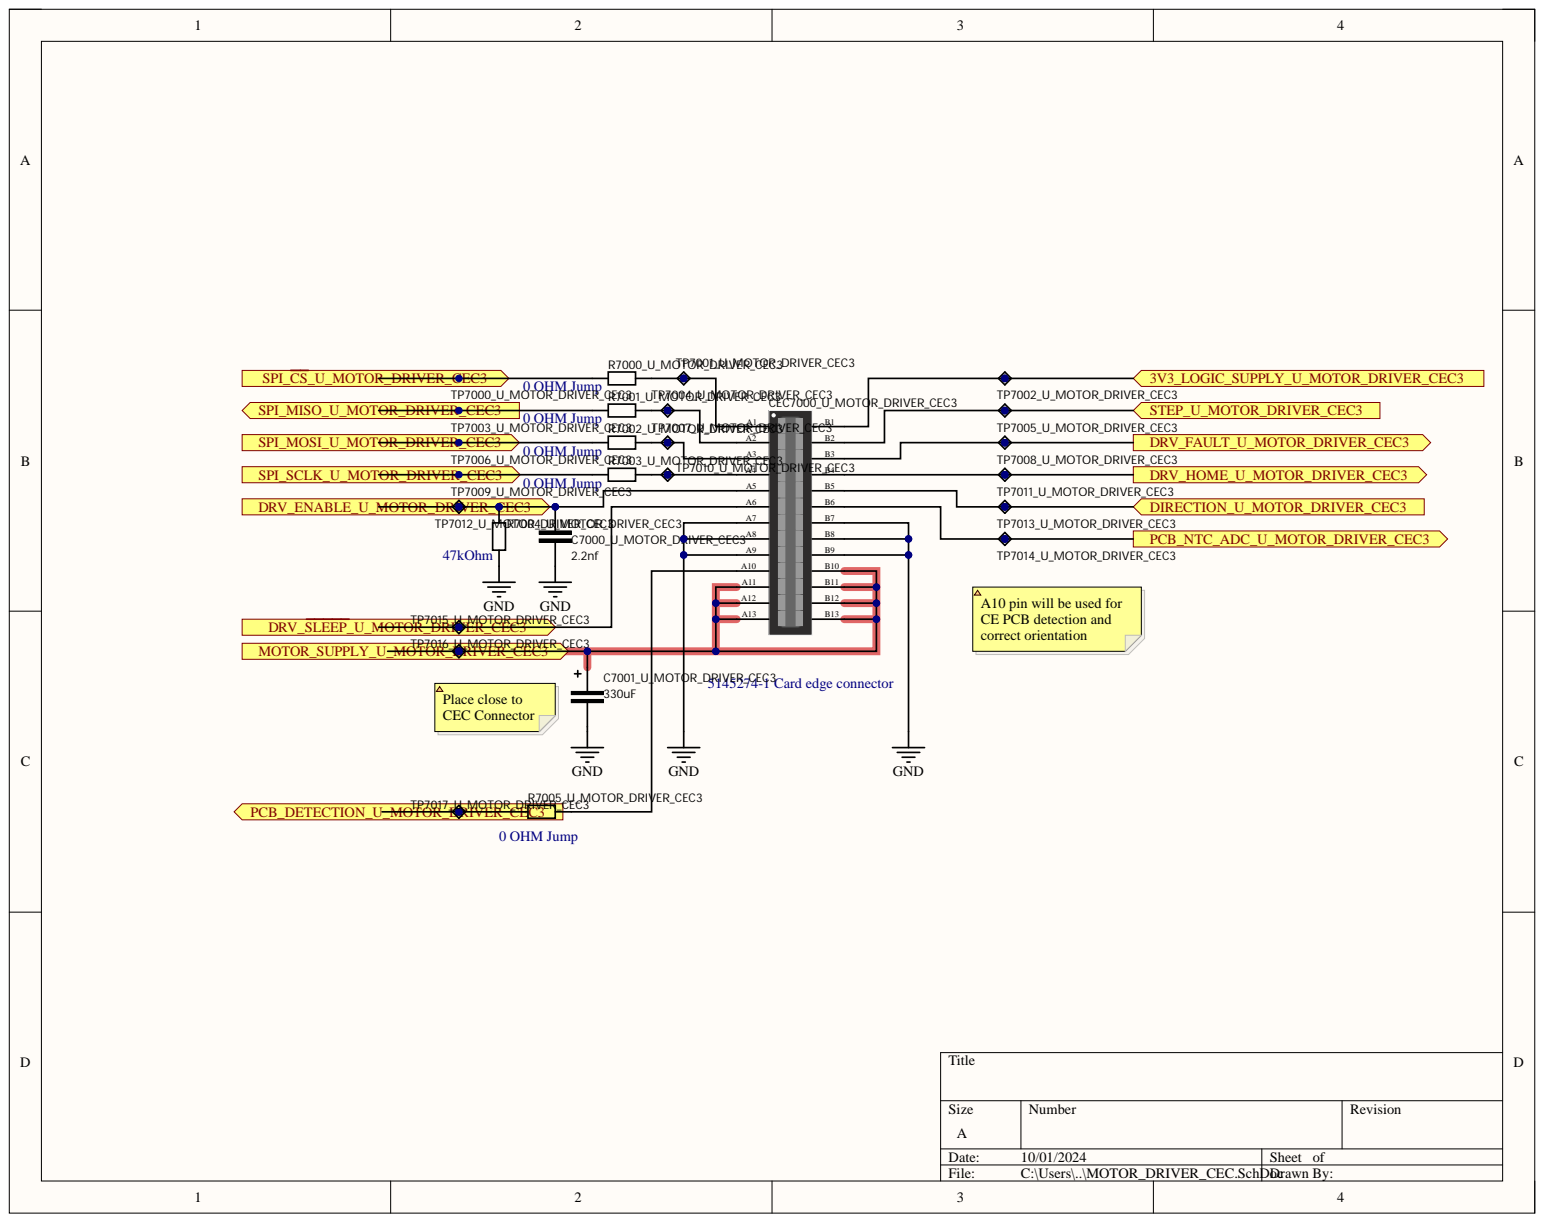
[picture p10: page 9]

A10 pin will be used for
CE PCB detection and
correct orientation

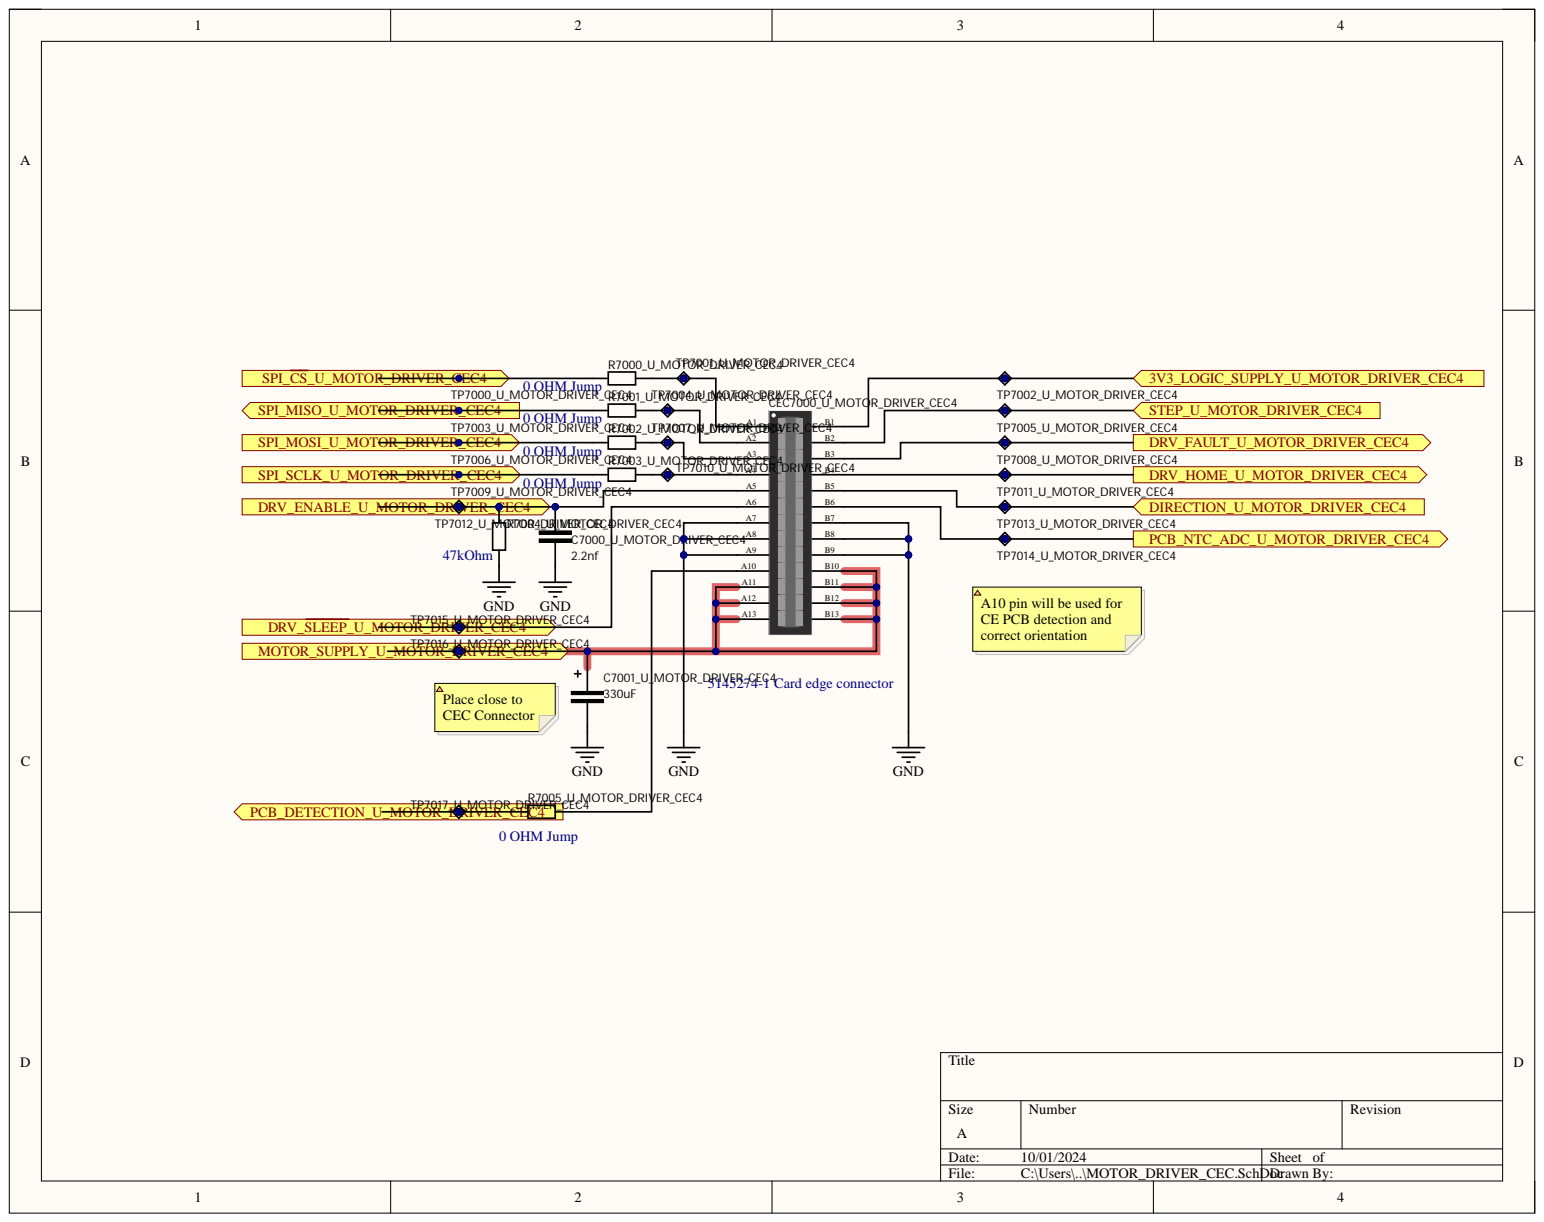
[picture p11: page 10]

A10 pin will be used for
CE PCB detection and
correct orientation

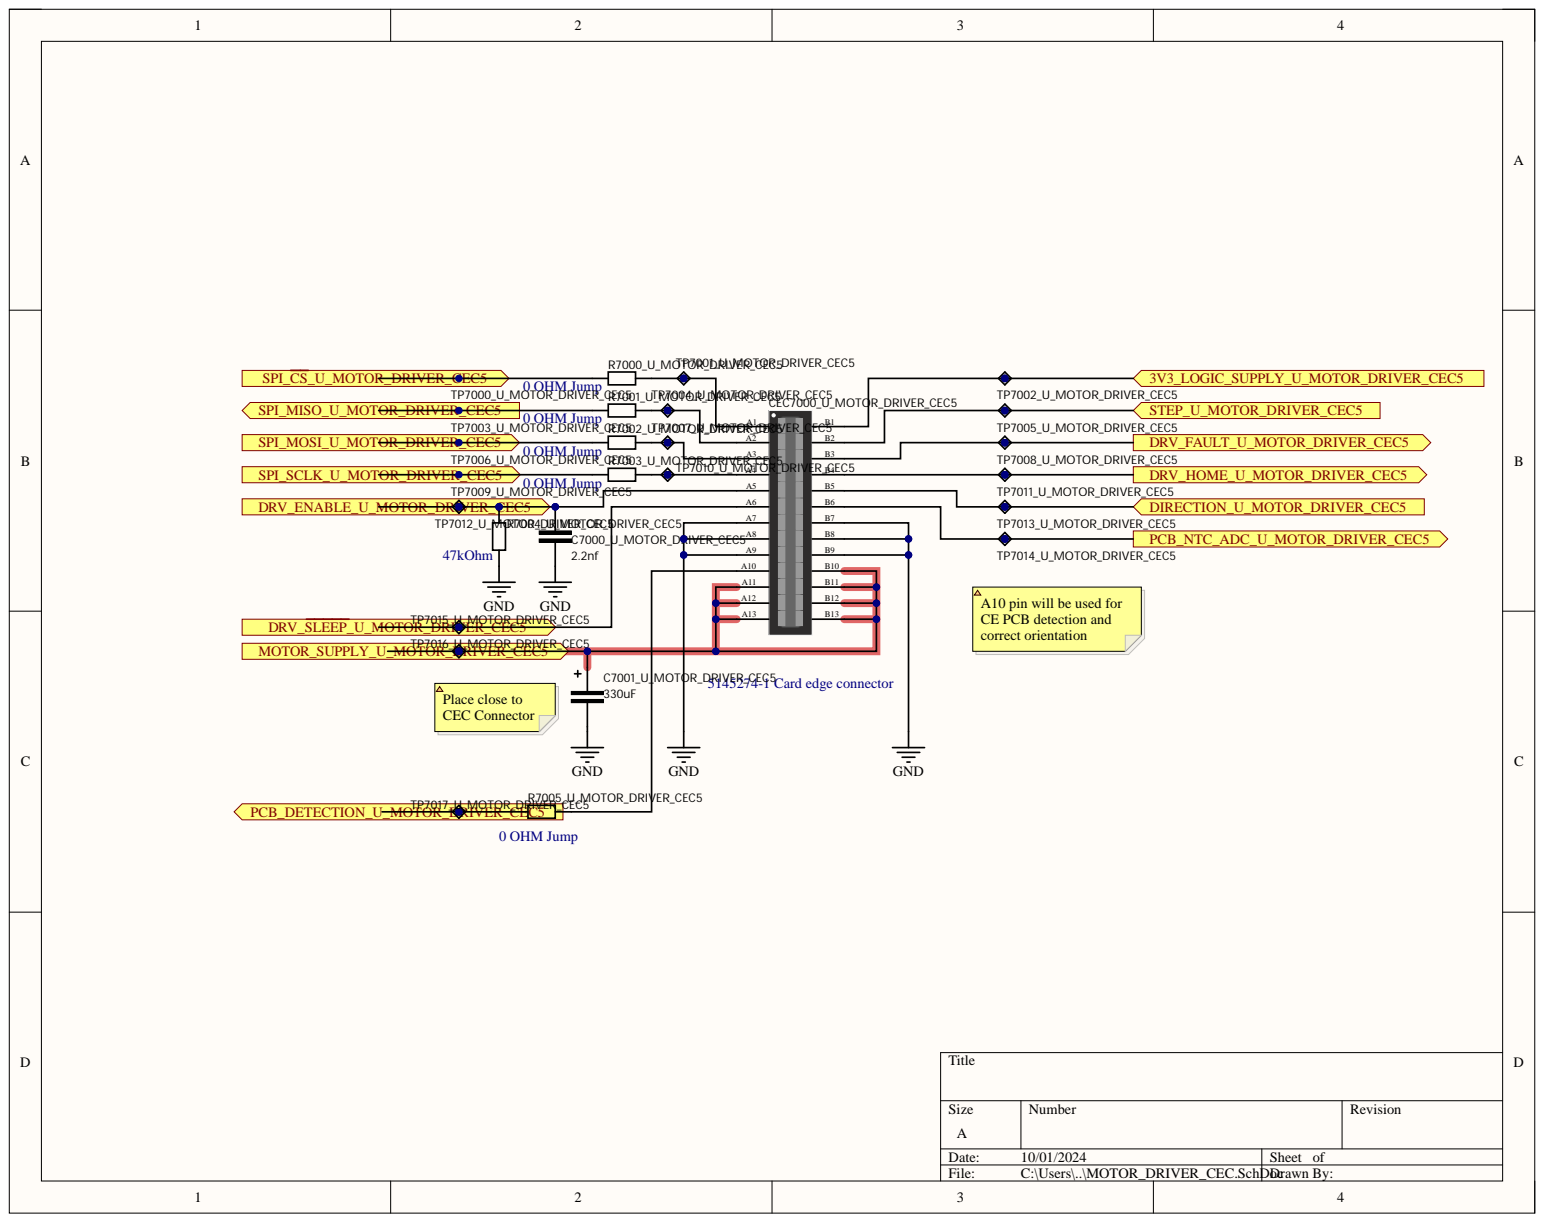
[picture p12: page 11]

A10 pin will be used for
CE PCB detection and
correct orientation


A10 pin will be used for
CE PCB detection and
correct orientation


LM2548 SMPS 12V Motor Voltage Supply

FB Resistor-> Output Voltage
set to 12V

Keep SW node trace as
short as possible

LM25148RGYR 42-V SYNCHRONOUS BUCK DC/DC CONT

Frequency set resistor RT:
Fsw = 2.1MHz

MODE selection:
HIGH - Diode emulation(DCM) mode
LOW - Forced PWM(FPWM)

Size Orcad B | Number | Revision

Date: 10/01/2024 | Sheet of
File: C:\Users\..\12V_VMOT_SUPPLY.SchDocDrawn By:


Size Orcad B | Number | Revision

Date: 10/01/2024 | Sheet of
Fi l e : C: \ Users\ . . \CO OLI N G_FA N .SchDoc | Drawn By:


Rise time seto to 2.085ms

Size A4 | Number | Revision

Date: 10/01/2024 | Sheet of
File: C:\Users\..\Display_Interface.SchDoc | Drawn By:
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

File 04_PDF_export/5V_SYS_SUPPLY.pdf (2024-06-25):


LMR33630 SMPS 5V0 System Voltage Supply

Keep SW node trace as
short as possible

FB network - connect
colose to IC1 FB pin

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

Power down sequence(Indicated by INT
pin) needs to be done under 500ms(Set
by C17) by pulling KILL to LOW

LATCH System Power ON-OFF

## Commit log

2024-06-25 Initial Commit - Added: Reverse protection, 5V System supply
    [3V3_SYS_SUPPLY.SchDoc, 5V_SYS_SUPPLY.SchDoc, 6DOF_CONTROLLER.PcbDoc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]
2024-06-26 Added 3V3 System Supply and 5V0 External Supply
    [3V3_SYS_SUPPLY.SchDoc, 5V0_EXT_SUPPLY.SchDoc, 5V_SYS_SUPPLY.SchDoc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]
2024-10-01 01.10.2024 commit
    [12V_VMOT_SUPPLY.SchDoc, 3V3_MCU_SUPPLY.SchDoc, 3V3_SYS_SUPPLY.SchDoc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]
2024-10-01 Schematic PDF generated
    [6DOF_CONTROLLER.PrjPcb]
2024-10-01 Schematic PDF folder fix
2024-10-04 12V motor supply and CEC Schematic update
    [12V_VMOT_SUPPLY.SchDoc, 6DOF_CONTROLLER.PrjPcb, MOTOR_DRIVER_CEC.SchDoc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]
2025-04-23 small modigfication on current 12 schematic pages
    [12V_VMOT_SUPPLY.SchDoc, 3V3_MCU_SUPPLY.SchDoc, 3V3_SYS_SUPPLY.SchDoc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]
2025-10-17 Update README with block diagram and schematic
    Added block diagram and schematic images to README.
2025-10-17 Add Power tree section and PDF link to README
    Added a link to the Robot Brain Current Consumption PDF and a new section for Power tree.
2025-10-17 Update README with additional diagrams and documents
    Added links to block diagram and power tree documents along with images.
